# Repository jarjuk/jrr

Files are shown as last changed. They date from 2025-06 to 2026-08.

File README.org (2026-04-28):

* Nettiradio

* Valikkorakenne

#+name: plantuml2-wbs
#+BEGIN_SRC plantuml :eval no-export :exports results :file pics/jrr-menu.svg
 @startwbs
 ,* JRR
 ,**:== [[../pics-keep/screenshots/jrr-01-radio-stream.png Radio]]
 ==Näyttökentät==
,* Radiokanavan nimi
,* Radiokanavan ikoni
 ==Näppäin 1==
 ,**<U+2022><U+00A0><U+00A0>**: Seuraava radiokanava
 ,**<U+2014>** : Käynnistä asetusvalikko
 ==Näppäin 2==
 ,**<U+2022><U+00A0><U+00A0>**: Edellinen radiokanava
 ,**<U+2014>** : Ei käytössä;

,**: **Asetukset**
 ==Näppäin 1==
 ,**<U+2022><U+00A0><U+00A0>**: Seuraava valikko
 ,**<U+2014>** : Käynnistä valikkotoiminto
 ==Näppäin 2==
 ,**<U+2022><U+00A0><U+00A0>**: Edellinen valikkko
 ,**<U+2014>** : Palaa radion kuunteluun;

,***: **Poista kanavia**
 ==Näyttökentät==
,* Radiokanavan nimi
,* Radiokanavan ikoni
 ==Näppäin 1==
 ,**<U+2022><U+00A0><U+00A0>**: Seuraava radiokanava
 ,**<U+2014>** : Poista radiokanava
 ==Näppäin 2==
 ,**<U+2022><U+00A0><U+00A0>**: Edellinen radiokanava
 ,**<U+2014>** : Takaisin asetukset -valikkoon;

,***: **Aktivoi radiokanavia**
 ==Näyttökentät==
 ,* Radiokanavan nimi
 ,* Radiokanavan ikoni
 ==Näppäin 1==
 ,**<U+2022><U+00A0><U+00A0>**: Seuraava radiokanava
 ,**<U+2014>** : Aktivoi radiokanava
 ==Näppäin 2==
 ,**<U+2022>**: Edellinen radiokanava
 ,**<U+2014>** : Takaisin asetukset -valikkoon;

,***: **Valitse wifi verkko**
 ==Näyttökentät==
,* SSID: Wifi verkon SSID 
 ==Näppäin 1==
 ,**<U+2022><U+00A0><U+00A0>**: Seurava Wifi-verkko
 ,**<U+2014>** : Aktivoi Wifi-verkko
 ==Näppäin 2==
 ,**<U+2022><U+00A0><U+00A0>**: Edellinen Wifi-verkko
 ,**<U+2014>** : Takaisin asetukset -valikkoon;

,***: **Ohjelmistopäivitys**
 ==Näyttökentät==
,* Versio: Ohjelmistoversion tunniste
 ==Näppäin 1==
 ,**<U+2022><U+00A0><U+00A0>**: Seurava ohjelmistoversio
 ,**<U+2014>** : Valitse ohjelmistoversio
 ==Näppäin 2==
 ,**<U+2022><U+00A0><U+00A0>**: Edellinen ohjelmistoversio
 ,**<U+2014>** : Takaisin asetukset -valikkoon;

,****: **Ohjelmistopäivitys**
 ==Näyttökentät==
,* Versio: Ohjelmistoversion tunniste
 ==Näppäin 1==
 ,**<U+2022><U+00A0><U+00A0>**: 
 ,**<U+2014>** : Aloita päivitys
 ==Näppäin 2==
 ,**<U+2022><U+00A0><U+00A0>**
 ,**<U+2014>** : Takaisin asetukset -valikkoon;

,*****: **Uudelleen käynnistys**
 ==Näyttökentät==
,* Versio: Ohjelmistoversion tunniste
 ==Näppäin 1==
 ,**<U+2022><U+00A0><U+00A0>**: Ei käytössä
 ,**<U+2014>** : OK
 ==Näppäin 2==
 ,**<U+2022><U+00A0><U+00A0>**: Ei käytössä
 ,**<U+2014>**: Ei käytössä;

,***: **Asetukset näppäimistöllä**
----
Alivalikko ei aukea, jos
näppäimistöä ei ole kytketty 
;
,****: **Wifi-verkon valinta**
 ==Näyttökentät==
,* SSID: Wifi-verkon SSID 
 ==Näppäin 1==
 ,**<U+2022><U+00A0><U+00A0>**: Seuraava Wifi-verkko
 ,**<U+2014>** : Käynnistä Wifi -verkon asetus
 ==Näppäin 2==
 ,**<U+2022><U+00A0><U+00A0>**: Edellinen Wifi-verkko
 ,**<U+2014>** : Paluu asetusvalikkoon;
,*****: **Wifi-verkon asetus**
 ==Näyttökentät==
,* SSID: Valitun Wifi verkon SSID 
 ==Syöttökentät==
,* Password: Wifi verkon salasana
 ==Näppäin 1==
 ,**<U+2022><U+00A0><U+00A0>**: Eikäytössä
 ,**<U+2014>** : Aseta
 ==Näppäin 2==
 ,**<U+2022><U+00A0><U+00A0>**: Ei käytössä
 ,**<U+2014>** : Takaisin;
,****: **Radiokanavahakemiston asetus**
 ==Syöttökentät==
,* URL: Radiokanavahakemiston osoite (syöttökenttä)
 ==Näppäin 1==
 ,**<U+2022><U+00A0><U+00A0>**: Ei käytössä
 ,**<U+2014>** : Aseta
 ==Näppäin 2==
 ,**<U+2022><U+00A0><U+00A0>**: Ei käytössä
 ,**<U+2014>** : Takaisin;

,****: **Ohjelmistopäivityksen aloitus**
 ==Syöttökentät==
,* URL: Ohjelmistopäivityksen latausosoite
 ==Näppäin 1==
 ,**<U+2022><U+00A0><U+00A0>**: Ei käytössä
 ,**<U+2014>** : Valitse ohjelmistoversio
 ==Näppäin 2==
 ,**<U+2022><U+00A0><U+00A0>**: Ei käytössä
 ,**<U+2014>** : Paluu asetusvalikkoon;

,*****: **Ohjelmistoversion valinta ja käynnistys**
 ==Näyttökentät==
,* URL: Ohjelmistopäivityksen latausosoite
,* versio: Valittu ohjelmistoversio
 ==Näppäin 1==
 ,**<U+2022><U+00A0><U+00A0>**: Seuraava ohjelmistoversio
 ,**<U+2014>** : Käynnistä ohjelmistoversion päivitys
 ==Näppäin 2==
 ,**<U+2022><U+00A0><U+00A0>**: Edellinen ohjelmistoversio
 ,**<U+2014>** : Paluu asetusvalikkoon;

 @endwbs

#+END_SRC

#+RESULTS: plantuml2-wbs
[[file:pics/jrr-menu.svg]]

* Näytöt

** 1 - Radion kuuntelu

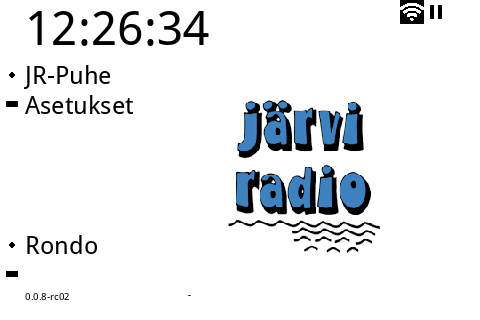
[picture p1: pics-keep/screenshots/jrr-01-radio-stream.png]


** 2 - Asetukset

*** 2.1 - Poista kanavia

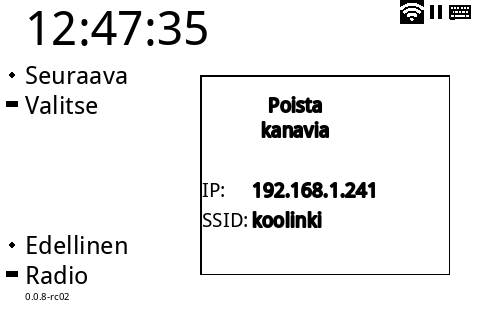
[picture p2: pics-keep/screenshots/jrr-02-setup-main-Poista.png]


*** 2.2 - Lisää kanavia

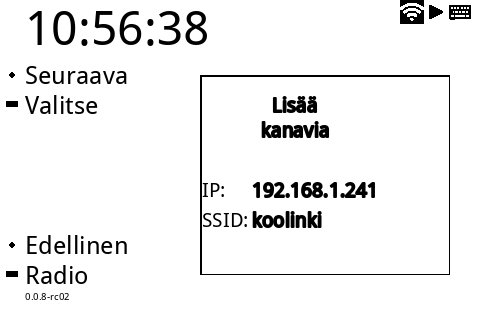
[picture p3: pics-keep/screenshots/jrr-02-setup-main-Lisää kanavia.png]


*** 2.3 - Valitse Wifi -verkko

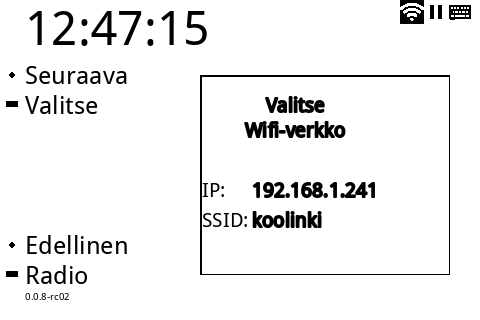
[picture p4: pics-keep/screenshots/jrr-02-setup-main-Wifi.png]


*** 2.4 - Asetukset näppämistöllä

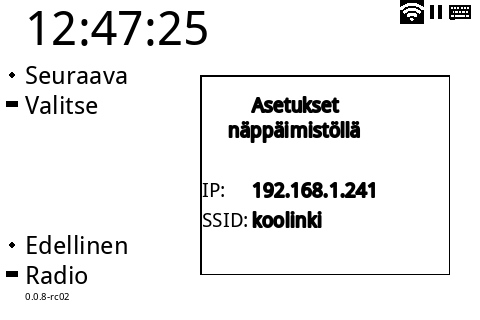
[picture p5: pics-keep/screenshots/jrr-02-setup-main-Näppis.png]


**** 2.4.1 - Wifi asetukset

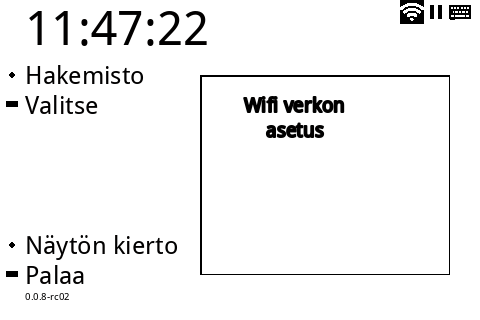
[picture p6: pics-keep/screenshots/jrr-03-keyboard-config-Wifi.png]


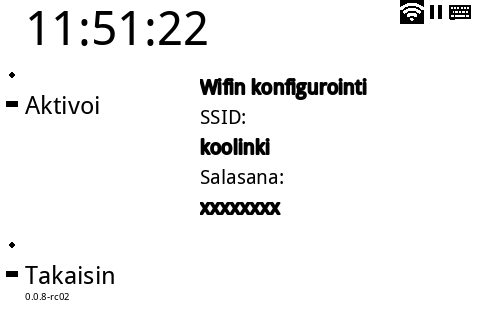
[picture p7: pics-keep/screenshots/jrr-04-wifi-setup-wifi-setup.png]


**** 2.4.2 - Radiokanavahakemiston asetukset

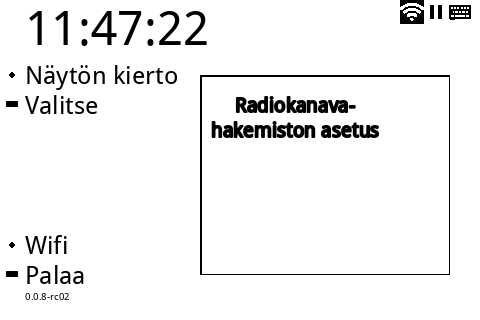
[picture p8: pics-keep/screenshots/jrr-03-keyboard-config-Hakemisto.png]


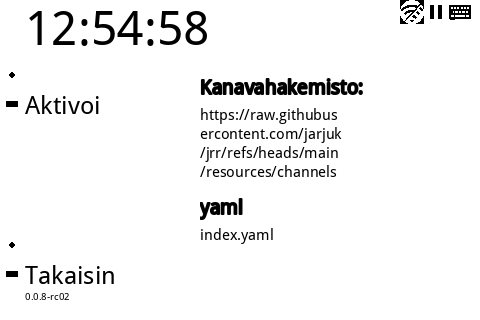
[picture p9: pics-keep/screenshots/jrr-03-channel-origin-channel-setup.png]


**** 2.4.x - Näytön kierto

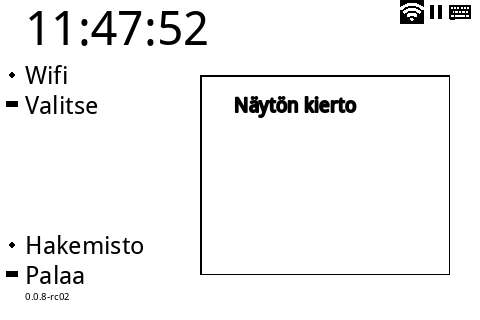
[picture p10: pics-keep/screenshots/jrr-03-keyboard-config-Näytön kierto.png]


*** 2.5. - Päivitä ohjelmistoversio

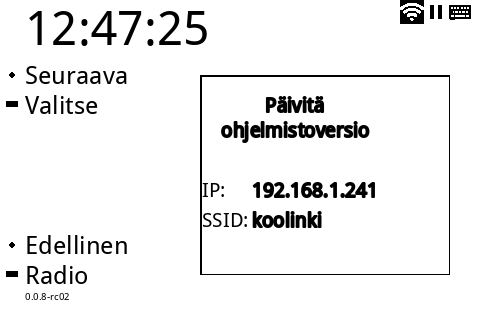
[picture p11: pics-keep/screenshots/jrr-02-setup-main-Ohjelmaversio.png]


*** 2.6. - Uudelleenkäynnistys

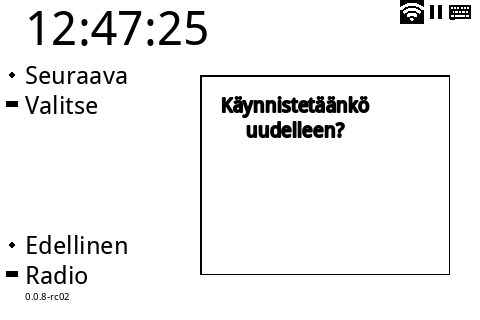
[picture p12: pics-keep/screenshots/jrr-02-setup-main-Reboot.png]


* Ohjelmistoversion palautus tehdasasetuksiin

- Paina molemmat painonapit alas ennen virtojen kytkemistä ja kytke virta radioon.

* Fin                                                              :noexport:

** Emacs variables

#+RESULTS:

# Local Variables:
# time-stamp-line-limit: -8
# time-stamp-start: "Modified:"
# time-stamp-format: "%:y-%02m-%02d.%02H:%02M"
# time-stamp-time-zone: nil
# time-stamp-end: "; # time-stamp"
# eval: (add-hook 'before-save-hook 'time-stamp)
# org-confirm-babel-evaluate: nil
# End:
#
# Muuta
# org-cdlatex-mode: t
# eval: (cdlatex-mode)
#
# Local ebib:
# org-ref-default-bibliography: "./README.bib"
# org-ref-bibliography-notes: "./README-notes.org"
# org-ref-pdf-directory: "./pdf/"
# org-ref-notes-directory: "."
# bibtex-completion-notes-path: "./README-notes.org"
# ebib-preload-bib-files: ("./README.bib")
# ebib-notes-file: ("./README-notes.org")
# reftex-default-bibliography: ("./README.bib")

Modified:2026-04-28.19:36; # time-stamp

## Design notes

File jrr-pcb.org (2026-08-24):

#+PROPERTY: header-args+ :var  DATA_SHEET_DIR="/home/jj/work/data-sheets/omat"
#+latex_compiler: pdflatex
#+LATEX_HEADER_EXTRA: \usepackage{rotfloat}
#+LATEX_HEADER_EXTRA: \usepackage{lmodern}
#+LATEX_HEADER: \hypersetup{colorlinks=true, linkcolor=blue}
#+LATEX_HEADER_EXTRA: \usepackage{tabularx}
#+LATEX_HEADER_EXTRA: \usepackage{tabu,longtable}
#+LATEX_HEADER_EXTRA: \usepackage{booktabs}
#+OPTIONS: ^:nil

* Design
** Requirements

- [-] Components
  - [-] Circuit board
    - [X] Connectors
      - [X] Power Input 5V-IN
	- [X] USB-C
	  - [X] usb-c power delivery resistor
	- [X] JST -header
      - [X] Fuse e-fuse (1.5A)
    - [X] RPI power delivery 5V
	- [X] Jumper for power deliver GPIO
	- [-] Wafer connectors  (e.g. for uUSB connector)
      - [X] 3.5 display connector 2x13
      - [ ] speaker output 
      - [X] Amplifier connectors
	- [X] power
	- [X] input signal
    - [X] button 1
    - [X] button 2
  - [-] VMA 408 amplifier breakout
    - [ ] pcb seat
      - [ ] screw hole for potentiometer
      - [ ] 4 corner holes 
    - [ ] shaft extension
    - [X] Amplifier pinhdeader
      - [X] Power input
      - [X] INput signal
      - [X] speaker output
  - [X] USB/3.5mm jack DAC
  - [X] power in
    - [X] Connectors
      - [X] USB-C power in
	- [X] Keystone inlet
      - [X] current controller resistors 5.1k x 2
      - [X] Pinheader power in
  - [ ] keyboard USB connector
    - [ ] Keystone inlet      
  - [X] power button
  - [-] Volume + on/off switch
    - [X] Pot set (pcb w. screw holes)
    - [ ] volume knob
  - [X] PLS-830986 speaker
  - [X] RCA input
    - [X] Keystone inlet
  - [-] 1P2T slide switch (RCA input/radio output)
    - [X] Keystone inlet
    - [ ] 3D printed seat
  - [ ] Cables (choose 1)
    - [ ] USB-C/JST
    - [ ] USB-C/USB-C cable (power cable)
  - [ ] polyester fibre 20g/l

** USB-C power

https://medium.com/@leung.benson/how-to-design-a-proper-usb-c-power-sink-hint-not-the-way-raspberry-pi-4-did-it-f470d7a5910

https://hackaday.com/2023/01/04/all-about-usb-c-resistors-and-emarkers/

** TRS audio connector

https://www.ranecommercial.com/legacy/note110.html

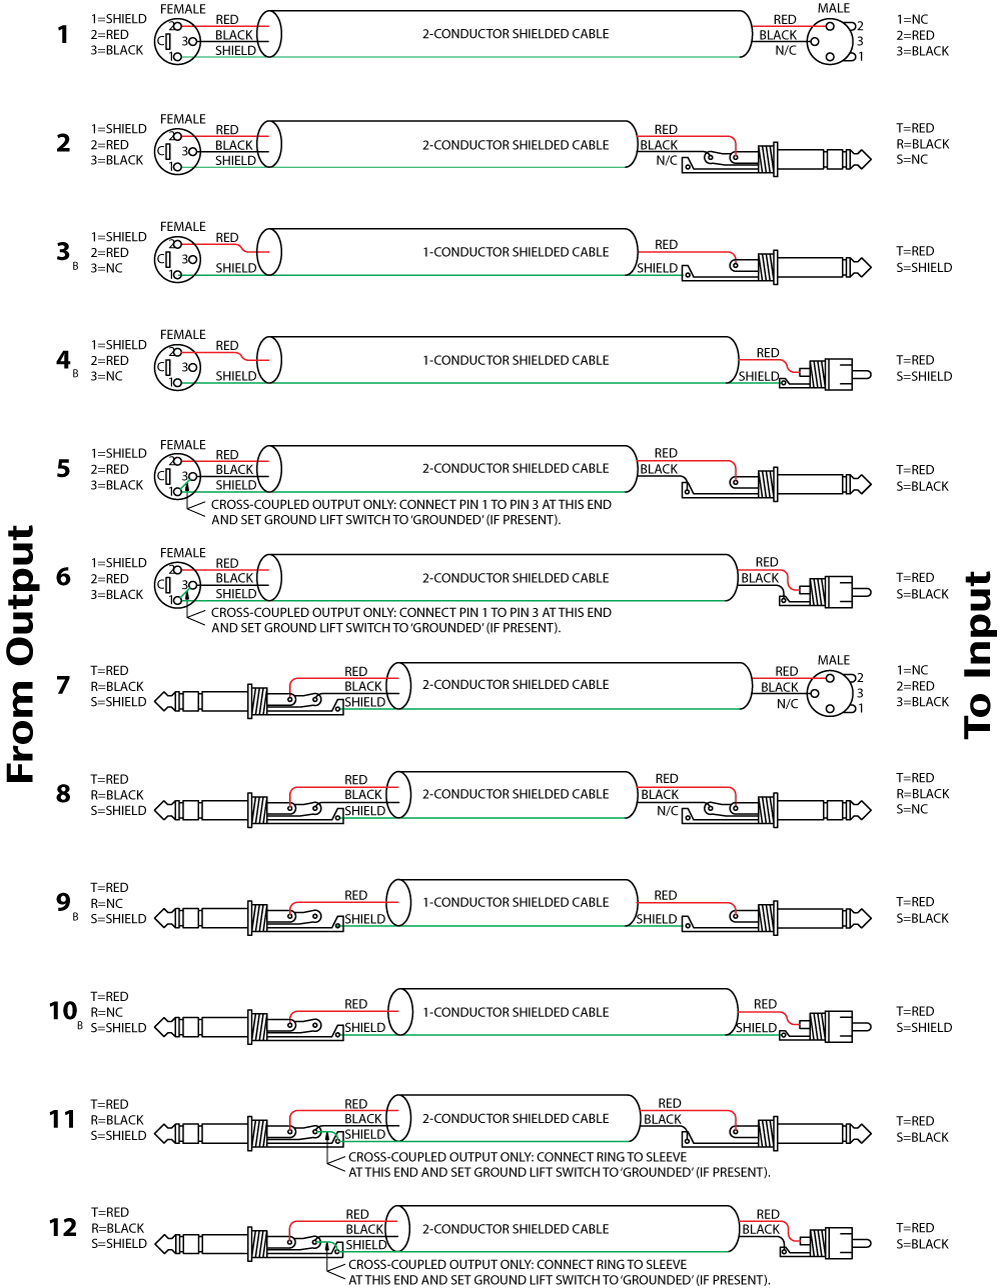
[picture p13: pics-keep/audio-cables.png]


| TSR-plug | Color  | Function      | Color | RCA-socket |
|----------+--------+---------------+-------+------------|
| T        | red    | signal        | red   | T          |
| R        | black  | signal ground | black | S          |
| S        | shield | shield        | NC    |            |

* Järviradio-radion piirilevy
:PROPERTIES:
:header-args+: :var  RELEASE="E"
:header-args+: :var  SCHEMA_ROOT="schema"
:header-args+: :var  SCHEMA_NAME="jrr5"
:header-args+: :var  DOC=(file-name-base (buffer-file-name))
:END:

** Piirilevyn skeema

    #+BEGIN_SRC bash :eval no-export :results output :exports results
    echo SCHEMA_ROOT=$SCHEMA_ROOT
    echo SCHEMA_NAME=$SCHEMA_NAME
    echo RELEASE=$RELEASE
    #+END_SRC

    #+RESULTS:
    : SCHEMA_ROOT=schema
    : SCHEMA_NAME=jrr5
    : RELEASE=E

    #+call:kicad-project()

    #+RESULTS:

    #+call: kicad-schema-pic()

    #+RESULTS:
    [[file:pics/jrr5.pdf]]

** Kotelon suunnittelu
*** Piirilevyn mitoitus

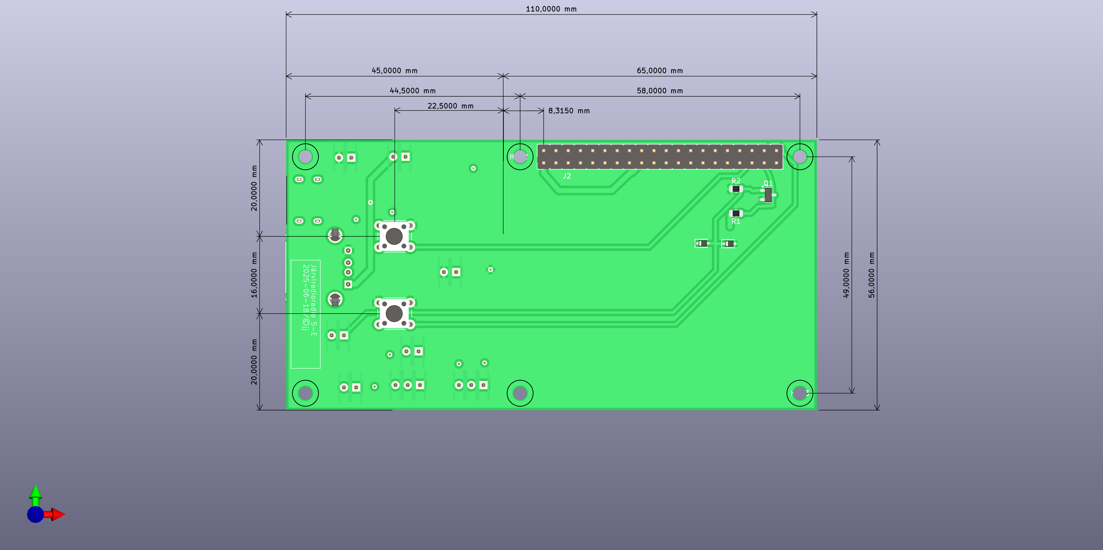
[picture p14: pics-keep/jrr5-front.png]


*** Painonappien etäisyys näyttöupotuksen reunoista

#+BEGIN_SRC octave :eval no-export :results output :session *Octave* :exports both

  mm = 1;

  pin2edge=8.315;
  edge2button = 22.5;

  hdr_slot_tol = 1+0.5;

  hdr_slot2button =  edge2button + pin2edge  - hdr_slot_tol

  #+END_SRC   

  #+RESULTS:
  : hdr_slot2button = 29.315

*** Kotelon katon aukot

[[file:cad/pages/katto.pdf]]

** PCB Layout

*** Front


*** Back



** BOM

#+call: kicad-bom(BOM_COLS="Reference,Value,Footprint,${QUANTITY}")

#+NAME: BOM
#+CAPTION: Järviradio PCB BOM
#+ATTR_LATEX: :float sideways :placement [H]
#+ATTR_LATEX: :font \tiny
#+HEADER: :exports results :results table latex :colnames yes
| Reference                    | Value                     | Footprint                                                  | QUANTITY |
|------------------------------+---------------------------+------------------------------------------------------------+----------|
| CONN1                        | 3.5m_TRS                  |                                                            |        1 |
| CONNN1                       | CONN-KSTONE-USBAfmxUSBAfm |                                                            |        1 |
| CONNN2                       | CONN-KSTONE-USBCfmxUSBCfm |                                                            |        1 |
| D1,D2                        | Schottky,15mA             | PCM_JLCPCB:D_SOD-323                                       |        2 |
| J2                           | Raspberry_Pi_2_3_GPIO     | Connector_PinHeader_2.54mm:PinHeader_2x20_P2.54mm_Vertical |        1 |
| J4                           | USB-Afm,THT               | Connector_USB:USB_A_Molex_67643_Horizontal                 |        1 |
| J11,J13,J19,J21,J24,J28,J101 | Wafer,1x2,m               | jj-foot:Wafer_1x02_P2.54mm_Vertical_male                   |        7 |
| J18,J26                      | Wafer,1x3,m               | jj-foot:Wafer_1x03_P2.54mm_Vertical_male                   |        2 |
| J107,J110                    | Wafer,1x2,fm              | Connector_PinHeader_2.54mm:PinHeader_1x02_P2.54mm_Vertical |        2 |
| J109                         | Wafer,1x3,fm              |                                                            |        1 |
| Q1                           | BSS138                    | Package_TO_SOT_SMD:SOT-23                                  |        1 |
| R1,R2                        | 10k                       | Resistor_SMD:R_0805_2012Metric                             |        2 |
| R3,R4                        | 5k1                       | Resistor_SMD:R_0805_2012Metric                             |        2 |
| SW1,SW2                      | SW_PUSH_THT_6mm           | Button_Switch_THT:SW_PUSH_6mm                              |        2 |

#+call: kicad-2d(LAYERS="Edge.Cuts,User.Drawings,F.Silkscreen,F.Fab,F.Paste", IMAGE_FILE="pics/jrr5-fab_f.png")

#+RESULTS:


#+call: kicad-2d(LAYERS="Edge.Cuts,User.Drawings,B.Silkscreen,B.Fab,B.Paste", IMAGE_FILE="pics/jrr5-fab_b.png")

#+RESULTS:


** Fab

#+BEGIN_SRC bash :eval no-export :results output
echo "Running in $(pwd) host '$(hostname)' on $(date)"
echo "SCHEMA_ROOT=$SCHEMA_ROOT"
echo "SCHEMA_NAME=$SCHEMA_NAME"
echo "RELEASE=$RELEASE"

#+END_SRC

#+RESULTS:
: Running in /home/jj/work/jrr host 'eero' on ma 7.7.2025 13.41.58 +0300
: SCHEMA_ROOT=schema
: SCHEMA_NAME=jrr5
: RELEASE=E

#+call: kicad-fab()

#+RESULTS:
#+begin_example
Running in /home/jj/work/jrr host 'eero' on ma 7.7.2025 13.53.40 +0300

Creating pdf for pcb layers in SCHEMA_NAME=jrr5

- LAYERS=B.Fab,Edge.Cuts,User.Comments,User.Drawings
- SCHEMA_ROOT=schema ('panels' or 'schema')
- PCB desing PCB_FILE=schema/jrr5/jrr5.kicad_pcb in PCB_DIR=schema/jrr5
- Images in IMAGE_PDF=pics/fab.pdf

Using IMAGE_DIR=
Loading board
Done OK
#+end_example

** Gerbers

#+BEGIN_SRC bash :eval no-export :results output
echo "Running in $(pwd) host '$(hostname)' on $(date)"
echo "SCHEMA_ROOT=$SCHEMA_ROOT"
echo "SCHEMA_NAME=$SCHEMA_NAME"
echo "RELEASE=$RELEASE"

#+END_SRC

#+RESULTS:
: Running in /home/jj/work/jrr host 'eero' on ma 23.6.2025 11.19.44 +0300
: SCHEMA_ROOT=schema
: SCHEMA_NAME=jrr5
: RELEASE=E

#+call: kicad-gerber()

#+RESULTS:
#+begin_example
Running in /home/jj/work/jrr host 'eero' on ma 23.6.2025 11.59.57 +0300

Creating gerber zip file ZIP_FILE=schema/jrr5/jrr5-E.zip for default SCHEMA_NAME=jrr5

- SCHEMA_ROOT=schema ('panels' or 'schema')
- PCB desing PCB_FILE=schema/jrr5/jrr5.kicad_pcb in PCB_DIR=schema/jrr5
- Gerbers in GERBER_DIR=schema/jrr5/gerber
- Zip file ZIP_FILE=schema/jrr5/jrr5-E.zip

Using GERBER_DIR=schema/jrr5/gerber
Loading board
Plotted to 'schema/jrr5/gerber/jrr5-F_Cu.gtl'.
Plotted to 'schema/jrr5/gerber/jrr5-B_Cu.gbl'.
Plotted to 'schema/jrr5/gerber/jrr5-F_Paste.gtp'.
Plotted to 'schema/jrr5/gerber/jrr5-B_Paste.gbp'.
Plotted to 'schema/jrr5/gerber/jrr5-F_Silkscreen.gto'.
Plotted to 'schema/jrr5/gerber/jrr5-B_Silkscreen.gbo'.
Plotted to 'schema/jrr5/gerber/jrr5-F_Mask.gts'.
Plotted to 'schema/jrr5/gerber/jrr5-B_Mask.gbs'.
Plotted to 'schema/jrr5/gerber/jrr5-User_Comments.gbr'.
Plotted to 'schema/jrr5/gerber/jrr5-Edge_Cuts.gm1'.
Loading board
Created file 'schema/jrr5/gerber/jrr5.drl'
Created file 'schema/jrr5/gerber/jrr5-drl_map.pdf'.
Done.
  adding: schema/jrr5/gerber/ (stored 0%)
  adding: schema/jrr5/gerber/jrr5-F_Paste.gtp (deflated 59%)
  adding: schema/jrr5/gerber/jrr5-B_Silkscreen.gbo (deflated 83%)
  adding: schema/jrr5/gerber/jrr5-drl_map.pdf (deflated 12%)
  adding: schema/jrr5/gerber/jrr5-B_Paste.gbp (deflated 65%)
  adding: schema/jrr5/gerber/jrr5-F_Mask.gts (deflated 72%)
  adding: schema/jrr5/gerber/jrr5-F_Cu.gtl (deflated 74%)
  adding: schema/jrr5/gerber/jrr5-B_Cu.gbl (deflated 75%)
  adding: schema/jrr5/gerber/jrr5.drl (deflated 65%)
  adding: schema/jrr5/gerber/jrr5-F_Silkscreen.gto (deflated 83%)
  adding: schema/jrr5/gerber/jrr5-Edge_Cuts.gm1 (deflated 39%)
  adding: schema/jrr5/gerber/jrr5-B_Mask.gbs (deflated 73%)
  adding: schema/jrr5/gerber/jrr5-User_Comments.gbr (deflated 67%)
  adding: schema/jrr5/gerber/jrr5-job.gbrjob (deflated 73%)
Done OK
#+end_example

** Release management
*** Releases

   |-----------+-----+-----------------+-----|
   |      Date | Rel | Comments        | PCB |
   |-----------+-----+-----------------+-----|
   |  4.2.2025 | C   | First version   | X   |
   | 19.2.2025 | D   | JRR-{1,2,3,4,5} | X   |
   |-----------+-----+-----------------+-----|

*** Release Issues

#+ATTR_LATEX: :font \tiny
   |--------+--------------+-----------+---------+------------------------------+------------------------------|
   | #      | In Rel       | Fixed rel | Ref     | As-is                        | Tobe                         |
   |--------+--------------+-----------+---------+------------------------------+------------------------------|
   | JRR-1  | C            | D         | F1      | 1.5A                         | 1.1A,SMD,polyfuse            |
   | JRR-2  | C            | D         | F1      |                              | 1812 footprint               |
   | JRR-3  | C            | D         | Q1      | drain 3 = GND, source 2= out | source 2 = GND, drain 3= out |
   | JRR-4  | C            | D         | Conn    | footprint pinhder            | wafer pinheader              |
   | JRR-5  | C            | D         | Edgecut | to righ                      | to left                      |
   | JRR-6  | D            |           | Q1      | BSS138->DMN3042L-7           |                              |
   | JRR-7  | D            | E         | Q1      |                              | schottky x 2                 |
   | JRR-8  | D            |           |         | +Mounting holes placement+   |                              |
   | JRR-9  | D            | E         |         | Silkscreen text              | Using macros                 |
   | JRR-10 | D            | E         | SW{1,2} | Push buttons to left 15 mm   |                              |
   | JRR-11 | E            |           | D1, D2  | pads too small               | +0.5 mm w, +.0.5 extend out  |
   | JRR-12 | E            |           | H{1-6}  | Hole diameter 2.5mm          | --> 4mm                      |
   | JRR-13 | 23.3./2026/E |           |         | Mounting holes too small     | M3.5mm                       |
   | JRR-14 | E            | F         | R1,R2   | 100k                         | 10k                          |
   | JRR-15 | E            |           | D1, D2  | Small pads                   | Increase pad size            |
   | JRR-16 | E            |           | D1, D2  | MPN missing                  | Add MNP                      |
   | JRR-17 | E            |           | F1      | 1.1A                         | 0.75A/PTS181213V075          |
   | JRR-18 | E            |           | J24     | Amp-power                    | on PCB edge                  |
   | JRR-19 | E            |           | C??     | 100uF Cap                    | on 5V-RPI/GND                |
   | JRR-20 | E            |           | Rxx     | <1R Resistro                 | on 5V-RPI                    |
   |--------+--------------+-----------+---------+------------------------------+------------------------------|

*** Deploy ~DATA_SHEET_DIR/DOC-RELEASE.pdf~                        :noexport:
  #+BEGIN_SRC bash :eval no-export :results output
  echo RELEASE=$RELEASE
  echo DATA_SHEET_DIR=$DATA_SHEET_DIR
  echo SCHEMA_NAME=$SCHEMA_NAME
  echo DOC=$DOC
  #+END_SRC

  #+RESULTS:
  : RELEASE=D
  : DATA_SHEET_DIR=/home/jj/work/data-sheets/omat
  : SCHEMA_NAME=jrr5
  : DOC=jrr5-pcb

  #+BEGIN_SRC bash :eval no-export :results output
  ls -ltr $DATA_SHEET_DIR/$DOC* ; true
  #+END_SRC

  #+RESULTS:
  : -rw-rw-r-- 1 jj jj 668631 helmi   6 15:00 /home/jj/work/data-sheets/omat/jrr5-pcb-jrr5-A.pdf
  : -rw-rw-r-- 1 jj jj 668631 helmi   6 15:02 /home/jj/work/data-sheets/omat/jrr5-pcb-jrr5-C.pdf
  : -rw-rw-r-- 1 jj jj 634648 helmi  19 10:05 /home/jj/work/data-sheets/omat/jrr5-pcb-jrr5-D.pdf

  Export to pdf
  #+BEGIN_SRC elisp
  (org-latex-export-to-pdf)
  #+END_SRC

  #+RESULTS:
  : /home/jj/work/järviradio-radio/jrr5-pcb.pdf

  Show pdf
  #+BEGIN_SRC bash :eval no-export :results output
  ls -ltr $DOC.pdf
  #+END_SRC

  #+RESULTS:
  : -rw-rw-r-- 1 jj jj 634648 helmi  19 10:05 jrr5-pcb.pdf

  Copy exported pdf as ~${RELEASE}~ -version to ~$DATA_SHEET_DIR~.
  #+BEGIN_SRC bash :eval no-export :results output file
  TARGET=$DATA_SHEET_DIR/${DOC}-${SCHEMA_NAME}-${RELEASE}.pdf
  cp $DOC.pdf $TARGET 
  echo -n $TARGET 
  #+END_SRC

  #+RESULTS:
  [[file:/home/jj/work/data-sheets/omat/jrr5-pcb-jrr5-D.pdf]]

  Datasheets installed into directory: 
  #+BEGIN_SRC bash :eval no-export :results output file :exports results
  echo -n $DATA_SHEET_DIR
  #+END_SRC

  #+RESULTS:
  [[file:/home/jj/work/data-sheets/omat]]

  #+BEGIN_SRC bash :eval no-export :results output
  ls -lt $DATA_SHEET_DIR/${DOC}-*.pdf $DOC.org   $DOC.pdf
  #+END_SRC

  #+RESULTS:
  : -rw-rw-r-- 1 jj jj  11287 helmi   6 15:02 jrr5-pcb.org
  : -rw-rw-r-- 1 jj jj 668631 helmi   6 15:02 /home/jj/work/data-sheets/omat/jrr5-pcb-jrr5-C.pdf
  : -rw-rw-r-- 1 jj jj 668631 helmi   6 15:02 jrr5-pcb.pdf
  : -rw-rw-r-- 1 jj jj 668631 helmi   6 15:00 /home/jj/work/data-sheets/omat/jrr5-pcb-jrr5-A.pdf

* Admin

** Kicad
*** ~kicad-bom~: Create bom table for SCHEMA_NAME

#+name: kicad-bom
#+BEGIN_SRC bash :eval no-export :results table :exports results :var SCHEMA_NAME="bolo-clock" SCHEMA_ROOT="schema" BOM_COLS="Reference,Value,Footprint,${QUANTITY}"
CSV_FILE=$SCHEMA_ROOT/$SCHEMA_NAME/$SCHEMA_NAME.csv

#           --filter '${EXCLUDE_FROM_BOM}' \

cat <<HERE >&2
Running in $(pwd) host '$(hostname)' on $(date)

Parameters
- BOM_COLS[comma serated list of columsn]=${BOM_COLS}

Output:
- CSV_FILE=$SCHEMA_ROOT/$SCHEMA_NAME/$SCHEMA_NAME.csv 
HERE

# --preset "Grouped By Value" \
#          --fields ${BOM_COLS} \
#          --exclude-dnp \

kicad-cli sch export bom \
          --output $CSV_FILE \
          --field-delimiter "|" \
          --string-delimiter "" \
          --group-by "Value" \
          --fields ${BOM_COLS} \
          schema/$SCHEMA_NAME/$SCHEMA_NAME.kicad_sch \
          >/dev/null # &2\
          
# echo '#+ATTR_LATEX: :font \tiny'
cat $CSV_FILE
#+END_SRC

#+RESULTS: kicad-bom

*** ~kicad-project~: Open project SCHEMA_NAME under SCHEMA_ROOT

    #+name: kicad-project
    #+BEGIN_SRC elisp :eval no-export :noweb yes :results output :eval no-export :exports none :var SCHEMA_ROOT="schema"
    (start-process "server" "buf-server" "kicad" (concat "schema/" SCHEMA_NAME "/" SCHEMA_NAME  ".kicad_pro"))
    #+END_SRC

*** ~kicad-schema~: Open schema designer SCHEMA_NAME under SCHEMA_ROOT

    #+name: kicad-schema
    #+BEGIN_SRC elisp :eval no-export :noweb yes :results output :eval no-export :exports none :var SCHEMA_ROOT="schema"
    (start-process "server" "buf-server" "eeschema" (concat "schema/" SCHEMA_NAME "/" SCHEMA_NAME  ".kicad_sch"))
    #+END_SRC

*** ~kicad-schema-pic~: Create schema pdf for SCHEMA_NAME under SCHEMA_ROOT

#+name: kicad-schema-pic
#+BEGIN_SRC bash :eval no-export :results file :var SCHEMA_ROOT="schema"
echo "Running in $(pwd) host '$(hostname)' on $(date)" >&2
echo "SCHEMA_ROOT=$SCHEMA_ROOT, SCHEMA_NAME=$SCHEMA_NAME" >&2
PDF_FILE=pics/$SCHEMA_NAME.pdf
          # --black-and-white \
kicad-cli sch export pdf \
          --output  $PDF_FILE \
          $SCHEMA_ROOT/$SCHEMA_NAME/$SCHEMA_NAME.kicad_sch >/dev/null

echo -n $PDF_FILE
#+END_SRC

*** ~kicad-gerber~: Create gerber zip for SCHEMA_NAME-RELEASE under SCHEMA_ROOT or

#+name: kicad-gerber
#+BEGIN_SRC bash :eval no-export :results output :var RELEASE="A" SCHEMA_ROOT="schema"
PCB_DIR=$SCHEMA_ROOT/$SCHEMA_NAME
PCB_FILE=$PCB_DIR/$SCHEMA_NAME.kicad_pcb
GERBER_DIR=$SCHEMA_ROOT/$SCHEMA_NAME/gerber
ZIP_FILE=$SCHEMA_ROOT/$SCHEMA_NAME/$SCHEMA_NAME-$RELEASE.zip
cat <<HERE
Running in $(pwd) host '$(hostname)' on $(date)

Creating gerber zip file ZIP_FILE=$ZIP_FILE for default SCHEMA_NAME=$SCHEMA_NAME

- SCHEMA_ROOT=$SCHEMA_ROOT ('panels' or 'schema')
- PCB desing PCB_FILE=$PCB_FILE in PCB_DIR=$PCB_DIR
- Gerbers in GERBER_DIR=$GERBER_DIR

HERE

if [ ! -d $GERBER_DIR ]; then
    echo No such directory GERBER_DIR=$GERBER_DIR - creating it
    mkdir -p $GERBER_DIR
fi

# cleanup
rm -f $GERBER_DIR/*
rm -f $ZIP_FILE

echo Using GERBER_DIR=$GERBER_DIR
kicad-cli pcb export gerbers \
          --output $GERBER_DIR \
          --layers 'F.Cu,B.Cu,F.Paste,B.Paste,F.Silkscreen,B.Silkscreen,F.Mask,B.Mask,Edge.Cuts,User.Comments' \
          $PCB_FILE
kicad-cli pcb export drill \
          --output $GERBER_DIR \
          --generate-map \
          $PCB_FILE
zip -r $ZIP_FILE $GERBER_DIR
echo Done OK
#+END_SRC

*** ~kicad-fab~: Create gerber zip for SCHEMA_NAME-RELEASE under SCHEMA_ROOT or

#+name: kicad-fab
#+BEGIN_SRC bash :eval no-export :results output :var RELEASE="A" SCHEMA_ROOT="schema"
PCB_DIR=$SCHEMA_ROOT/$SCHEMA_NAME
PCB_FILE=$PCB_DIR/$SCHEMA_NAME.kicad_pcb
LAYERS="B.Fab,Edge.Cuts,User.Comments,User.Drawings"
IMAGE_PDF=pics/fab.pdf
cat <<HERE
Running in $(pwd) host '$(hostname)' on $(date)

Creating pdf for pcb layers in SCHEMA_NAME=$SCHEMA_NAME

- LAYERS=$LAYERS
- SCHEMA_ROOT=$SCHEMA_ROOT ('panels' or 'schema')
- PCB desing PCB_FILE=$PCB_FILE in PCB_DIR=$PCB_DIR
- Images in IMAGE_PDF=$IMAGE_PDF

HERE

# cleanup

echo Using IMAGE_DIR=$IMAGE_DIR
kicad-cli pcb export pdf \
          --output $IMAGE_PDF \
          --layers $LAYERS \
          $PCB_FILE
echo Done OK
#+END_SRC

*** ~kicad-2d~: Create 2d image NAME for SCHEMA_ROOT/SCHEMA_NAME for LAYERS

#+name: kicad-2d
#+BEGIN_SRC bash :eval no-export :results output file :var LAYERS="Edge.Cuts,User.Drawings,F.Silkscreen,F.Fab,F.Paste" SCHEMA_ROOT="schema" SCHEMA_NAME="myclock" NAME=""
  echo "Running in $(pwd) host '$(hostname)' on $(date)" 1>&2
  SCHEMA_FILE=$SCHEMA_ROOT/$SCHEMA_NAME/$SCHEMA_NAME.kicad_pcb
  GERBER_FILE=pics/${SCHEMA_NAME}.grb
  [[ -z "$IMAGE_FILE" ]] && IMAGE_FILE=pics/${SCHEMA_NAME}${NAME:+-}${NAME:=}.png
  echo "LAYERS=$LAYERS" 1>&2
  echo "SCHEMA_ROOT=$SCHEMA_ROOT" 1>&2
  echo "SCHEMA_NAME=$SCHEMA_NAME" 1>&2
  echo "SCHEMA_FILE=$SCHEMA_FILE" 1>&2
  echo "IMAGE_FILE=$IMAGE_FILE" 1>&2

  kicad-cli pcb export gerber \
            --output $GERBER_FILE \
            --layers "$LAYERS" \
            $SCHEMA_FILE 1>&2

  gerbv \
      --dpi=600 \
      --border=0 \
      --export=png \
      --background=#FFFFFF --foreground=#000000 \
      --output=$IMAGE_FILE $GERBER_FILE
  echo -n $IMAGE_FILE
#+END_SRC

* Fin                                                              :noexport:

** Emacs variables

#+RESULTS:

# Local Variables:
# time-stamp-line-limit: -8
# time-stamp-start: "Modified:"
# time-stamp-format: "%:y-%02m-%02d.%02H:%02M"
# time-stamp-time-zone: nil
# time-stamp-end: "; # time-stamp"
# eval: (add-hook 'before-save-hook 'time-stamp)
# org-confirm-babel-evaluate: nil
# End:
#
# Muuta
# org-cdlatex-mode: t
# eval: (cdlatex-mode)
#
# Local ebib:
# org-ref-default-bibliography: "./jrr5-pcb.bib"
# org-ref-bibliography-notes: "./jrr5-pcb-notes.org"
# org-ref-pdf-directory: "./pdf/"
# org-ref-notes-directory: "."
# bibtex-completion-notes-path: "./jrr5-pcb-notes.org"
# ebib-preload-bib-files: ("./jrr5-pcb.bib")
# ebib-notes-file: ("./jrr5-pcb-notes.org")
# reftex-default-bibliography: ("./jrr5-pcb.bib")

Modified:2026-08-24.10:47; # time-stamp

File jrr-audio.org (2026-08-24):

* Suunnittelun lähtötiedot

[[https://loudspeakerdatabase.com/Simulators/ClosedBox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][Loudspeakerdatabase suunnnitelma]]

* Mittausjärjestelyt

** Mittauskohteet

- jrr5x1.local
  - Kaiutinelementti: [[file:bom/peerless-830986.pdf][PLS-P830986]]
  - DA-muunnin: Realtek ALC5686
  - Vahvistin: PAM8403-GF1002 2x3W [[https://uraltone.com/vahvistinmoduli-pam8403-class-d-2x3w.html][Uraltone 190-PAM8403-2x3W-AMP]]
  - suljettu kotelo LxKxS: 232mm x x 138mm xx 138mm 19mm MDF
  - n. 10mm vanu kotelon sisällä
- jrr5x.local
  - Kaiutinelementti: [[file:bom/peerless-830986.pdf][PLS-P830986]] 
  - Vahvistin: PAM8403-GF1002 2x3W [[https://uraltone.com/vahvistinmoduli-pam8403-class-d-2x3w.html][Uraltone 190-PAM8403-2x3W-AMP]]
  - DA-muunnin: Realtek ALC5686
  - suljettu kotelo LxKxS: 232mm x x 138mm xx 138mm 19mm MDF
- jrr4.local
  - Kaiutinelementti: [[file:bom/peerless-830986.pdf][PLS-P830986]] 
  - DA-muunnin: Raspberry Pi 3B+ 3.5mm audio jack PWM
  - Vahvistin: Velleman VMA408 (PAM8403)
  - suljettu kotelo LxKxS: 232mm x x 138mm xx 138mm 19mm MDF

** Mittausympäristö
- Mikrofoni T-Bone SC 400
  - Käyttöohje: [[file:bom/t-bone-sc400-microphone.pdf]]
  - n. 10 cm suoraan kaiuttimien edessä
- Äänikortti: Behringer UMC202HD
  - 2x2, 24-Bit/192 kH
  - Kotisivu: https://www.behringer.com/en/products/0805-AAR
  - Pikaohje: [[file:bom/Behringer-U-PHORIA-Series_WW.pdf]]
- Analyysohjelmisto REW
  - Versio 5.31.3, JRE 1.8.0_422 64-bit on linx 6.17.0-1028-oem

* Mittaukset

** jrr4
:PROPERTIES:
:header-args+: :var  AUDIO_TARGET_SSH="pi@jrr4.local"
:header-args+:   :dir  /ssh:pi@jrr4.local:
:END:

*** Testiympäristön alustus
#+BEGIN_SRC bash :eval no-export :results output
echo "Running in $(pwd) for user '$(whoami)' on host '$(hostname)' on $(date)"
echo AUDIO_TARGET_SSH=$AUDIO_TARGET_SSH
#+END_SRC

#+RESULTS:
: Running in /home/pi for user 'pi' on host 'jrr4' on Mon Jul 27 09:44:14 EEST 2026
: AUDIO_TARGET_SSH=pi@jrr4.local

#+call: create-dir(DIR="tmp")

#+RESULTS:
: Create DIR=tmp in /home/pi for user 'pi' on host='jrr4' on Mon Jul 27 09:45:31 EEST 2026
: Directory tmp already exists

Kopioidaa audio tiedostot
#+call: audio-analysis-copy[:dir .](AUDIO_FILE="audio/*")

#+RESULTS:
: Running in /home/jj/work/jrr for user 'jj' on host 'Leo' on ma 27.7.2026 09.47.21 +0300

Kohdejärjestelmässä olevat äänitiedostot
#+call: audio-analysis-playable()

#+RESULTS:
#+begin_example
Running in /home/pi for user 'pi' on host 'jrr4' on Mon Jul 27 09:48:04 EEST 2026
-rw-r--r-- 1 pi pi 4718636 Jul 27 09:47 tmp/256kMeasSweep_100_to_15000_-12_dBFS_48k_Float_LR_refL.wav
-rw-r--r-- 1 pi pi 4718636 Jul 27 09:47 tmp/256kMeasSweep_100_to_20000_-12_dBFS_48k_Float_LR_refL.wav
-rw-r--r-- 1 pi pi 4718636 Jul 27 09:47 tmp/256kMeasSweep_100_to_5000_-12_dBFS_48k_Float_LR_refL.wav
-rw-r--r-- 1 pi pi 4718636 Jul 27 09:47 tmp/256kMeasSweep_20_to_20000_-12_dBFS_48k_Float_LR_refL.wav
-rw-r--r-- 1 pi pi 4718636 Jul 27 09:47 tmp/256kMeasSweep_50_to_20000_-12_dBFS_48k_Float_LR_refL.wav
-rw-r--r-- 1 pi pi 3840044 Jul 27 09:47 tmp/LinSwp_10_20000_-12_dBFS_48k_Float_LR.wav
-rw-r--r-- 1 pi pi 3840044 Jul 27 09:47 tmp/Sine_1000_-12_dBFS_48k_Float_LR.wav
-rw-r--r-- 1 pi pi 3840044 Jul 27 09:47 tmp/Sine_100_-12_dBFS_48k_Float_LR.wav
-rw-r--r-- 1 pi pi 3840044 Jul 27 09:47 tmp/Sine_200_-12_dBFS_48k_Float_LR.wav
-rw-r--r-- 1 pi pi 3840044 Jul 27 09:47 tmp/Sine_30_-12_dBFS_48k_Float_LR.wav
-rw-r--r-- 1 pi pi 3840044 Jul 27 09:47 tmp/Sine_500_-12_dBFS_48k_Float_LR.wav
-rw-r--r-- 1 pi pi 3840044 Jul 27 09:47 tmp/Sine_50_-12_dBFS_48k_Float_LR.wav
-rw-r--r-- 1 pi pi 3840044 Jul 27 09:47 tmp/Sine_75_-12_dBFS_48k_Float_LR.wav
#+end_example

Pysäytetään streamaus palvelus

#+BEGIN_SRC bash :eval no-export :results output
echo "Running in $(pwd) for user '$(whoami)' on host '$(hostname)' on $(date)"
# jrr-control.sh stop
runner/jrr-control.sh stop
#+END_SRC

#+RESULTS:
: Running in /home/pi for user 'pi' on host 'jrr4' on Tue Jul 28 09:03:14 EEST 2026

*** Linear sweep 20Hz-20kHz -12dBFS 48k LR
:PROPERTIES:
:header-args+: :var  AUDIO_FILE="audio/256kMeasSweep_20_to_20000_-12_dBFS_48k_Float_LR_refL.wav"
:END:

#+BEGIN_SRC bash :eval no-export :results output
echo "Running in $(pwd) for user '$(whoami)' on host '$(hostname)' on $(date)"
echo "AUDIO_FILE=$AUDIO_FILE"
#+END_SRC

#+RESULTS:
: Running in /home/pi for user 'pi' on host 'jrr4' on Mon Jul 27 10:14:09 EEST 2026
: AUDIO_FILE=audio/256kMeasSweep_20_to_20000_-12_dBFS_48k_Float_LR_refL.wav

#+call: vlc-play()

#+RESULTS:
: Running in /home/pi for user 'pi' on host 'jrr4' on Mon Jul 27 10:19:26 EEST 2026
: AUDIO_FILE_TO_PLAY=tmp/256kMeasSweep_20_to_20000_-12_dBFS_48k_Float_LR_refL.wav
: cvlc --play-and-exit tmp/256kMeasSweep_20_to_20000_-12_dBFS_48k_Float_LR_refL.wav
: VLC media player 3.0.10 Vetinari (revision 3.0.10-0-g7f145afa84)
: [[32;1m00d010d0[0m] main interface error: [31;1mno suitable interface module[0m
: [[32;1m00c7a6c0[0m] main libvlc error: [31;1minterface "globalhotkeys,none" initialization failed[0m
: [[32;1m00d010d0[0m] dummy interface: [0;1musing the dummy interface module...[0m
: [[32;1m00ce5268[0m] main playlist: [0;1mend of playlist, exiting[0m

*** SPL

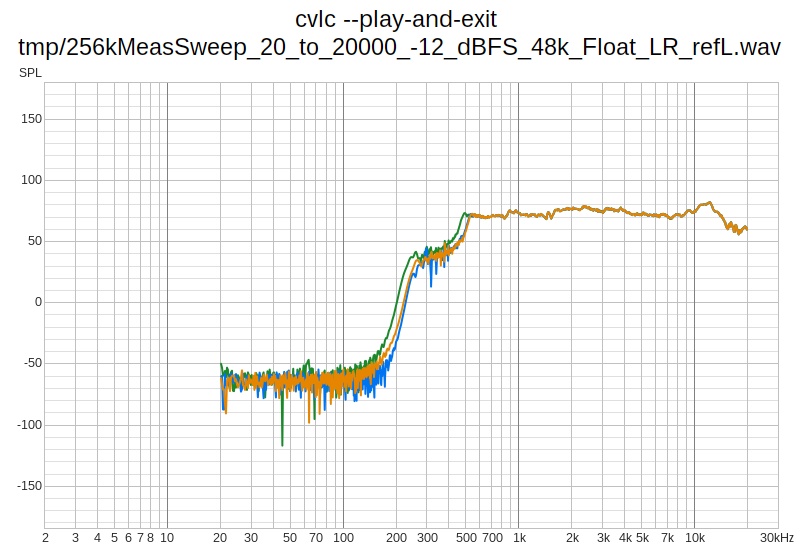
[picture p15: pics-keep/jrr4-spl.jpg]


*** Distortion

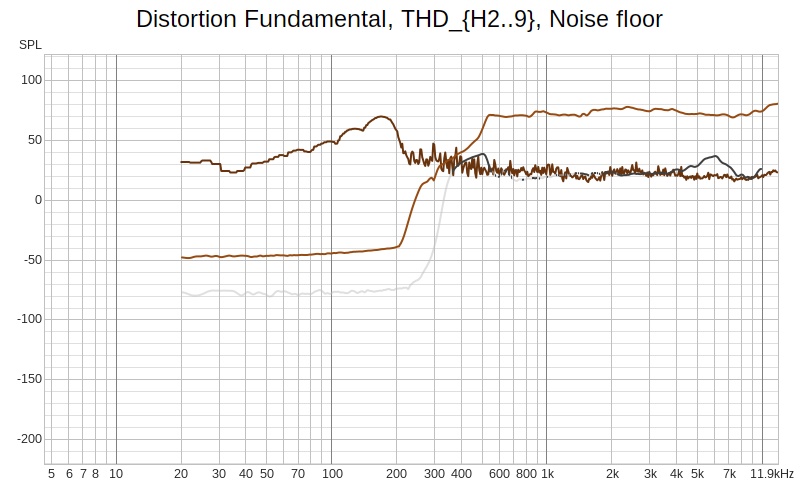
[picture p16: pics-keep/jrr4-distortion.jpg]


** jrr5x1
:PROPERTIES:
:header-args+: :var  AUDIO_TARGET_SSH="jrr@jrr5x1.local"
:header-args+:   :dir  /ssh:jrr@jrr5x1.local:
:END:

*** Testiympäristön alustus
#+BEGIN_SRC bash :eval no-export :results output
echo "Running in $(pwd) for user '$(whoami)' on host '$(hostname)' on $(date)"
echo AUDIO_TARGET_SSH=$AUDIO_TARGET_SSH
#+END_SRC

#+RESULTS:
: Running in /home2/jrr for user 'jrr' on host 'jrr5x1' on Mon Jul 27 10:30:11 EEST 2026
: AUDIO_TARGET_SSH=jrr@jrr5x1.local

#+call: create-dir(DIR="tmp")

#+RESULTS:
: Create DIR=tmp in /home2/jrr for user 'jrr' on host='jrr5x1' on Mon Jul 27 10:30:28 EEST 2026
: Directory tmp already exists

Kopioidaan audio tiedostot mittauskohteeseen
#+call: audio-analysis-copy[:dir .](AUDIO_FILE="audio/*.wav")

#+RESULTS:
: Running in /home/jj/work/jrr for user 'jj' on host 'Leo' on ma 27.7.2026 10.35.01 +0300

Kohdejärjestelmässä olevat äänitiedostot
#+call: audio-analysis-playable()

#+RESULTS:
#+begin_example
Running in /home2/jrr for user 'jrr' on host 'jrr5x1' on Mon Jul 27 10:35:13 EEST 2026
-rw-rw-r-- 1 jrr jrr 4718636 Jul 27 10:30 tmp/256kMeasSweep_100_to_15000_-12_dBFS_48k_Float_LR_refL.wav
-rw-rw-r-- 1 jrr jrr 4718636 Jul 27 10:30 tmp/256kMeasSweep_100_to_20000_-12_dBFS_48k_Float_LR_refL.wav
-rw-rw-r-- 1 jrr jrr 4718636 Jul 27 10:30 tmp/256kMeasSweep_100_to_5000_-12_dBFS_48k_Float_LR_refL.wav
-rw-rw-r-- 1 jrr jrr 4718636 Jul 27 10:30 tmp/256kMeasSweep_20_to_20000_-12_dBFS_48k_Float_LR_refL.wav
-rw-rw-r-- 1 jrr jrr 4718636 Jul 27 10:30 tmp/256kMeasSweep_50_to_20000_-12_dBFS_48k_Float_LR_refL.wav
-rw-rw-r-- 1 jrr jrr 3840044 Jul 27 10:30 tmp/LinSwp_10_20000_-12_dBFS_48k_Float_LR.wav
-rw-rw-r-- 1 jrr jrr 3840044 Jul 27 10:30 tmp/Sine_1000_-12_dBFS_48k_Float_LR.wav
-rw-rw-r-- 1 jrr jrr 3840044 Jul 27 10:30 tmp/Sine_100_-12_dBFS_48k_Float_LR.wav
-rw-rw-r-- 1 jrr jrr 3840044 Jul 27 10:30 tmp/Sine_200_-12_dBFS_48k_Float_LR.wav
-rw-rw-r-- 1 jrr jrr 3840044 Jul 27 10:30 tmp/Sine_30_-12_dBFS_48k_Float_LR.wav
-rw-rw-r-- 1 jrr jrr 3840044 Jul 27 10:30 tmp/Sine_500_-12_dBFS_48k_Float_LR.wav
-rw-rw-r-- 1 jrr jrr 3840044 Jul 27 10:30 tmp/Sine_50_-12_dBFS_48k_Float_LR.wav
-rw-rw-r-- 1 jrr jrr 3840044 Jul 27 10:30 tmp/Sine_75_-12_dBFS_48k_Float_LR.wav
#+end_example

*** Pysäytetään streamaus palvelus

#+call: jrr-where()

#+RESULTS:
: Running in /home2/jrr for user 'jrr' host 'jrr5x1' on Tue Jul 28 09:31:29 EEST 2026

Stop jrr -service
#+call: jrr-stop()

#+RESULTS:
: Running in /home2/jrr for user 'jrr' host 'jrr5x1' on Tue Jul 28 09:31:32 EEST 2026
: 'jrr' runs '/home2/jrr/jrr/bin/jrr.sh stop' on 'jrr5x1:/home2/jrr'
: do_stop: no jrr.py process found

*** Linear sweep 20Hz-20kHz -12dBFS 48k LR
:PROPERTIES:
:header-args+: :var  AUDIO_FILE="audio/256kMeasSweep_20_to_20000_-12_dBFS_48k_Float_LR_refL.wav"
:END:

#+BEGIN_SRC bash :eval no-export :results output
echo "Running in $(pwd) for user '$(whoami)' on host '$(hostname)' on $(date)"
echo "AUDIO_FILE=$AUDIO_FILE"
#+END_SRC

#+RESULTS:
: Running in /home2/jrr for user 'jrr' on host 'jrr5x1' on Mon Jul 27 10:37:37 EEST 2026
: AUDIO_FILE=audio/256kMeasSweep_20_to_20000_-12_dBFS_48k_Float_LR_refL.wav

#+call: audio-analysis-play()

#+RESULTS:
#+begin_example
Running in /home2/jrr for user 'jrr' on host 'jrr5x1' on Mon Jul 27 10:40:01 EEST 2026
20260727-10:40:02: jrr/src/jrr_streamer.sh|init_ALSA_CARD: starting with ALSA_CARD=''
20260727-10:40:02: jrr/src/jrr_streamer.sh|init_ALSA_CARD: done with ALSA_CARD='Audio '
20260727-10:40:02: jrr/src/jrr_streamer.sh|set_alsa_volume: card=Audio , volume=95%
Simple mixer control 'Headphone',0
  Capabilities: pvolume pswitch pswitch-joined
  Playback channels: Front Left - Front Right
  Limits: Playback 0 - 175
  Mono:
  Front Left: Playback 166 [95%] [-3.38dB] [on]
  Front Right: Playback 166 [95%] [-3.38dB] [on]
Running in host 'jrr5x1' on Mon Jul 27 10:40:02 EEST 2026
20260727-10:40:02: jrr/src/jrr_streamer.sh|AUDIO_OUT=hw:CARD=Audio,DEV=0, URL=tmp/256kMeasSweep_20_to_20000_-12_dBFS_48k_Float_LR_refL.wav, GAIN=1.5
+ ffmpeg -hide_banner -nostdin -nostats -loglevel error -i tmp/256kMeasSweep_20_to_20000_-12_dBFS_48k_Float_LR_refL.wav -filter_complex '[0:a]volume=volume=1.5,pan=mono|c0=0.5*c0+0.5*c1,alimiter[aout]' -map '[aout]' -ac 2 -f alsa hw:CARD=Audio,DEV=0
#+end_example

#+call: audio-analysis-ffmpeg()

#+RESULTS:
: Running in /home2/jrr for user 'jrr' on host 'jrr5x1' on Mon Jul 27 11:15:25 EEST 2026
: CMD=ffmpeg -hide_banner -nostdin -nostats -loglevel error -i tmp/256kMeasSweep_20_to_20000_-12_dBFS_48k_Float_LR_refL.wav -f alsa hw:CARD=Audio,DEV=0

** jrr5x
:PROPERTIES:
:header-args+: :var  AUDIO_TARGET_SSH="jrr@jrr5x.local"
:header-args+:   :dir  /ssh:jrr@jrr5x.local:
:END:

*** Testiympäristön alustus
#+BEGIN_SRC bash :eval no-export :results output
echo "Running in $(pwd) for user '$(whoami)' on host '$(hostname)' on $(date)"
echo AUDIO_TARGET_SSH=$AUDIO_TARGET_SSH
#+END_SRC

#+RESULTS:
: Running in /home2/jrr for user 'jrr' on host 'jrr5x' on Mon Jul 27 10:56:55 EEST 2026
: AUDIO_TARGET_SSH=jrr@jrr5x.local

#+call: create-dir(DIR="tmp")

#+RESULTS:
: Create DIR=tmp in /home2/jrr for user 'jrr' on host='jrr5x' on Mon Jul 27 10:57:00 EEST 2026
: Directory tmp already exists

Kopioidaan audio tiedostot mittauskohteeseen
#+call: audio-analysis-copy[:dir .](AUDIO_FILE="audio/*.wav")

#+RESULTS:
: Running in /home/jj/work/jrr for user 'jj' on host 'Leo' on ma 27.7.2026 10.58.47 +0300

Kohdejärjestelmässä olevat äänitiedostot
#+call: audio-analysis-playable()

#+RESULTS:
#+begin_example
Running in /home2/jrr for user 'jrr' on host 'jrr5x' on Mon Jul 27 10:59:03 EEST 2026
-rw-rw-r-- 1 jrr jrr 4718636 Jul 27 10:58 tmp/256kMeasSweep_100_to_15000_-12_dBFS_48k_Float_LR_refL.wav
-rw-rw-r-- 1 jrr jrr 4718636 Jul 27 10:58 tmp/256kMeasSweep_100_to_20000_-12_dBFS_48k_Float_LR_refL.wav
-rw-rw-r-- 1 jrr jrr 4718636 Jul 27 10:58 tmp/256kMeasSweep_100_to_5000_-12_dBFS_48k_Float_LR_refL.wav
-rw-rw-r-- 1 jrr jrr 4718636 Jul 27 10:58 tmp/256kMeasSweep_20_to_20000_-12_dBFS_48k_Float_LR_refL.wav
-rw-rw-r-- 1 jrr jrr 4718636 Jul 27 10:58 tmp/256kMeasSweep_50_to_20000_-12_dBFS_48k_Float_LR_refL.wav
-rw-rw-r-- 1 jrr jrr 3840044 Jul 27 10:58 tmp/LinSwp_10_20000_-12_dBFS_48k_Float_LR.wav
-rw-rw-r-- 1 jrr jrr 3840044 Jul 27 10:58 tmp/Sine_1000_-12_dBFS_48k_Float_LR.wav
-rw-rw-r-- 1 jrr jrr 3840044 Jul 27 10:58 tmp/Sine_100_-12_dBFS_48k_Float_LR.wav
-rw-rw-r-- 1 jrr jrr 3840044 Jul 27 10:58 tmp/Sine_200_-12_dBFS_48k_Float_LR.wav
-rw-rw-r-- 1 jrr jrr 3840044 Jul 27 10:58 tmp/Sine_30_-12_dBFS_48k_Float_LR.wav
-rw-rw-r-- 1 jrr jrr 3840044 Jul 27 10:58 tmp/Sine_500_-12_dBFS_48k_Float_LR.wav
-rw-rw-r-- 1 jrr jrr 3840044 Jul 27 10:58 tmp/Sine_50_-12_dBFS_48k_Float_LR.wav
-rw-rw-r-- 1 jrr jrr 3840044 Jul 27 10:58 tmp/Sine_75_-12_dBFS_48k_Float_LR.wav
#+end_example

*** Pysäytetään streamaus palvelus

#+call: jrr-where()

#+RESULTS:
: Running in /home2/jrr for user 'jrr' host 'jrr5x' on Tue Jul 28 10:10:46 EEST 2026

Stop jrr -service
#+call: jrr-stop()

#+RESULTS:
: Running in /home2/jrr for user 'jrr' host 'jrr5x' on Tue Jul 28 10:10:49 EEST 2026
: 'jrr' runs '/home2/jrr/jrr/bin/jrr.sh stop' on 'jrr5x:/home2/jrr'
: do_stop: no jrr.py process found

*** Linear sweep 20Hz-20kHz -12dBFS 48k LR
:PROPERTIES:
:header-args+: :var  AUDIO_FILE="audio/256kMeasSweep_20_to_20000_-12_dBFS_48k_Float_LR_refL.wav"
:END:

#+BEGIN_SRC bash :eval no-export :results output
echo "Running in $(pwd) for user '$(whoami)' on host '$(hostname)' on $(date)"
echo "AUDIO_FILE=$AUDIO_FILE"
#+END_SRC

#+RESULTS:
: Running in /home2/jrr for user 'jrr' on host 'jrr5x' on Mon Jul 27 10:59:26 EEST 2026
: AUDIO_FILE=audio/256kMeasSweep_20_to_20000_-12_dBFS_48k_Float_LR_refL.wav

#+call: audio-analysis-play()

#+RESULTS:
#+begin_example
Running in /home2/jrr for user 'jrr' on host 'jrr5x' on Mon Jul 27 10:59:32 EEST 2026
20260727-10:59:32: jrr/src/jrr_streamer.sh|init_ALSA_CARD: starting with ALSA_CARD=''
20260727-10:59:32: jrr/src/jrr_streamer.sh|init_ALSA_CARD: done with ALSA_CARD='Audio '
20260727-10:59:32: jrr/src/jrr_streamer.sh|set_alsa_volume: card=Audio , volume=95%
Simple mixer control 'Headphone',0
  Capabilities: pvolume pswitch pswitch-joined
  Playback channels: Front Left - Front Right
  Limits: Playback 0 - 175
  Mono:
  Front Left: Playback 166 [95%] [-3.38dB] [on]
  Front Right: Playback 166 [95%] [-3.38dB] [on]
Running in host 'jrr5x' on Mon Jul 27 10:59:32 EEST 2026
20260727-10:59:32: jrr/src/jrr_streamer.sh|AUDIO_OUT=hw:CARD=Audio,DEV=0, URL=tmp/256kMeasSweep_20_to_20000_-12_dBFS_48k_Float_LR_refL.wav, GAIN=1.5
+ ffmpeg -hide_banner -nostdin -nostats -loglevel error -i tmp/256kMeasSweep_20_to_20000_-12_dBFS_48k_Float_LR_refL.wav -filter_complex '[0:a]volume=volume=1.5,pan=mono|c0=0.5*c0+0.5*c1,alimiter[aout]' -map '[aout]' -ac 2 -f alsa hw:CARD=Audio,DEV=0
#+end_example

#+call: audio-analysis-ffmpeg()

#+RESULTS:
: Running in /home2/jrr for user 'jrr' on host 'jrr5x' on Tue Jul 28 10:11:41 EEST 2026
: CMD=ffmpeg -hide_banner -nostdin -nostats -loglevel error -i tmp/256kMeasSweep_20_to_20000_-12_dBFS_48k_Float_LR_refL.wav -f alsa hw:CARD=Audio,DEV=0

* Yhteenveto
** ~jrr5x1~: chatgpt analysis
Knowing the hardware changes the interpretation quite a bit. This now
looks less like a generic loudspeaker measurement and more like a
*small, cost-optimized active desktop speaker*, and judged against that
target I'd say the results are surprisingly good.

*** Driver: Peerless PLS-P830986 (3” full-range)
:PROPERTIES:
:CUSTOM_ID: driver-peerless-pls-p830986-3-full-range
:END:
The P830986 is a well-regarded 3” full-range driver. Its strengths are:

- Smooth midrange
- Good dispersion
- Low distortion for its size
- Extended treble without a tweeter

Its limitations are exactly what your measurements show:

- Limited bass displacement
- Rapid LF rolloff in small sealed boxes
- Some breakup/resonance in the upper midrange/lower treble

The ridge around 3--4 kHz immediately caught my attention before
knowing the driver.

For this Peerless driver that region is completely believable and
probably intrinsic to the cone rather than the enclosure. It's also
fairly modest.

I would not attempt aggressive EQ there unless listening tests
consistently indicate excessive brightness.

*** Enclosure
:PROPERTIES:
:CUSTOM_ID: enclosure
:END:
You listed

#+begin_quote
232 × 138 × 138 mm

19 mm MDF

#+end_quote

Assuming outside dimensions:

Internal dimensions become roughly

194 × 100 × 100 mm

which is about *1.9 liters*

after subtracting wall thickness.

That's almost exactly the kind of enclosure this driver expects.

*** Bass
:PROPERTIES:
:CUSTOM_ID: bass
:END:
The gradual rise toward 200 Hz is exactly what I'd expect from:

- 3” driver
- ~2 L enclosure
- probably sealed

There isn't evidence of a badly tuned box.

Instead, it looks like normal physics.

If sealed, I'd expect an F3 somewhere around 120--150 Hz.

That matches the graph remarkably well.

*** Amplifier: PAM8403
:PROPERTIES:
:CUSTOM_ID: amplifier-pam8403
:END:
The PAM8403 is often criticized because it's inexpensive, but within its
limits it's actually quite competent.

*** A few observations:

**** Power
:PROPERTIES:
:CUSTOM_ID: power
:END:
With a 3” driver:

3 W/channel is actually plenty.

The driver will reach excursion limits before amplifier clipping for
most near-field use.

**** Distortion
:PROPERTIES:
:CUSTOM_ID: distortion
:END:
Your distortion plot doesn't suggest the amplifier is causing problems.

If the PAM8403 were clipping or oscillating, I'd expect:

- broadband distortion increase
- HF garbage
- irregular harmonics

Instead the distortion stays low.

That suggests:

#+begin_quote
amplifier is not currently the limiting factor.

#+end_quote

--------------

*** DAC: Realtek ALC5686
:PROPERTIES:
:CUSTOM_ID: dac-realtek-alc5686
:END:
This DAC is unlikely to be visible in any of these measurements.

Modern Realtek codecs generally have:

- flat frequency response
- low THD
- low enough noise

Nothing in the graphs suggests source electronics are limiting
performance.

*** What impresses me most
:PROPERTIES:
:CUSTOM_ID: what-impresses-me-most
:END:
Actually the waterfall.

Many inexpensive DIY speakers show:

- cabinet panel resonance
- long ringing
- poorly damped internal reflections

I don't really see those.

The decay is fairly clean.

That suggests:

- decent cabinet stiffness
- reasonable damping
- no obvious enclosure problems

*** One thing I'd investigate
:PROPERTIES:
:CUSTOM_ID: one-thing-id-investigate
:END:
The response above roughly 8 kHz.

There is:

- strong peak around 10--11 kHz
- deep cancellation around 15--17 kHz

This could simply be:

- microphone position
- measurement axis
- diffraction from cabinet edges

I'd verify by measuring:

- 0°
- 15°
- 30°
- 45°

If the notch moves with angle, it isn't a loudspeaker defect.

*** What I would add to the design
:PROPERTIES:
:CUSTOM_ID: what-i-would-add-to-the-design
:END:

**** 1. Baffle edge treatment
:PROPERTIES:
:CUSTOM_ID: baffle-edge-treatment
:END:
The cabinet is only 138 mm wide.

Sharp edges on a narrow baffle can produce diffraction in the
several-kHz region.

A 10--15 mm round-over or chamfer on the front edges may slightly smooth
the 3--10 kHz response.

The effect won't be dramatic but is measurable.

**** 2. More stuffing
:PROPERTIES:
:CUSTOM_ID: more-stuffing
:END:
If there's only light damping inside:

I'd experiment with

- polyester fiber
- acoustic wool
- felt on the rear wall

Sometimes this reduces a few hundred Hz ripple.

**** 3. DSP low-shelf
:PROPERTIES:
:CUSTOM_ID: dsp-low-shelf
:END:
If the system is powered from a PC anyway, a gentle low-shelf can
improve perceived balance at moderate listening levels.

For example:

- +3 dB below 120 Hz

I would avoid larger boosts because the driver's excursion rises quickly
below its box resonance.

**** 4. High-pass filter
:PROPERTIES:
:CUSTOM_ID: high-pass-filter
:END:
If this speaker will ever be played loudly, I'd strongly recommend a
high-pass filter around 80--100 Hz.

That greatly reduces excursion while sacrificing little usable output,
since the speaker is already rolling off there.

*** Overall assessment in context
:PROPERTIES:
:CUSTOM_ID: overall-assessment-in-context
:END:
If someone told me:

#+begin_quote
"This is a €40 DIY powered desktop speaker using a single 3-inch
Peerless driver and a PAM8403 amp."

#+end_quote

and then showed me these measurements, I'd say:

#+begin_quote
*This is an excellent result.*
#+end_quote

The measured performance aligns well with the design constraints:

- *Excellent midrange:* smooth enough that voices should sound natural.
- *Controlled resonance:* the 3--4 kHz behavior is present but not
  excessive.
- *Clean decay:* no obvious cabinet issues.
- *Low distortion:* the driver appears to be operating comfortably at
  the measurement level.

The only fundamental limitation is the bass, and that's dictated by the
combination of a 3” driver and roughly 2 L enclosure---not by poor
implementation.

*** One additional measurement I'd like to see
:PROPERTIES:
:CUSTOM_ID: one-additional-measurement-id-like-to-see
:END:

To fully characterize the design, the most valuable next measurement
would be a *gated on-axis frequency response overlaid with 15°, 30°, and
45° off-axis responses*. Because this is a single full-range driver, its
directivity is a major part of how it will sound in a room. If the
off-axis response tracks the on-axis response smoothly, the speaker is
likely to have a very natural tonal balance despite its limited bass
extension.

** ~jrr-spl-combined~: jrr5x1, jrr5x, jrr4 taajuusvasteiden vertailu

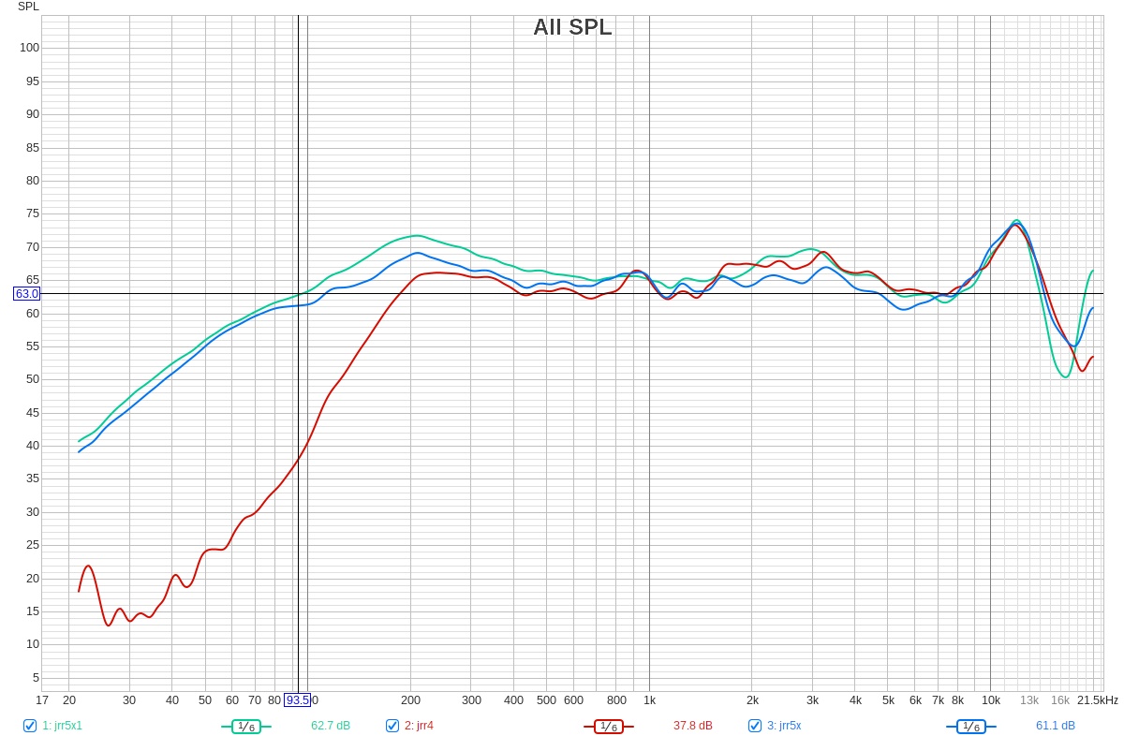
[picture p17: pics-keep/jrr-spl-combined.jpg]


*** Chatgpt arvio

Assuming these are near-field or 1 m gated SPL measurements with the
same drive level, here is what stands out.

Overall observations:You have three systems that are mechanically almost identical:

- Same driver: *Peerless PLS-P830986*

- Same enclosure dimensions

- Same enclosure type (sealed)

- The only intentional differences are:

  - DAC
  - amplifier module
  - internal damping (jrr5x1 has ~10 mm polyester filling)

That makes it a useful comparison because any differences are likely due
to the electronics and the cabinet stuffing.

**** 1. Bass response (20--200 Hz)
:PROPERTIES:
:CUSTOM_ID: bass-response-20200-hz
:END:
This is where the biggest differences occur.

***** jrr5x (blue)
- Smooth rise from 20 Hz to around 200 Hz
- About *69 dB around 200 Hz*
- Very typical response for a small sealed enclosure

***** jrr5x1 (green)
Compared with jrr5x:

- roughly *1--3 dB more output from 40--250 Hz*
- slightly broader hump around 180--250 Hz

The only mechanical difference is the polyester filling.

This is consistent with what stuffing usually does:

- increases effective enclosure volume slightly
- lowers Qtc
- reduces internal reflections
- can produce a little more low-frequency extension

The effect isn't huge, but it is visible.

***** jrr4 (red)
This is the surprising one.

Below about *120 Hz* it is *20--25 dB lower* than the others.

That is far too large to be explained by:

- enclosure tolerances
- stuffing
- amplifier differences

Instead it strongly suggests one of:

- a high-pass filter in the signal chain
- measurement settings
- Raspberry Pi PWM audio path
- software EQ
- ALSA/PipeWire configuration

The response begins matching the others around *180--250 Hz*, indicating
the driver itself is probably fine.

This looks much more like electronics than acoustics.

**** Taajuusvasteet

***** 2. Midrange (200 Hz -- 2 kHz)
:PROPERTIES:
:CUSTOM_ID: midrange-200-hz-2-khz
:END:
All three are remarkably similar.

Differences are mostly within:

±1--2 dB

which is excellent repeatability.

This indicates

- same driver behavior
- same cabinet
- same baffle diffraction

The PAM8403 variants also appear essentially identical here.

***** 3. Presence region (2--5 kHz)
:PROPERTIES:
:CUSTOM_ID: presence-region-25-khz
:END:
There are some small differences.

Green:

- a little stronger around 2--3.5 kHz

Blue:

- slightly lower around 2.5--4 kHz

Red:

- between the two

These are all within roughly 2 dB.

Possible causes:

- microphone placement
- driver unit variation
- amplifier output impedance (minor)
- stuffing affecting internal cavity resonances

Nothing alarming.

--------------

***** 4. Treble (10--20 kHz)
:PROPERTIES:
:CUSTOM_ID: treble-1020-khz
:END:
All three show:

- strong peak around *11--12 kHz*
- rapid roll-off after 13--14 kHz

The exact depth of the notch differs.

Green has the deepest notch.

This is almost certainly dominated by:

- driver breakup/directivity
- microphone angle
- measurement geometry

rather than the electronics.

The DAC is very unlikely to create such narrow acoustic features.

--------------

**** DAC comparison
:PROPERTIES:
:CUSTOM_ID: dac-comparison
:END:
***** Realtek ALC5686 (jrr5x / jrr5x1)
:PROPERTIES:
:CUSTOM_ID: realtek-alc5686-jrr5x-jrr5x1
:END:
The two Realtek-based systems overlay extremely well.

This suggests:

- flat frequency response
- no obvious filtering
- no unexpected coloration

Exactly what you would expect from a modern codec.

--------------

***** Raspberry Pi PWM audio (jrr4)
:PROPERTIES:
:CUSTOM_ID: raspberry-pi-pwm-audio-jrr4
:END:
The bass roll-off strongly suggests the PWM output path is not flat.

Possible reasons include:

- output coupling capacitor
- load interaction
- software processing
- analog reconstruction filter
- measurement gain differences

Since everything above about 200 Hz matches well, I would investigate
the Pi audio path first.

--------------

**** Amplifier comparison
:PROPERTIES:
:CUSTOM_ID: amplifier-comparison
:END:
Both amplifiers are PAM8403-based.

The response above about 200 Hz is almost identical.

That suggests neither amplifier is significantly affecting frequency
response.

Any audible differences between them would more likely be due to:

- noise floor
- clipping behavior
- output power
- distortion

rather than tonal balance.

--------------

**** Cabinet stuffing effect
:PROPERTIES:
:CUSTOM_ID: cabinet-stuffing-effect
:END:
Comparing *jrr5x* and *jrr5x1*:

The stuffing appears to provide:

- slightly smoother low end
- modest increase in bass output
- slightly smoother upper midrange

Exactly what one would expect from light damping.

The effect is relatively subtle---which is also expected in a sealed
box.

--------------

**** Most important finding
:PROPERTIES:
:CUSTOM_ID: most-important-finding
:END:
The dominant anomaly is *jrr4*.

Its bass response differs dramatically from the other two.

Because the cabinet and driver are the same, I'd investigate:

1. Raspberry Pi analog output configuration
2. ALSA/PipeWire volume and EQ
3. High-pass filtering in software
4. Measurement level calibration
5. Coupling capacitor values in the Pi audio path

--------------

**** Overall assessment
:PROPERTIES:
:CUSTOM_ID: overall-assessment
:END:
| System   | Strengths                                                | Weaknesses                                 |
|----------+----------------------------------------------------------+--------------------------------------------|
| *jrr5x1* | Best low-frequency extension, smoothest overall response | Slightly stronger 200 Hz hump              |
| *jrr5x*  | Very balanced reference response                         | Slightly less bass than stuffed version    |
| *jrr4*   | Midrange and treble closely match the others             | Severe bass attenuation below ~120--150 Hz |

The close agreement between *jrr5x* and *jrr5x1* suggests your enclosure
design is repeatable, and the small amount of stuffing has the expected
beneficial effect. The large low-frequency discrepancy in *jrr4* is
almost certainly due to the Raspberry Pi analog audio path or its
configuration rather than the loudspeaker itself.

* Admin                                                            :noexport:

** Os admin
*** ~create-dir~:  mkdir command to create DIR
#+name: create-dir
#+BEGIN_SRC bash :eval no-export :results output :var DIR="/home/jj/vc"
echo "Create DIR=$DIR in $(pwd) for user '$(whoami)' on host='$(hostname)' on $(date)"
([ ! -d $DIR ] && mkdir -p $DIR && echo Directory $DIR created ) || echo Directory $DIR already exists
#+END_SRC

#+RESULTS: create-dir
: Directory /home/jj/vc already exists

*** ~hosti~: Hostname
Installation hostname

#+name: hosti
#+BEGIN_SRC bash :eval no-export :results output :exports both
echo User $(whoami) in host $(hostname) on $(date)
#+END_SRC

#+RESULTS: hosti
: jrr5 on Tue Nov 19 13:41:36 EET 2024

#+RESULTS:
: sorsa

** jrr-admin
:PROPERTIES:
:header-args+: :dir  /ssh:jrr5:
:END:

*** ~jrr-where~: Expect to run on :dir

#+name: jrr-where
#+BEGIN_SRC bash :eval no-export :results output
echo "Running in $(pwd) for user '$(whoami)' host '$(hostname)' on $(date)"
#+END_SRC

*** ~jrr-stop~: stop ~jrr~ - service

#+name: jrr-stop
#+BEGIN_SRC bash :eval no-export :results output
echo "Running in $(pwd) for user '$(whoami)' host '$(hostname)' on $(date)"
jrr.sh stop 2>&1
#+END_SRC

#+RESULTS: jrr-start
: Running in /home/pi host 'jrr5' on Tue Apr 14 15:07:30 EEST 2026
: 'pi' runs '/home/pi/jrr/bin/jrr.sh start' on 'jrr5:/home/pi'

*** ~jrr-start~: start ~jrr~ - service

#+name: jrr-start
#+BEGIN_SRC bash :eval no-export :results output
echo "Running in $(pwd) for user '$(whoami)' host '$(hostname)' on $(date)"
jrr.sh start 2>&1
#+END_SRC

#+RESULTS: jrr-start
: Running in /home/pi host 'jrr5' on Tue Apr 14 15:07:30 EEST 2026
: 'pi' runs '/home/pi/jrr/bin/jrr.sh start' on 'jrr5:/home/pi'

*** ~jrr-status~: status ~jrr~ - service

#+name: jrr-status
#+BEGIN_SRC bash :eval no-export :results output
echo "Running in $(pwd) for user '$(whoami)' host '$(hostname)' on $(date)"
jrr.sh status 2>&1
#+END_SRC

#+RESULTS: jrr-status
: Running in /home/pi host 'jrr5' on Tue Apr 28 10:04:37 EEST 2026
: 'pi' runs '/home/pi/jrr/bin/jrr.sh status' on 'jrr5:/home/pi'
: jrr.sh: status=1/
: jrr.py: status=0/pi         10276   10272  8 09:57 pts/1    00:00:34 .venv/bin/python ./jrr.py -v -v radio --screen-shots
: ffmpeg: status=0/pi          2665    2664  5 08:22 ?        00:05:27 ffmpeg -hide_banner -nostdin -nostats -loglevel error -i https://jarviradio.radiotaajuus.fi:9000/jr -filter_complex [0:a]volume=volume=1.5,pan=mono|c0=0.5*c0+0.5*c1,alimiter[aout] -map [aout] -ac 2 -f alsa hw:CARD=Audio,DEV=0

Success

: Running in /home/pi host 'jrr5' on Tue Apr 14 15:08:02 EEST 2026
: 'pi' runs '/home/pi/jrr/bin/jrr.sh status' on 'jrr5:/home/pi'
: jrr.sh: status=0/pi          4044       1  0 15:07 ?        00:00:00 /bin/bash /home/pi/jrr/bin/jrr.sh daemon
: jrr.py: status=0/pi          4057    4044 11 15:07 ?        00:00:06 .venv/bin/python ./jrr.py radio
: ffmpeg: status=0/pi          4091    4090  7 15:07 ?        00:00:03 ffmpeg -hide_banner -nostdin -nostats -loglevel error -i https://jarviradio.radiotaajuus.fi:9000/jr -filter_complex [0:a]volume=volume=2,pan=mono|c0=0.5*c0+0.5*c1,alimiter[aout] -map [aout] -ac 2 -f alsa hw:CARD=Audio,DEV=0

#+RESULTS: jrr-start

*** ~jrr-debug~: run ~jrr.sh debug~

   #+name: jrr-debug
   #+BEGIN_SRC elisp :noweb yes :results output :eval no-export :exports none  :var TERM_HEADER="jrr5 journalctl"
   (start-process "server" "buf-server" "xterm"  "-T" TERM_HEADER "-fa" "'Monospace'" "-fs" "12" "-hold" "-e"  "bash" "-c" "ssh jrr5 jrr/bin/jrr.sh --dir jrr debug")
   #+END_SRC

   #+RESULTS: jrr-debug

** Audio analysis
*** ~audio-analysis-doc~: Show  AUDIO_FILE used for testing
#+name: audio-analysis-doc
#+BEGIN_SRC bash :eval no-export :results output :dir .
echo "Running in $(pwd) for user '$(whoami)' on host '$(hostname)' on $(date)"
echo "AUDIO_FILE=$AUDIO_FILE"
[[ ! -f "$AUDIO_FILE" ]] && echo "No such file $AUDIO_FILE" && exit 1
ls -latr $AUDIO_FILE
#+END_SRC

#+RESULTS: audio-analysis-doc
: Running in /home/jj/work/jrr for user 'jj' on host 'Leo' on ke 22.7.2026 12.20.01 +0300
: AUDIO_FILE=audio/LinSwp_10_20000_-12_dBFS_48k_Float_LR.wav
: -rw-rw-r-- 1 jj jj 3840044 heinä  22 10:25 audio/LinSwp_10_20000_-12_dBFS_48k_Float_LR.wav

*** ~audio-analysis-show-all~: Show availables test signals in ~audio~ -directory

#+name: audio-analysis-show-all
#+BEGIN_SRC bash :eval no-export :results output :dir .
echo "Running in $(pwd) for user '$(whoami)' on host '$(hostname)' on $(date)"
ls -latr audio/*.wav
#+END_SRC

#+RESULTS: audio-analysis-show-all
: Running in /home/jj/work/jrr for user 'jj' on host 'Leo' on ke 22.7.2026 12.20.29 +0300
: -rw-rw-r-- 1 jj jj  3840044 heinä  22 10:25 audio/LinSwp_10_20000_-12_dBFS_48k_Float_LR.wav
: -rw-rw-r-- 1 jj jj 23040044 heinä  22 12:18 audio/Sine_1000_-12_dBFS_48k_Float_LR.wav

*** ~audio-analysis-copy~: Copy AUDIO_FILE/* to AUDIO_TARGET_SSH into 'tmp' -directory
#+name: audio-analysis-copy
#+BEGIN_SRC bash :eval no-export :results output :dir .
echo "Running in $(pwd) for user '$(whoami)' on host '$(hostname)' on $(date)"
[[ "$AUDIO_FILE" != *"*"* ]] && [[ ! -f "$AUDIO_FILE" ]] && echo "No such file $AUDIO_FILE" && exit 1
scp $AUDIO_FILE $AUDIO_TARGET_SSH:tmp 2>&1; true
#+END_SRC

#+RESULTS: audio-analysis-copy
: Running in /home/jj/work/jrr for user 'jj' on host 'Leo' on ke 22.7.2026 12.21.06 +0300

*** ~audio-analysis-playable~: Show audio analysis files playable on remote
#+name: audio-analysis-playable
#+BEGIN_SRC bash :eval no-export :results output
echo "Running in $(pwd) for user '$(whoami)' on host '$(hostname)' on $(date)"
ls -ltr tmp/*.wav
#+END_SRC

#+BEGIN_SRC bash :eval no-export :results output 
echo "Running in $(pwd) for user '$(whoami)' on host '$(hostname)' on $(date)"
$STREAMER --help; true
#+END_SRC

#+RESULTS:
#+begin_example
Running in /home2/jrr for user 'jrr' on host 'jrr5x1' on Wed Jul 22 11:18:34 EEST 2026

usage: jrr_streamer.sh
jrr/src/jrr_streamer.sh - 0.1

Generate sine waves

Usage:
jrr/src/jrr_streamer.sh [options]  -- <commands>
options:
--sh_trace
--version             : print out version number && exit 0
--mono                : pan stereo streams to one mono stream
--filter FILTER       : manyally set FILTER
--stereo              : streo streams (default)
--device AUDIO_OUT    : Set audio AUDIO_OUT one from 'list-devices', defaults 
--gain GAIN           : Volume gain, default 1.5
--rgain RGAIN         : Volume on right channel, default 1.0
--lgain LGAIN         : Volume on left channel, default 1.0
--start-freq FREQ     : Set START_FREQ
--end-freq FREQ       : Set END_FREQ
--left FREQ           : Set left ch frequency, default 1000
--left FREQ           : Set left ch frequency, default 1000
--right FREQ          : Set right ch frequency, default 440
--volume VOLUME       : Set output VOLUME
--duration DURATION   : Set duration of generated sound file to DURATION=60 secs
--file FILE           : Use sound FILE
--debug|-v (multiple) : increment debug level
-?|--help             : usage

commands:
alsa-devices          : list ALSA hw devices
list-devices          : list audio devices
gen                   : sine signal generator RIGHT=440 Hz, LEFT=1000 Hz, GAIN=1.5 DURATION=60 s
sine                  : generate 'sine FILE'
chirp-file            : generate 'chirp START_FREQ END_FREQ to FILE'
play FILE             : play FILE
chirp                 : stream chirp START_FREQ END_FREQ  with GAIN to alsa 
stream URL            : stream URL with GAIN (action from jrr.py)
dmsg MSG              : send MSG to kernel /dev/kmsg
wifi-setup SSID PASSWD: configure wifi SSID and PASSWORD
fw-download U         : Download firmware from url U to LOCAL_REPO=/home2/jrr/jrr/
fw-unpack U           : Unpack firmware package in LOCAL_REPO downloaded from url U
                        forexample U=https://github.com/jarjuk/jrr/archive/refs/tags/jrr-0.0.0.zip
fw-pending U          : Set symbolic link to fw unpacked into LOCAL_REPO fo remote repo url U
firmware U            : Download, unpack and mark pending in LOCAL_REPO remote repo firmware url U

Examples:

# generate sine wave LEFT_FREQ=1000, RIGHT_FREQ=440 to sound FILE= w
jrr/src/jrr_streamer.sh sine

# play sound FILE=
jrr/src/jrr_streamer.sh play

# stream URL
jrr/src/jrr_streamer.sh stream https://jarviradio.radiotaajuus.fi:9000/jr

#+end_example

*** ~audio-analysis-play~: Start playing AUDIO_FILE (as AUDIO_FILE_TO_PLAY)

#+name: audio-analysis-play
#+BEGIN_SRC bash :eval no-export :results output :var STREAMER="jrr/src/jrr_streamer.sh"
echo "Running in $(pwd) for user '$(whoami)' on host '$(hostname)' on $(date)"
AUDIO_FILE_TO_PLAY=tmp/$(basename $AUDIO_FILE)
$STREAMER --file $AUDIO_FILE_TO_PLAY stream 2>&1; true
#+END_SRC

*** ~audio-analysis-ffmpeg~: Play using ffmpeg AUDIO_FILE (as AUDIO_FILE_TO_PLAY)

#+name: audio-analysis-ffmpeg
#+BEGIN_SRC bash :eval no-export :results output :var STREAMER="jrr/src/jrr_streamer.sh"
echo "Running in $(pwd) for user '$(whoami)' on host '$(hostname)' on $(date)"
AUDIO_FILE_TO_PLAY=tmp/$(basename $AUDIO_FILE)
set -x
CMD="ffmpeg -hide_banner -nostdin -nostats -loglevel error -i $AUDIO_FILE_TO_PLAY -f alsa hw:CARD=Audio,DEV=0"
echo CMD=$CMD
$CMD 2>&1; true
#+END_SRC

*** ~vlc-play~: Start playing AUDIO_FILE using vlc

#+name: vlc-play
#+BEGIN_SRC bash :eval no-export :results output
echo "Running in $(pwd) for user '$(whoami)' on host '$(hostname)' on $(date)"
# audio test files in tmp -directory
AUDIO_FILE_TO_PLAY=tmp/$(basename $AUDIO_FILE)
echo AUDIO_FILE_TO_PLAY=$AUDIO_FILE_TO_PLAY
# using command line vlc 
CMD="cvlc --play-and-exit $AUDIO_FILE_TO_PLAY"
echo $CMD
$CMD 2>&1; true
#+END_SRC

#+RESULTS: vlc-play
: Running in /home/jj/work/jrr for user 'jj' on host 'Leo' on ma 27.7.2026 10.10.47 +0300
: bash: line 4: tmp/: Is a directory
: 

* Notes

** Taajuusvaste                                                    :noexport:
*** jrr5x1
:PROPERTIES:
:header-args+: :var  AUDIO_TARGET_SSH="jrr@jrr5x1.local"
:header-args+: :var STREAMER="jrr/src/jrr_streamer.sh"
:header-args+:   :dir  /ssh:jrr@jrr5x1.local:
:END:

Frequency response of a loudspeaker remotee AUDIO_TARGET_SSH on using
test signal in AUDIO_FILE.

*** Stop jrr -service

Managing jrr -service
#+call: jrr-where()

#+RESULTS:
: Running in /home2/jrr for user 'jrr' host 'jrr5x1' on Wed Jul 22 11:03:31 EEST 2026

Stop jrr -service
#+call: jrr-stop()

#+RESULTS:
: Running in /home2/jrr for user 'jrr' host 'jrr5x1' on Wed Jul 22 18:46:47 EEST 2026
: 'jrr' runs '/home2/jrr/jrr/bin/jrr.sh stop' on 'jrr5x1:/home2/jrr'
: do_stop: no jrr.py process found

*** Using AUDIO_TARGET

Audio analysis on remote host for 'jrr' user
#+BEGIN_SRC bash :eval no-export :results output
echo "Running in $(pwd) for user '$(whoami)' on host '$(hostname)' on $(date)"
echo "AUDIO_TARGET_SSH=$AUDIO_TARGET_SSH"
#+END_SRC

#+RESULTS:
: Running in /home2/jrr for user 'jrr' on host 'jrr5x1' on Wed Jul 22 12:19:39 EEST 2026
: AUDIO_TARGET_SSH=jrr@jrr5x1.local

Target system AUDIO_TARGET_SSH accessed using ssh  
#+BEGIN_SRC bash :eval no-export :results output :dir .
echo "Running in $(pwd) for user '$(whoami)' on host '$(hostname)' on $(date)"
echo "AUDIO_TARGET_SSH=$AUDIO_TARGET_SSH"
ssh $AUDIO_TARGET_SSH echo 'Running in $(pwd) for user "$(whoami)" on host "$(hostname)" on $(date)'
#+END_SRC

Validate that we can access also over tramp
#+BEGIN_SRC bash :eval no-export :results output
echo "Running in $(pwd) for user '$(whoami)' on host '$(hostname)' on $(date)"
#+END_SRC

*** Copy all audio test files to AUDIO_TARGET_SSH

Copy all files from ~audio~ -directory
#+call: audio-analysis-copy[:dir .](AUDIO_FILE="audio/*")

#+RESULTS:
: Running in /home/jj/work/jrr for user 'jj' on host 'Leo' on ke 22.7.2026 18.59.13 +0300

Copy playable  ~audio~ -files
#+call: audio-analysis-playable()

#+RESULTS:
#+begin_example
Running in /home2/jrr for user 'jrr' on host 'jrr5x1' on Wed Jul 22 18:59:28 EEST 2026
-rw-rw-r-- 1 jrr jrr  4718636 Jul 22 18:59 tmp/256kMeasSweep_100_to_15000_-12_dBFS_48k_Float_LR_refL.wav
-rw-rw-r-- 1 jrr jrr  4718636 Jul 22 18:59 tmp/256kMeasSweep_100_to_20000_-12_dBFS_48k_Float_LR_refL.wav
-rw-rw-r-- 1 jrr jrr  4718636 Jul 22 18:59 tmp/256kMeasSweep_100_to_5000_-12_dBFS_48k_Float_LR_refL.wav
-rw-rw-r-- 1 jrr jrr  4718636 Jul 22 18:59 tmp/256kMeasSweep_20_to_20000_-12_dBFS_48k_Float_LR_refL.wav
-rw-rw-r-- 1 jrr jrr  4718636 Jul 22 18:59 tmp/256kMeasSweep_50_to_20000_-12_dBFS_48k_Float_LR_refL.wav
-rw-rw-r-- 1 jrr jrr  3840044 Jul 22 18:59 tmp/LinSwp_10_20000_-12_dBFS_48k_Float_LR.wav
-rw-rw-r-- 1 jrr jrr 23040044 Jul 22 18:59 tmp/Sine_1000_-12_dBFS_48k_Float_LR.wav
-rw-rw-r-- 1 jrr jrr  3840044 Jul 22 18:59 tmp/Sine_100_-12_dBFS_48k_Float_LR.wav
-rw-rw-r-- 1 jrr jrr  3840044 Jul 22 18:59 tmp/Sine_200_-12_dBFS_48k_Float_LR.wav
-rw-rw-r-- 1 jrr jrr  3840044 Jul 22 18:59 tmp/Sine_30_-12_dBFS_48k_Float_LR.wav
-rw-rw-r-- 1 jrr jrr  3840044 Jul 22 18:59 tmp/Sine_500_-12_dBFS_48k_Float_LR.wav
-rw-rw-r-- 1 jrr jrr  3840044 Jul 22 18:59 tmp/Sine_50_-12_dBFS_48k_Float_LR.wav
-rw-rw-r-- 1 jrr jrr  3840044 Jul 22 18:59 tmp/Sine_75_-12_dBFS_48k_Float_LR.wav
#+end_example

*** Audio analysis linear sweep 20Hz-20kHz -12dBFS 48k LR
:PROPERTIES:
:header-args+: :var  AUDIO_FILE="audio/256kMeasSweep_20_to_20000_-12_dBFS_48k_Float_LR_refL.wav"
:END:

Show availables test signals in ~audio~ -directory

#+call: audio-analysis-show-all[:dir .]()

#+RESULTS:
: Running in /home/jj/work/jrr for user 'jj' on host 'Leo' on ke 22.7.2026 12.57.04 +0300
: -rw-rw-r-- 1 jj jj  3840044 heinä  22 10:25 audio/LinSwp_10_20000_-12_dBFS_48k_Float_LR.wav
: -rw-rw-r-- 1 jj jj 23040044 heinä  22 12:18 audio/Sine_1000_-12_dBFS_48k_Float_LR.wav
: -rw-rw-r-- 1 jj jj  4718636 heinä  22 12:49 audio/256kMeasSweep_100_to_5000_-12_dBFS_48k_Float_LR_refL.wav
: -rw-rw-r-- 1 jj jj  4718636 heinä  22 12:56 audio/256kMeasSweep_20_to_20000_-12_dBFS_48k_Float_LR_refL.wav

Using test signal in AUDIO_FILE
#+call: audio-analysis-doc[:dir .]()

#+RESULTS:
: Running in /home/jj/work/jrr for user 'jj' on host 'Leo' on ke 22.7.2026 12.56.52 +0300
: AUDIO_FILE=audio/256kMeasSweep_20_to_20000_-12_dBFS_48k_Float_LR_refL.wav
: -rw-rw-r-- 1 jj jj 4718636 heinä  22 12:56 audio/256kMeasSweep_20_to_20000_-12_dBFS_48k_Float_LR_refL.wav

Copy AUDIO_FILE to AUDIO_TARGET_SSH into 'tmp' -directory
#+call: audio-analysis-copy[:dir .]()

#+RESULTS:
: Running in /home/jj/work/jrr for user 'jj' on host 'Leo' on ke 22.7.2026 12.57.09 +0300

Show audio analysis files playable on remote
#+call: audio-analysis-playable()

#+RESULTS:
: Running in /home2/jrr for user 'jrr' on host 'jrr5x1' on Wed Jul 22 12:57:14 EEST 2026
: -rw-rw-r-- 1 jrr jrr 23040044 Jul 22 12:28 tmp/Sine_1000_-12_dBFS_48k_Float_LR.wav
: -rw-rw-r-- 1 jrr jrr  3840044 Jul 22 12:38 tmp/LinSwp_10_20000_-12_dBFS_48k_Float_LR.wav
: -rw-rw-r-- 1 jrr jrr  4718636 Jul 22 12:51 tmp/256kMeasSweep_100_to_5000_-12_dBFS_48k_Float_LR_refL.wav
: -rw-rw-r-- 1 jrr jrr  4718636 Jul 22 12:57 tmp/256kMeasSweep_20_to_20000_-12_dBFS_48k_Float_LR_refL.wav

#+call: audio-analysis-play()

#+RESULTS:
#+begin_example
Running in /home2/jrr for user 'jrr' on host 'jrr5x1' on Wed Jul 22 13:53:57 EEST 2026
20260722-13:53:57: jrr/src/jrr_streamer.sh|init_ALSA_CARD: starting with ALSA_CARD=''
20260722-13:53:57: jrr/src/jrr_streamer.sh|init_ALSA_CARD: done with ALSA_CARD='Audio '
20260722-13:53:57: jrr/src/jrr_streamer.sh|set_alsa_volume: card=Audio , volume=95%
Simple mixer control 'Headphone',0
  Capabilities: pvolume pswitch pswitch-joined
  Playback channels: Front Left - Front Right
  Limits: Playback 0 - 175
  Mono:
  Front Left: Playback 166 [95%] [-3.38dB] [on]
  Front Right: Playback 166 [95%] [-3.38dB] [on]
Running in host 'jrr5x1' on Wed Jul 22 13:53:57 EEST 2026
20260722-13:53:57: jrr/src/jrr_streamer.sh|AUDIO_OUT=hw:CARD=Audio,DEV=0, URL=tmp/256kMeasSweep_20_to_20000_-12_dBFS_48k_Float_LR_refL.wav, GAIN=1.5
+ ffmpeg -hide_banner -nostdin -nostats -loglevel error -i tmp/256kMeasSweep_20_to_20000_-12_dBFS_48k_Float_LR_refL.wav -filter_complex '[0:a]volume=volume=1.5,pan=mono|c0=0.5*c0+0.5*c1,alimiter[aout]' -map '[aout]' -ac 2 -f alsa hw:CARD=Audio,DEV=0
#+end_example

*** Audio analysis linear sweep 50Hz-20kHz -12dBFS 48k LR
:PROPERTIES:
:header-args+: :var  AUDIO_FILE="audio/256kMeasSweep_50_to_20000_-12_dBFS_48k_Float_LR_refL.wav"
:END:

Show availables test signals in ~audio~ -directory

#+call: audio-analysis-show-all[:dir .]()

#+RESULTS:
: Running in /home/jj/work/jrr for user 'jj' on host 'Leo' on ke 22.7.2026 13.00.16 +0300
: -rw-rw-r-- 1 jj jj  3840044 heinä  22 10:25 audio/LinSwp_10_20000_-12_dBFS_48k_Float_LR.wav
: -rw-rw-r-- 1 jj jj 23040044 heinä  22 12:18 audio/Sine_1000_-12_dBFS_48k_Float_LR.wav
: -rw-rw-r-- 1 jj jj  4718636 heinä  22 12:49 audio/256kMeasSweep_100_to_5000_-12_dBFS_48k_Float_LR_refL.wav
: -rw-rw-r-- 1 jj jj  4718636 heinä  22 12:56 audio/256kMeasSweep_20_to_20000_-12_dBFS_48k_Float_LR_refL.wav
: -rw-rw-r-- 1 jj jj  4718636 heinä  22 12:59 audio/256kMeasSweep_50_to_20000_-12_dBFS_48k_Float_LR_refL.wav

Using test signal in AUDIO_FILE
#+call: audio-analysis-doc[:dir .]()

#+RESULTS:
: Running in /home/jj/work/jrr for user 'jj' on host 'Leo' on ke 22.7.2026 13.00.19 +0300
: AUDIO_FILE=audio/256kMeasSweep_50_to_20000_-12_dBFS_48k_Float_LR_refL.wav
: -rw-rw-r-- 1 jj jj 4718636 heinä  22 12:59 audio/256kMeasSweep_50_to_20000_-12_dBFS_48k_Float_LR_refL.wav

Copy AUDIO_FILE to AUDIO_TARGET_SSH into 'tmp' -directory
#+call: audio-analysis-copy[:dir .]()

#+RESULTS:
: Running in /home/jj/work/jrr for user 'jj' on host 'Leo' on ke 22.7.2026 13.00.24 +0300

Show audio analysis files playable on remote
#+call: audio-analysis-playable()

#+RESULTS:
: Running in /home2/jrr for user 'jrr' on host 'jrr5x1' on Wed Jul 22 13:00:29 EEST 2026
: -rw-rw-r-- 1 jrr jrr 23040044 Jul 22 12:28 tmp/Sine_1000_-12_dBFS_48k_Float_LR.wav
: -rw-rw-r-- 1 jrr jrr  3840044 Jul 22 12:38 tmp/LinSwp_10_20000_-12_dBFS_48k_Float_LR.wav
: -rw-rw-r-- 1 jrr jrr  4718636 Jul 22 12:51 tmp/256kMeasSweep_100_to_5000_-12_dBFS_48k_Float_LR_refL.wav
: -rw-rw-r-- 1 jrr jrr  4718636 Jul 22 12:57 tmp/256kMeasSweep_20_to_20000_-12_dBFS_48k_Float_LR_refL.wav
: -rw-rw-r-- 1 jrr jrr  4718636 Jul 22 13:00 tmp/256kMeasSweep_50_to_20000_-12_dBFS_48k_Float_LR_refL.wav

#+call: audio-analysis-play()

#+RESULTS:
#+begin_example
Running in /home2/jrr for user 'jrr' on host 'jrr5x1' on Wed Jul 22 13:01:00 EEST 2026
20260722-13:01:00: jrr/src/jrr_streamer.sh|init_ALSA_CARD: starting with ALSA_CARD=''
20260722-13:01:00: jrr/src/jrr_streamer.sh|init_ALSA_CARD: done with ALSA_CARD='Audio '
20260722-13:01:00: jrr/src/jrr_streamer.sh|set_alsa_volume: card=Audio , volume=95%
Simple mixer control 'Headphone',0
  Capabilities: pvolume pswitch pswitch-joined
  Playback channels: Front Left - Front Right
  Limits: Playback 0 - 175
  Mono:
  Front Left: Playback 166 [95%] [-3.38dB] [on]
  Front Right: Playback 166 [95%] [-3.38dB] [on]
Running in host 'jrr5x1' on Wed Jul 22 13:01:00 EEST 2026
20260722-13:01:00: jrr/src/jrr_streamer.sh|AUDIO_OUT=hw:CARD=Audio,DEV=0, URL=tmp/256kMeasSweep_50_to_20000_-12_dBFS_48k_Float_LR_refL.wav, GAIN=1.5
+ ffmpeg -hide_banner -nostdin -nostats -loglevel error -i tmp/256kMeasSweep_50_to_20000_-12_dBFS_48k_Float_LR_refL.wav -filter_complex '[0:a]volume=volume=1.5,pan=mono|c0=0.5*c0+0.5*c1,alimiter[aout]' -map '[aout]' -ac 2 -f alsa hw:CARD=Audio,DEV=0
#+end_example

*** Audio analysis linear sweep 100Hz-20kHz -12dBFS 48k LR
:PROPERTIES:
:header-args+: :var  AUDIO_FILE="audio/256kMeasSweep_100_to_20000_-12_dBFS_48k_Float_LR_refL.wav"
:END:

Show availables test signals in ~audio~ -directory

#+call: audio-analysis-show-all[:dir .]()

#+RESULTS:
: Running in /home/jj/work/jrr for user 'jj' on host 'Leo' on ke 22.7.2026 13.02.37 +0300
: -rw-rw-r-- 1 jj jj  3840044 heinä  22 10:25 audio/LinSwp_10_20000_-12_dBFS_48k_Float_LR.wav
: -rw-rw-r-- 1 jj jj 23040044 heinä  22 12:18 audio/Sine_1000_-12_dBFS_48k_Float_LR.wav
: -rw-rw-r-- 1 jj jj  4718636 heinä  22 12:49 audio/256kMeasSweep_100_to_5000_-12_dBFS_48k_Float_LR_refL.wav
: -rw-rw-r-- 1 jj jj  4718636 heinä  22 12:56 audio/256kMeasSweep_20_to_20000_-12_dBFS_48k_Float_LR_refL.wav
: -rw-rw-r-- 1 jj jj  4718636 heinä  22 12:59 audio/256kMeasSweep_50_to_20000_-12_dBFS_48k_Float_LR_refL.wav
: -rw-rw-r-- 1 jj jj  4718636 heinä  22 13:02 audio/256kMeasSweep_100_to_20000_-12_dBFS_48k_Float_LR_refL.wav

Using test signal in AUDIO_FILE
#+call: audio-analysis-doc[:dir .]()

#+RESULTS:
: Running in /home/jj/work/jrr for user 'jj' on host 'Leo' on ke 22.7.2026 13.02.39 +0300
: AUDIO_FILE=audio/256kMeasSweep_100_to_20000_-12_dBFS_48k_Float_LR_refL.wav
: -rw-rw-r-- 1 jj jj 4718636 heinä  22 13:02 audio/256kMeasSweep_100_to_20000_-12_dBFS_48k_Float_LR_refL.wav

Copy AUDIO_FILE to AUDIO_TARGET_SSH into 'tmp' -directory
#+call: audio-analysis-copy[:dir .]()

#+RESULTS:
: Running in /home/jj/work/jrr for user 'jj' on host 'Leo' on ke 22.7.2026 13.02.42 +0300

Show audio analysis files playable on remote
#+call: audio-analysis-playable()

#+RESULTS:
: Running in /home2/jrr for user 'jrr' on host 'jrr5x1' on Wed Jul 22 13:02:46 EEST 2026
: -rw-rw-r-- 1 jrr jrr 23040044 Jul 22 12:28 tmp/Sine_1000_-12_dBFS_48k_Float_LR.wav
: -rw-rw-r-- 1 jrr jrr  3840044 Jul 22 12:38 tmp/LinSwp_10_20000_-12_dBFS_48k_Float_LR.wav
: -rw-rw-r-- 1 jrr jrr  4718636 Jul 22 12:51 tmp/256kMeasSweep_100_to_5000_-12_dBFS_48k_Float_LR_refL.wav
: -rw-rw-r-- 1 jrr jrr  4718636 Jul 22 12:57 tmp/256kMeasSweep_20_to_20000_-12_dBFS_48k_Float_LR_refL.wav
: -rw-rw-r-- 1 jrr jrr  4718636 Jul 22 13:00 tmp/256kMeasSweep_50_to_20000_-12_dBFS_48k_Float_LR_refL.wav
: -rw-rw-r-- 1 jrr jrr  4718636 Jul 22 13:02 tmp/256kMeasSweep_100_to_20000_-12_dBFS_48k_Float_LR_refL.wav

#+call: audio-analysis-play()

#+RESULTS:
#+begin_example
Running in /home2/jrr for user 'jrr' on host 'jrr5x1' on Wed Jul 22 13:51:53 EEST 2026
20260722-13:51:53: jrr/src/jrr_streamer.sh|init_ALSA_CARD: starting with ALSA_CARD=''
20260722-13:51:53: jrr/src/jrr_streamer.sh|init_ALSA_CARD: done with ALSA_CARD='Audio '
20260722-13:51:53: jrr/src/jrr_streamer.sh|set_alsa_volume: card=Audio , volume=95%
Simple mixer control 'Headphone',0
  Capabilities: pvolume pswitch pswitch-joined
  Playback channels: Front Left - Front Right
  Limits: Playback 0 - 175
  Mono:
  Front Left: Playback 166 [95%] [-3.38dB] [on]
  Front Right: Playback 166 [95%] [-3.38dB] [on]
Running in host 'jrr5x1' on Wed Jul 22 13:51:53 EEST 2026
20260722-13:51:53: jrr/src/jrr_streamer.sh|AUDIO_OUT=hw:CARD=Audio,DEV=0, URL=tmp/256kMeasSweep_100_to_20000_-12_dBFS_48k_Float_LR_refL.wav, GAIN=1.5
+ ffmpeg -hide_banner -nostdin -nostats -loglevel error -i tmp/256kMeasSweep_100_to_20000_-12_dBFS_48k_Float_LR_refL.wav -filter_complex '[0:a]volume=volume=1.5,pan=mono|c0=0.5*c0+0.5*c1,alimiter[aout]' -map '[aout]' -ac 2 -f alsa hw:CARD=Audio,DEV=0
#+end_example

*** Audio analysis linear sweep 100Hz-15kHz -12dBFS 48k LR
:PROPERTIES:
:header-args+: :var  AUDIO_FILE="audio/256kMeasSweep_100_to_15000_-12_dBFS_48k_Float_LR_refL.wav"
:END:

Show availables test signals in ~audio~ -directory

#+call: audio-analysis-show-all[:dir .]()

#+RESULTS:
: Running in /home/jj/work/jrr for user 'jj' on host 'Leo' on ke 22.7.2026 13.04.50 +0300
: -rw-rw-r-- 1 jj jj  3840044 heinä  22 10:25 audio/LinSwp_10_20000_-12_dBFS_48k_Float_LR.wav
: -rw-rw-r-- 1 jj jj 23040044 heinä  22 12:18 audio/Sine_1000_-12_dBFS_48k_Float_LR.wav
: -rw-rw-r-- 1 jj jj  4718636 heinä  22 12:49 audio/256kMeasSweep_100_to_5000_-12_dBFS_48k_Float_LR_refL.wav
: -rw-rw-r-- 1 jj jj  4718636 heinä  22 12:56 audio/256kMeasSweep_20_to_20000_-12_dBFS_48k_Float_LR_refL.wav
: -rw-rw-r-- 1 jj jj  4718636 heinä  22 12:59 audio/256kMeasSweep_50_to_20000_-12_dBFS_48k_Float_LR_refL.wav
: -rw-rw-r-- 1 jj jj  4718636 heinä  22 13:02 audio/256kMeasSweep_100_to_20000_-12_dBFS_48k_Float_LR_refL.wav
: -rw-rw-r-- 1 jj jj  4718636 heinä  22 13:04 audio/256kMeasSweep_100_to_15000_-12_dBFS_48k_Float_LR_refL.wav

Using test signal in AUDIO_FILE
#+call: audio-analysis-doc[:dir .]()

#+RESULTS:
: Running in /home/jj/work/jrr for user 'jj' on host 'Leo' on ke 22.7.2026 13.04.54 +0300
: AUDIO_FILE=audio/256kMeasSweep_100_to_15000_-12_dBFS_48k_Float_LR_refL.wav
: -rw-rw-r-- 1 jj jj 4718636 heinä  22 13:04 audio/256kMeasSweep_100_to_15000_-12_dBFS_48k_Float_LR_refL.wav

Copy AUDIO_FILE to AUDIO_TARGET_SSH into 'tmp' -directory
#+call: audio-analysis-copy[:dir .]()

#+RESULTS:
: Running in /home/jj/work/jrr for user 'jj' on host 'Leo' on ke 22.7.2026 13.04.57 +0300

Show audio analysis files playable on remote
#+call: audio-analysis-playable()

#+RESULTS:
: Running in /home2/jrr for user 'jrr' on host 'jrr5x1' on Wed Jul 22 13:05:04 EEST 2026
: -rw-rw-r-- 1 jrr jrr 23040044 Jul 22 12:28 tmp/Sine_1000_-12_dBFS_48k_Float_LR.wav
: -rw-rw-r-- 1 jrr jrr  3840044 Jul 22 12:38 tmp/LinSwp_10_20000_-12_dBFS_48k_Float_LR.wav
: -rw-rw-r-- 1 jrr jrr  4718636 Jul 22 12:51 tmp/256kMeasSweep_100_to_5000_-12_dBFS_48k_Float_LR_refL.wav
: -rw-rw-r-- 1 jrr jrr  4718636 Jul 22 12:57 tmp/256kMeasSweep_20_to_20000_-12_dBFS_48k_Float_LR_refL.wav
: -rw-rw-r-- 1 jrr jrr  4718636 Jul 22 13:00 tmp/256kMeasSweep_50_to_20000_-12_dBFS_48k_Float_LR_refL.wav
: -rw-rw-r-- 1 jrr jrr  4718636 Jul 22 13:02 tmp/256kMeasSweep_100_to_20000_-12_dBFS_48k_Float_LR_refL.wav
: -rw-rw-r-- 1 jrr jrr  4718636 Jul 22 13:04 tmp/256kMeasSweep_100_to_15000_-12_dBFS_48k_Float_LR_refL.wav

#+call: audio-analysis-play()

#+RESULTS:
#+begin_example
Running in /home2/jrr for user 'jrr' on host 'jrr5x1' on Wed Jul 22 13:10:01 EEST 2026
20260722-13:10:02: jrr/src/jrr_streamer.sh|init_ALSA_CARD: starting with ALSA_CARD=''
20260722-13:10:02: jrr/src/jrr_streamer.sh|init_ALSA_CARD: done with ALSA_CARD='Audio '
20260722-13:10:02: jrr/src/jrr_streamer.sh|set_alsa_volume: card=Audio , volume=95%
Simple mixer control 'Headphone',0
  Capabilities: pvolume pswitch pswitch-joined
  Playback channels: Front Left - Front Right
  Limits: Playback 0 - 175
  Mono:
  Front Left: Playback 166 [95%] [-3.38dB] [on]
  Front Right: Playback 166 [95%] [-3.38dB] [on]
Running in host 'jrr5x1' on Wed Jul 22 13:10:02 EEST 2026
20260722-13:10:02: jrr/src/jrr_streamer.sh|AUDIO_OUT=hw:CARD=Audio,DEV=0, URL=tmp/256kMeasSweep_100_to_15000_-12_dBFS_48k_Float_LR_refL.wav, GAIN=1.5
+ ffmpeg -hide_banner -nostdin -nostats -loglevel error -i tmp/256kMeasSweep_100_to_15000_-12_dBFS_48k_Float_LR_refL.wav -filter_complex '[0:a]volume=volume=1.5,pan=mono|c0=0.5*c0+0.5*c1,alimiter[aout]' -map '[aout]' -ac 2 -f alsa hw:CARD=Audio,DEV=0
#+end_example

*** Audio analysis sine 1kHz -12dBFS 48k LR
:PROPERTIES:
:header-args+: :var  AUDIO_FILE="audio/Sine_1000_-12_dBFS_48k_Float_LR.wav"
:END:

Using test signal in AUDIO_FILE
#+call: audio-analysis-doc[:dir .]()

#+RESULTS:
: Running in /home/jj/work/jrr for user 'jj' on host 'Leo' on ke 22.7.2026 12.27.23 +0300
: AUDIO_FILE=audio/Sine_1000_-12_dBFS_48k_Float_LR.wav
: -rw-rw-r-- 1 jj jj 23040044 heinä  22 12:18 audio/Sine_1000_-12_dBFS_48k_Float_LR.wav

Show availables test signals in ~audio~ -directory

#+call: audio-analysis-show-all[:dir .]()

#+RESULTS:
: Running in /home/jj/work/jrr for user 'jj' on host 'Leo' on ke 22.7.2026 12.27.54 +0300
: -rw-rw-r-- 1 jj jj  3840044 heinä  22 10:25 audio/LinSwp_10_20000_-12_dBFS_48k_Float_LR.wav
: -rw-rw-r-- 1 jj jj 23040044 heinä  22 12:18 audio/Sine_1000_-12_dBFS_48k_Float_LR.wav

Copy AUDIO_FILE to AUDIO_TARGET_SSH into 'tmp' -directory
#+call: audio-analysis-copy[:dir .]()

#+RESULTS:
: Running in /home/jj/work/jrr for user 'jj' on host 'Leo' on ke 22.7.2026 12.28.12 +0300

Show audio analysis files playable on remote
#+call: audio-analysis-playable()

#+RESULTS:
: Running in /home2/jrr for user 'jrr' on host 'jrr5x1' on Wed Jul 22 12:39:12 EEST 2026
: -rw-rw-r-- 1 jrr jrr 23040044 Jul 22 12:28 tmp/Sine_1000_-12_dBFS_48k_Float_LR.wav
: -rw-rw-r-- 1 jrr jrr  3840044 Jul 22 12:38 tmp/LinSwp_10_20000_-12_dBFS_48k_Float_LR.wav

#+call: audio-analysis-play()

*** Audio analysis sine 30Hz -12dBFS 48k LR
:PROPERTIES:
:header-args+: :var  AUDIO_FILE="audio/Sine_30_-12_dBFS_48k_Float_LR.wav"
:END:

Using test signal in AUDIO_FILE
#+call: audio-analysis-doc[:dir .]()

#+RESULTS:
: Running in /home/jj/work/jrr for user 'jj' on host 'Leo' on ke 22.7.2026 13.48.12 +0300
: AUDIO_FILE=audio/Sine_30_-12_dBFS_48k_Float_LR.wav
: -rw-rw-r-- 1 jj jj 3840044 heinä  22 13:47 audio/Sine_30_-12_dBFS_48k_Float_LR.wav

Show availables test signals in ~audio~ -directory

#+call: audio-analysis-show-all[:dir .]()

#+RESULTS:
#+begin_example
Running in /home/jj/work/jrr for user 'jj' on host 'Leo' on ke 22.7.2026 13.48.14 +0300
-rw-rw-r-- 1 jj jj  3840044 heinä  22 10:25 audio/LinSwp_10_20000_-12_dBFS_48k_Float_LR.wav
-rw-rw-r-- 1 jj jj 23040044 heinä  22 12:18 audio/Sine_1000_-12_dBFS_48k_Float_LR.wav
-rw-rw-r-- 1 jj jj  4718636 heinä  22 12:49 audio/256kMeasSweep_100_to_5000_-12_dBFS_48k_Float_LR_refL.wav
-rw-rw-r-- 1 jj jj  4718636 heinä  22 12:56 audio/256kMeasSweep_20_to_20000_-12_dBFS_48k_Float_LR_refL.wav
-rw-rw-r-- 1 jj jj  4718636 heinä  22 12:59 audio/256kMeasSweep_50_to_20000_-12_dBFS_48k_Float_LR_refL.wav
-rw-rw-r-- 1 jj jj  4718636 heinä  22 13:02 audio/256kMeasSweep_100_to_20000_-12_dBFS_48k_Float_LR_refL.wav
-rw-rw-r-- 1 jj jj  4718636 heinä  22 13:04 audio/256kMeasSweep_100_to_15000_-12_dBFS_48k_Float_LR_refL.wav
-rw-rw-r-- 1 jj jj  3840044 heinä  22 13:42 audio/Sine_50_-12_dBFS_48k_Float_LR.wav
-rw-rw-r-- 1 jj jj  3840044 heinä  22 13:43 audio/Sine_100_-12_dBFS_48k_Float_LR.wav
-rw-rw-r-- 1 jj jj  3840044 heinä  22 13:45 audio/Sine_75_-12_dBFS_48k_Float_LR.wav
-rw-rw-r-- 1 jj jj  3840044 heinä  22 13:47 audio/Sine_30_-12_dBFS_48k_Float_LR.wav
#+end_example

Copy AUDIO_FILE to AUDIO_TARGET_SSH into 'tmp' -directory
#+call: audio-analysis-copy[:dir .]()

#+RESULTS:
: Running in /home/jj/work/jrr for user 'jj' on host 'Leo' on ke 22.7.2026 13.48.17 +0300

Show audio analysis files playable on remote
#+call: audio-analysis-playable()

#+RESULTS:
#+begin_example
Running in /home2/jrr for user 'jrr' on host 'jrr5x1' on Wed Jul 22 13:48:21 EEST 2026
-rw-rw-r-- 1 jrr jrr 23040044 Jul 22 12:28 tmp/Sine_1000_-12_dBFS_48k_Float_LR.wav
-rw-rw-r-- 1 jrr jrr  3840044 Jul 22 12:38 tmp/LinSwp_10_20000_-12_dBFS_48k_Float_LR.wav
-rw-rw-r-- 1 jrr jrr  4718636 Jul 22 12:51 tmp/256kMeasSweep_100_to_5000_-12_dBFS_48k_Float_LR_refL.wav
-rw-rw-r-- 1 jrr jrr  4718636 Jul 22 12:57 tmp/256kMeasSweep_20_to_20000_-12_dBFS_48k_Float_LR_refL.wav
-rw-rw-r-- 1 jrr jrr  4718636 Jul 22 13:00 tmp/256kMeasSweep_50_to_20000_-12_dBFS_48k_Float_LR_refL.wav
-rw-rw-r-- 1 jrr jrr  4718636 Jul 22 13:02 tmp/256kMeasSweep_100_to_20000_-12_dBFS_48k_Float_LR_refL.wav
-rw-rw-r-- 1 jrr jrr  4718636 Jul 22 13:04 tmp/256kMeasSweep_100_to_15000_-12_dBFS_48k_Float_LR_refL.wav
-rw-rw-r-- 1 jrr jrr  3840044 Jul 22 13:43 tmp/Sine_50_-12_dBFS_48k_Float_LR.wav
-rw-rw-r-- 1 jrr jrr  3840044 Jul 22 13:44 tmp/Sine_100_-12_dBFS_48k_Float_LR.wav
-rw-rw-r-- 1 jrr jrr  3840044 Jul 22 13:46 tmp/Sine_75_-12_dBFS_48k_Float_LR.wav
-rw-rw-r-- 1 jrr jrr  3840044 Jul 22 13:48 tmp/Sine_30_-12_dBFS_48k_Float_LR.wav
#+end_example

#+call: audio-analysis-play()

#+RESULTS:
#+begin_example
Running in /home2/jrr for user 'jrr' on host 'jrr5x1' on Wed Jul 22 13:48:25 EEST 2026
20260722-13:48:25: jrr/src/jrr_streamer.sh|init_ALSA_CARD: starting with ALSA_CARD=''
20260722-13:48:25: jrr/src/jrr_streamer.sh|init_ALSA_CARD: done with ALSA_CARD='Audio '
20260722-13:48:25: jrr/src/jrr_streamer.sh|set_alsa_volume: card=Audio , volume=95%
Simple mixer control 'Headphone',0
  Capabilities: pvolume pswitch pswitch-joined
  Playback channels: Front Left - Front Right
  Limits: Playback 0 - 175
  Mono:
  Front Left: Playback 166 [95%] [-3.38dB] [on]
  Front Right: Playback 166 [95%] [-3.38dB] [on]
Running in host 'jrr5x1' on Wed Jul 22 13:48:25 EEST 2026
20260722-13:48:25: jrr/src/jrr_streamer.sh|AUDIO_OUT=hw:CARD=Audio,DEV=0, URL=tmp/Sine_30_-12_dBFS_48k_Float_LR.wav, GAIN=1.5
+ ffmpeg -hide_banner -nostdin -nostats -loglevel error -i tmp/Sine_30_-12_dBFS_48k_Float_LR.wav -filter_complex '[0:a]volume=volume=1.5,pan=mono|c0=0.5*c0+0.5*c1,alimiter[aout]' -map '[aout]' -ac 2 -f alsa hw:CARD=Audio,DEV=0
#+end_example

*** Audio analysis sine 50Hz -12dBFS 48k LR
:PROPERTIES:
:header-args+: :var  AUDIO_FILE="audio/Sine_50_-12_dBFS_48k_Float_LR.wav"
:END:

Using test signal in AUDIO_FILE
#+call: audio-analysis-doc[:dir .]()

#+RESULTS:
: Running in /home/jj/work/jrr for user 'jj' on host 'Leo' on ke 22.7.2026 13.42.59 +0300
: AUDIO_FILE=audio/Sine_50_-12_dBFS_48k_Float_LR.wav
: -rw-rw-r-- 1 jj jj 3840044 heinä  22 13:42 audio/Sine_50_-12_dBFS_48k_Float_LR.wav

Show availables test signals in ~audio~ -directory

#+call: audio-analysis-show-all[:dir .]()

#+RESULTS:
: Running in /home/jj/work/jrr for user 'jj' on host 'Leo' on ke 22.7.2026 13.43.02 +0300
: -rw-rw-r-- 1 jj jj  3840044 heinä  22 10:25 audio/LinSwp_10_20000_-12_dBFS_48k_Float_LR.wav
: -rw-rw-r-- 1 jj jj 23040044 heinä  22 12:18 audio/Sine_1000_-12_dBFS_48k_Float_LR.wav
: -rw-rw-r-- 1 jj jj  4718636 heinä  22 12:49 audio/256kMeasSweep_100_to_5000_-12_dBFS_48k_Float_LR_refL.wav
: -rw-rw-r-- 1 jj jj  4718636 heinä  22 12:56 audio/256kMeasSweep_20_to_20000_-12_dBFS_48k_Float_LR_refL.wav
: -rw-rw-r-- 1 jj jj  4718636 heinä  22 12:59 audio/256kMeasSweep_50_to_20000_-12_dBFS_48k_Float_LR_refL.wav
: -rw-rw-r-- 1 jj jj  4718636 heinä  22 13:02 audio/256kMeasSweep_100_to_20000_-12_dBFS_48k_Float_LR_refL.wav
: -rw-rw-r-- 1 jj jj  4718636 heinä  22 13:04 audio/256kMeasSweep_100_to_15000_-12_dBFS_48k_Float_LR_refL.wav
: -rw-rw-r-- 1 jj jj  3840044 heinä  22 13:42 audio/Sine_50_-12_dBFS_48k_Float_LR.wav

Copy AUDIO_FILE to AUDIO_TARGET_SSH into 'tmp' -directory
#+call: audio-analysis-copy[:dir .]()

#+RESULTS:
: Running in /home/jj/work/jrr for user 'jj' on host 'Leo' on ke 22.7.2026 13.43.04 +0300

Show audio analysis files playable on remote
#+call: audio-analysis-playable()

#+RESULTS:
: Running in /home2/jrr for user 'jrr' on host 'jrr5x1' on Wed Jul 22 13:43:07 EEST 2026
: -rw-rw-r-- 1 jrr jrr 23040044 Jul 22 12:28 tmp/Sine_1000_-12_dBFS_48k_Float_LR.wav
: -rw-rw-r-- 1 jrr jrr  3840044 Jul 22 12:38 tmp/LinSwp_10_20000_-12_dBFS_48k_Float_LR.wav
: -rw-rw-r-- 1 jrr jrr  4718636 Jul 22 12:51 tmp/256kMeasSweep_100_to_5000_-12_dBFS_48k_Float_LR_refL.wav
: -rw-rw-r-- 1 jrr jrr  4718636 Jul 22 12:57 tmp/256kMeasSweep_20_to_20000_-12_dBFS_48k_Float_LR_refL.wav
: -rw-rw-r-- 1 jrr jrr  4718636 Jul 22 13:00 tmp/256kMeasSweep_50_to_20000_-12_dBFS_48k_Float_LR_refL.wav
: -rw-rw-r-- 1 jrr jrr  4718636 Jul 22 13:02 tmp/256kMeasSweep_100_to_20000_-12_dBFS_48k_Float_LR_refL.wav
: -rw-rw-r-- 1 jrr jrr  4718636 Jul 22 13:04 tmp/256kMeasSweep_100_to_15000_-12_dBFS_48k_Float_LR_refL.wav
: -rw-rw-r-- 1 jrr jrr  3840044 Jul 22 13:43 tmp/Sine_50_-12_dBFS_48k_Float_LR.wav

#+call: audio-analysis-play()

#+RESULTS:
#+begin_example
Running in /home2/jrr for user 'jrr' on host 'jrr5x1' on Wed Jul 22 13:43:12 EEST 2026
20260722-13:43:12: jrr/src/jrr_streamer.sh|init_ALSA_CARD: starting with ALSA_CARD=''
20260722-13:43:12: jrr/src/jrr_streamer.sh|init_ALSA_CARD: done with ALSA_CARD='Audio '
20260722-13:43:12: jrr/src/jrr_streamer.sh|set_alsa_volume: card=Audio , volume=95%
Simple mixer control 'Headphone',0
  Capabilities: pvolume pswitch pswitch-joined
  Playback channels: Front Left - Front Right
  Limits: Playback 0 - 175
  Mono:
  Front Left: Playback 166 [95%] [-3.38dB] [on]
  Front Right: Playback 166 [95%] [-3.38dB] [on]
Running in host 'jrr5x1' on Wed Jul 22 13:43:12 EEST 2026
20260722-13:43:12: jrr/src/jrr_streamer.sh|AUDIO_OUT=hw:CARD=Audio,DEV=0, URL=tmp/Sine_50_-12_dBFS_48k_Float_LR.wav, GAIN=1.5
+ ffmpeg -hide_banner -nostdin -nostats -loglevel error -i tmp/Sine_50_-12_dBFS_48k_Float_LR.wav -filter_complex '[0:a]volume=volume=1.5,pan=mono|c0=0.5*c0+0.5*c1,alimiter[aout]' -map '[aout]' -ac 2 -f alsa hw:CARD=Audio,DEV=0
#+end_example

*** Audio analysis sine 75Hz -12dBFS 48k LR
:PROPERTIES:
:header-args+: :var  AUDIO_FILE="audio/Sine_75_-12_dBFS_48k_Float_LR.wav"
:END:

Using test signal in AUDIO_FILE
#+call: audio-analysis-doc[:dir .]()

#+RESULTS:
: Running in /home/jj/work/jrr for user 'jj' on host 'Leo' on ke 22.7.2026 13.45.53 +0300
: AUDIO_FILE=audio/Sine_75_-12_dBFS_48k_Float_LR.wav
: -rw-rw-r-- 1 jj jj 3840044 heinä  22 13:45 audio/Sine_75_-12_dBFS_48k_Float_LR.wav

Show availables test signals in ~audio~ -directory

#+call: audio-analysis-show-all[:dir .]()

#+RESULTS:
#+begin_example
Running in /home/jj/work/jrr for user 'jj' on host 'Leo' on ke 22.7.2026 13.45.59 +0300
-rw-rw-r-- 1 jj jj  3840044 heinä  22 10:25 audio/LinSwp_10_20000_-12_dBFS_48k_Float_LR.wav
-rw-rw-r-- 1 jj jj 23040044 heinä  22 12:18 audio/Sine_1000_-12_dBFS_48k_Float_LR.wav
-rw-rw-r-- 1 jj jj  4718636 heinä  22 12:49 audio/256kMeasSweep_100_to_5000_-12_dBFS_48k_Float_LR_refL.wav
-rw-rw-r-- 1 jj jj  4718636 heinä  22 12:56 audio/256kMeasSweep_20_to_20000_-12_dBFS_48k_Float_LR_refL.wav
-rw-rw-r-- 1 jj jj  4718636 heinä  22 12:59 audio/256kMeasSweep_50_to_20000_-12_dBFS_48k_Float_LR_refL.wav
-rw-rw-r-- 1 jj jj  4718636 heinä  22 13:02 audio/256kMeasSweep_100_to_20000_-12_dBFS_48k_Float_LR_refL.wav
-rw-rw-r-- 1 jj jj  4718636 heinä  22 13:04 audio/256kMeasSweep_100_to_15000_-12_dBFS_48k_Float_LR_refL.wav
-rw-rw-r-- 1 jj jj  3840044 heinä  22 13:42 audio/Sine_50_-12_dBFS_48k_Float_LR.wav
-rw-rw-r-- 1 jj jj  3840044 heinä  22 13:43 audio/Sine_100_-12_dBFS_48k_Float_LR.wav
-rw-rw-r-- 1 jj jj  3840044 heinä  22 13:45 audio/Sine_75_-12_dBFS_48k_Float_LR.wav
#+end_example

Copy AUDIO_FILE to AUDIO_TARGET_SSH into 'tmp' -directory
#+call: audio-analysis-copy[:dir .]()

#+RESULTS:
: Running in /home/jj/work/jrr for user 'jj' on host 'Leo' on ke 22.7.2026 13.46.01 +0300

Show audio analysis files playable on remote
#+call: audio-analysis-playable()

#+RESULTS:
#+begin_example
Running in /home2/jrr for user 'jrr' on host 'jrr5x1' on Wed Jul 22 13:46:06 EEST 2026
-rw-rw-r-- 1 jrr jrr 23040044 Jul 22 12:28 tmp/Sine_1000_-12_dBFS_48k_Float_LR.wav
-rw-rw-r-- 1 jrr jrr  3840044 Jul 22 12:38 tmp/LinSwp_10_20000_-12_dBFS_48k_Float_LR.wav
-rw-rw-r-- 1 jrr jrr  4718636 Jul 22 12:51 tmp/256kMeasSweep_100_to_5000_-12_dBFS_48k_Float_LR_refL.wav
-rw-rw-r-- 1 jrr jrr  4718636 Jul 22 12:57 tmp/256kMeasSweep_20_to_20000_-12_dBFS_48k_Float_LR_refL.wav
-rw-rw-r-- 1 jrr jrr  4718636 Jul 22 13:00 tmp/256kMeasSweep_50_to_20000_-12_dBFS_48k_Float_LR_refL.wav
-rw-rw-r-- 1 jrr jrr  4718636 Jul 22 13:02 tmp/256kMeasSweep_100_to_20000_-12_dBFS_48k_Float_LR_refL.wav
-rw-rw-r-- 1 jrr jrr  4718636 Jul 22 13:04 tmp/256kMeasSweep_100_to_15000_-12_dBFS_48k_Float_LR_refL.wav
-rw-rw-r-- 1 jrr jrr  3840044 Jul 22 13:43 tmp/Sine_50_-12_dBFS_48k_Float_LR.wav
-rw-rw-r-- 1 jrr jrr  3840044 Jul 22 13:44 tmp/Sine_100_-12_dBFS_48k_Float_LR.wav
-rw-rw-r-- 1 jrr jrr  3840044 Jul 22 13:46 tmp/Sine_75_-12_dBFS_48k_Float_LR.wav
#+end_example

#+call: audio-analysis-play()

#+RESULTS:
#+begin_example
Running in /home2/jrr for user 'jrr' on host 'jrr5x1' on Wed Jul 22 13:46:10 EEST 2026
20260722-13:46:10: jrr/src/jrr_streamer.sh|init_ALSA_CARD: starting with ALSA_CARD=''
20260722-13:46:10: jrr/src/jrr_streamer.sh|init_ALSA_CARD: done with ALSA_CARD='Audio '
20260722-13:46:10: jrr/src/jrr_streamer.sh|set_alsa_volume: card=Audio , volume=95%
Simple mixer control 'Headphone',0
  Capabilities: pvolume pswitch pswitch-joined
  Playback channels: Front Left - Front Right
  Limits: Playback 0 - 175
  Mono:
  Front Left: Playback 166 [95%] [-3.38dB] [on]
  Front Right: Playback 166 [95%] [-3.38dB] [on]
Running in host 'jrr5x1' on Wed Jul 22 13:46:10 EEST 2026
20260722-13:46:10: jrr/src/jrr_streamer.sh|AUDIO_OUT=hw:CARD=Audio,DEV=0, URL=tmp/Sine_75_-12_dBFS_48k_Float_LR.wav, GAIN=1.5
+ ffmpeg -hide_banner -nostdin -nostats -loglevel error -i tmp/Sine_75_-12_dBFS_48k_Float_LR.wav -filter_complex '[0:a]volume=volume=1.5,pan=mono|c0=0.5*c0+0.5*c1,alimiter[aout]' -map '[aout]' -ac 2 -f alsa hw:CARD=Audio,DEV=0
#+end_example

*** Audio analysis sine 100Hz -12dBFS 48k LR
:PROPERTIES:
:header-args+: :var  AUDIO_FILE="audio/Sine_100_-12_dBFS_48k_Float_LR.wav"
:END:

Using test signal in AUDIO_FILE
#+call: audio-analysis-doc[:dir .]()

#+RESULTS:
: Running in /home/jj/work/jrr for user 'jj' on host 'Leo' on ke 22.7.2026 13.43.57 +0300
: AUDIO_FILE=audio/Sine_100_-12_dBFS_48k_Float_LR.wav
: -rw-rw-r-- 1 jj jj 3840044 heinä  22 13:43 audio/Sine_100_-12_dBFS_48k_Float_LR.wav

Show availables test signals in ~audio~ -directory

#+call: audio-analysis-show-all[:dir .]()

#+RESULTS:
#+begin_example
Running in /home/jj/work/jrr for user 'jj' on host 'Leo' on ke 22.7.2026 13.44.00 +0300
-rw-rw-r-- 1 jj jj  3840044 heinä  22 10:25 audio/LinSwp_10_20000_-12_dBFS_48k_Float_LR.wav
-rw-rw-r-- 1 jj jj 23040044 heinä  22 12:18 audio/Sine_1000_-12_dBFS_48k_Float_LR.wav
-rw-rw-r-- 1 jj jj  4718636 heinä  22 12:49 audio/256kMeasSweep_100_to_5000_-12_dBFS_48k_Float_LR_refL.wav
-rw-rw-r-- 1 jj jj  4718636 heinä  22 12:56 audio/256kMeasSweep_20_to_20000_-12_dBFS_48k_Float_LR_refL.wav
-rw-rw-r-- 1 jj jj  4718636 heinä  22 12:59 audio/256kMeasSweep_50_to_20000_-12_dBFS_48k_Float_LR_refL.wav
-rw-rw-r-- 1 jj jj  4718636 heinä  22 13:02 audio/256kMeasSweep_100_to_20000_-12_dBFS_48k_Float_LR_refL.wav
-rw-rw-r-- 1 jj jj  4718636 heinä  22 13:04 audio/256kMeasSweep_100_to_15000_-12_dBFS_48k_Float_LR_refL.wav
-rw-rw-r-- 1 jj jj  3840044 heinä  22 13:42 audio/Sine_50_-12_dBFS_48k_Float_LR.wav
-rw-rw-r-- 1 jj jj  3840044 heinä  22 13:43 audio/Sine_100_-12_dBFS_48k_Float_LR.wav
#+end_example

Copy AUDIO_FILE to AUDIO_TARGET_SSH into 'tmp' -directory
#+call: audio-analysis-copy[:dir .]()

#+RESULTS:
: Running in /home/jj/work/jrr for user 'jj' on host 'Leo' on ke 22.7.2026 13.44.02 +0300

Show audio analysis files playable on remote
#+call: audio-analysis-playable()

#+RESULTS:
#+begin_example
Running in /home2/jrr for user 'jrr' on host 'jrr5x1' on Wed Jul 22 13:44:06 EEST 2026
-rw-rw-r-- 1 jrr jrr 23040044 Jul 22 12:28 tmp/Sine_1000_-12_dBFS_48k_Float_LR.wav
-rw-rw-r-- 1 jrr jrr  3840044 Jul 22 12:38 tmp/LinSwp_10_20000_-12_dBFS_48k_Float_LR.wav
-rw-rw-r-- 1 jrr jrr  4718636 Jul 22 12:51 tmp/256kMeasSweep_100_to_5000_-12_dBFS_48k_Float_LR_refL.wav
-rw-rw-r-- 1 jrr jrr  4718636 Jul 22 12:57 tmp/256kMeasSweep_20_to_20000_-12_dBFS_48k_Float_LR_refL.wav
-rw-rw-r-- 1 jrr jrr  4718636 Jul 22 13:00 tmp/256kMeasSweep_50_to_20000_-12_dBFS_48k_Float_LR_refL.wav
-rw-rw-r-- 1 jrr jrr  4718636 Jul 22 13:02 tmp/256kMeasSweep_100_to_20000_-12_dBFS_48k_Float_LR_refL.wav
-rw-rw-r-- 1 jrr jrr  4718636 Jul 22 13:04 tmp/256kMeasSweep_100_to_15000_-12_dBFS_48k_Float_LR_refL.wav
-rw-rw-r-- 1 jrr jrr  3840044 Jul 22 13:43 tmp/Sine_50_-12_dBFS_48k_Float_LR.wav
-rw-rw-r-- 1 jrr jrr  3840044 Jul 22 13:44 tmp/Sine_100_-12_dBFS_48k_Float_LR.wav
#+end_example

#+call: audio-analysis-play()

#+RESULTS:
#+begin_example
Running in /home2/jrr for user 'jrr' on host 'jrr5x1' on Wed Jul 22 13:44:11 EEST 2026
20260722-13:44:11: jrr/src/jrr_streamer.sh|init_ALSA_CARD: starting with ALSA_CARD=''
20260722-13:44:11: jrr/src/jrr_streamer.sh|init_ALSA_CARD: done with ALSA_CARD='Audio '
20260722-13:44:11: jrr/src/jrr_streamer.sh|set_alsa_volume: card=Audio , volume=95%
Simple mixer control 'Headphone',0
  Capabilities: pvolume pswitch pswitch-joined
  Playback channels: Front Left - Front Right
  Limits: Playback 0 - 175
  Mono:
  Front Left: Playback 166 [95%] [-3.38dB] [on]
  Front Right: Playback 166 [95%] [-3.38dB] [on]
Running in host 'jrr5x1' on Wed Jul 22 13:44:11 EEST 2026
20260722-13:44:11: jrr/src/jrr_streamer.sh|AUDIO_OUT=hw:CARD=Audio,DEV=0, URL=tmp/Sine_100_-12_dBFS_48k_Float_LR.wav, GAIN=1.5
+ ffmpeg -hide_banner -nostdin -nostats -loglevel error -i tmp/Sine_100_-12_dBFS_48k_Float_LR.wav -filter_complex '[0:a]volume=volume=1.5,pan=mono|c0=0.5*c0+0.5*c1,alimiter[aout]' -map '[aout]' -ac 2 -f alsa hw:CARD=Audio,DEV=0
#+end_example

*** Audio analysis linear sweep 100Hz-5kHz -12dBFS 48k LR
:PROPERTIES:
:header-args+: :var  AUDIO_FILE="audio/256kMeasSweep_100_to_5000_-12_dBFS_48k_Float_LR_refL.wav"
:END:

Show availables test signals in ~audio~ -directory

#+call: audio-analysis-show-all[:dir .]()

#+RESULTS:
: Running in /home/jj/work/jrr for user 'jj' on host 'Leo' on ke 22.7.2026 12.51.15 +0300
: -rw-rw-r-- 1 jj jj  3840044 heinä  22 10:25 audio/LinSwp_10_20000_-12_dBFS_48k_Float_LR.wav
: -rw-rw-r-- 1 jj jj 23040044 heinä  22 12:18 audio/Sine_1000_-12_dBFS_48k_Float_LR.wav
: -rw-rw-r-- 1 jj jj  4718636 heinä  22 12:49 audio/256kMeasSweep_100_to_5000_-12_dBFS_48k_Float_LR_refL.wav

Using test signal in AUDIO_FILE
#+call: audio-analysis-doc[:dir .]()

#+RESULTS:
: Running in /home/jj/work/jrr for user 'jj' on host 'Leo' on ke 22.7.2026 12.51.31 +0300
: AUDIO_FILE=audio/256kMeasSweep_100_to_5000_-12_dBFS_48k_Float_LR_refL.wav
: -rw-rw-r-- 1 jj jj 4718636 heinä  22 12:49 audio/256kMeasSweep_100_to_5000_-12_dBFS_48k_Float_LR_refL.wav

Copy AUDIO_FILE to AUDIO_TARGET_SSH into 'tmp' -directory
#+call: audio-analysis-copy[:dir .]()

#+RESULTS:
: Running in /home/jj/work/jrr for user 'jj' on host 'Leo' on ke 22.7.2026 12.51.36 +0300

Show audio analysis files playable on remote
#+call: audio-analysis-playable()

#+RESULTS:
: Running in /home2/jrr for user 'jrr' on host 'jrr5x1' on Wed Jul 22 12:51:41 EEST 2026
: -rw-rw-r-- 1 jrr jrr 23040044 Jul 22 12:28 tmp/Sine_1000_-12_dBFS_48k_Float_LR.wav
: -rw-rw-r-- 1 jrr jrr  3840044 Jul 22 12:38 tmp/LinSwp_10_20000_-12_dBFS_48k_Float_LR.wav
: -rw-rw-r-- 1 jrr jrr  4718636 Jul 22 12:51 tmp/256kMeasSweep_100_to_5000_-12_dBFS_48k_Float_LR_refL.wav

#+call: audio-analysis-play()

#+RESULTS:
#+begin_example
Running in /home2/jrr for user 'jrr' on host 'jrr5x1' on Wed Jul 22 12:54:45 EEST 2026
20260722-12:54:45: jrr/src/jrr_streamer.sh|init_ALSA_CARD: starting with ALSA_CARD=''
20260722-12:54:45: jrr/src/jrr_streamer.sh|init_ALSA_CARD: done with ALSA_CARD='Audio '
20260722-12:54:45: jrr/src/jrr_streamer.sh|set_alsa_volume: card=Audio , volume=95%
Simple mixer control 'Headphone',0
  Capabilities: pvolume pswitch pswitch-joined
  Playback channels: Front Left - Front Right
  Limits: Playback 0 - 175
  Mono:
  Front Left: Playback 166 [95%] [-3.38dB] [on]
  Front Right: Playback 166 [95%] [-3.38dB] [on]
Running in host 'jrr5x1' on Wed Jul 22 12:54:45 EEST 2026
20260722-12:54:45: jrr/src/jrr_streamer.sh|AUDIO_OUT=hw:CARD=Audio,DEV=0, URL=tmp/256kMeasSweep_100_to_5000_-12_dBFS_48k_Float_LR_refL.wav, GAIN=1.5
+ ffmpeg -hide_banner -nostdin -nostats -loglevel error -i tmp/256kMeasSweep_100_to_5000_-12_dBFS_48k_Float_LR_refL.wav -filter_complex '[0:a]volume=volume=1.5,pan=mono|c0=0.5*c0+0.5*c1,alimiter[aout]' -map '[aout]' -ac 2 -f alsa hw:CARD=Audio,DEV=0
#+end_example

* Fin                                                              :noexport:

** Emacs variables

#+RESULTS:

# Local Variables:
# time-stamp-line-limit: -8
# time-stamp-start: "Modified:"
# time-stamp-format: "%:y-%02m-%02d.%02H:%02M"
# time-stamp-time-zone: nil
# time-stamp-end: "; # time-stamp"
# eval: (add-hook 'before-save-hook 'time-stamp)
# org-confirm-babel-evaluate: nil
# eval: (setq-local org-format-latex-options
#                   (plist-put org-format-latex-options :scale 1.5))
# End:
#
# Muuta
# org-cdlatex-mode: t
# eval: (cdlatex-mode)
#
# Local ebib:
# org-ref-default-bibliography: "./jrr-rew.bib"
# org-ref-bibliography-notes: "./jrr-rew-notes.org"
# org-ref-pdf-directory: "./pdf/"
# org-ref-notes-directory: "."
# bibtex-completion-notes-path: "./jrr-rew-notes.org"
# ebib-preload-bib-files: ("./jrr-rew.bib")
# ebib-notes-file: ("./jrr-rew-notes.org")
# reftex-default-bibliography: ("./jrr-rew.bib")

Modified:2026-07-28.14:20; # time-stamp

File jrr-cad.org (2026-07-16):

#+PROPERTY: header-args+ :var  MEM_STICK="/media/jj/jj"
#+PROPERTY: header-args+ :var  PROJECT="jrr"
#+PROPERTY: header-args+ :var  RELEASE="2"

#+LATEX: \setlength{\parindent}{0pt}
#+options: ':nil *:t -:t ::t <:t H:3 \n:t ^:nil arch:headline

* Koten MDF levyjen leikkaus

Kotelon osat 3:lle radiolle 600 mm x 800 mm x 19 mm MDF levystä leikattaessa:
- 6 kpl x 232mm x 138mm
- 6 kpl x 232mm x 100mm
- 6 kpl x 100mm x 100mm   

Leikkaussuunnitelma 600 mm x 800 mm levylle:

| 232mm+232mm+100 = 564mm => | 232mm sorko | 232mm sorko | 100mm  sorko |
|---------------------------+-------------+-------------+--------------|
|                           |         138 |         138 |          100 |
|                           |         138 |         100 |          100 |
|                           |         138 |         100 |          100 |
|                           |         138 |         100 |          100 |
|                           |         138 |         100 |          100 |
|                           |         100 |         100 |          100 |
|---------------------------+-------------+-------------+--------------|
| Yhteensä < 800mm          |         790 |         638 |          600 |
#+TBLFM: @>$2=vsum(@I..@II)::@>$3=vsum(@I..@II)::@>$4=vsum(@I..@II)

* Kotelon jyrsintä
** Katon aukkojen jyrsintä

[[file:cad/pages/katto.pdf]]

Jyrsintätiedostot [[file:cad/jyrsi/katto]]

- Origo: xy, keskelle aihiota, z=0 aihion yläpinnalle
- Jyrsintä:
  - 3.2mm poraterällä:
    - katto-01-nappainreijat-pora.ngc
  - 4mm x 20mm terällä:
    - +katto-01-nappainreijat-04mm.ngc+
    - katto-02-liitin-04mm.ngc
  - 6mm x 20mm terällä
    - katto-03-naytto-06mm.ngc

** Etuseinän aukkojen jyrsintä

[[file:cad/pages/etuseinä.pdf]]

- Origo: xy, keskelle aihiota, z=0 aihion yläpinnalle
- Jyrsintä:
  - 6mm x 20mm terällä
    - etukytkin-helix-6mm-rev01.ngc
    - etu-pls-upotus-millface-6mm-rel02.ngc 
    - etu-pls-reunat.ngc
    - etu-pls-läpi-18mm-6mm-rel02.ngc
  
** Takaseinän aukkojen jyrsintä

[[file:cad/pages/takaseinä.pdf]]

- Origo: xy, vasen alareuna
  - 6mm terä ja 3mm pora -> touch off (x,y,z) = (-6, -6, 3)
- Jyrsintä:
  - 6mm x 20mm terällä
    - Zigzag jyrsin: [[file:cad/jyrsi/taka/taka-keystone-vasen-6mm-rev2.ngc]]
    - Reunojen siivous: [[file:cad/jyrsi/taka/taka-keystone-vasen-6mm-profile-rev2.ngc]]
    - Kytkin helix -jyrsintä:  [[file:cad/jyrsi/taka/taka-kytkin-vasen-helix-6mm-rev2.ngc]] 
- TBD: origo ??
    - TBDtaka-keystone-oikea.ngc (mikäli kalustetaan RC input:lle)

** +Lattian kaiverrus+
:PROPERTIES:
:header-args+: :var  GERBERS="cad/laseroinnit/url/gerbers"
:header-args+: :var  ETOOLGERBERS="/home/jj/Documents/etool/01-gerber"
:header-args+:   :var  GERB="url-F_Cu"
:END:

Kaiverruksen gerber -tiedostot ovat hakemistossa

#+BEGIN_SRC bash :eval no-export :results file :exports results
echo "Running in $(pwd) host '$(hostname)' on $(date)" 1>&2
echo -n "$GERBERS"
#+END_SRC

#+RESULTS:
[[file:cad/laseroinnit/url/gerbers]]

Tyhjennetään työhakemisto  ~Documents/etool~
#+BEGIN_SRC bash :eval no-export :results output :exports none
echo "Running in $(pwd) host '$(hostname)' on $(date)"
rm -rf /home/jj/Documents/etool
etool.sh ls
#+END_SRC

#+RESULTS:
#+begin_example
Running in /home/jj/work/jrr host 'eero' on pe 1.8.2025 10.01.15 +0300
DISPLAY=:1
Created ETOOL_DIR=/home/jj/Documents/etool
Directory /etool/01-gerber created
Directory /etool/01-image created
Directory /etool/02-ngc created
Directory /etool/02-silk created
Directory /etool/linuxcnc/configs/sim.axis created
File /etool/pcb2gcode-3-grooves.ini created
File /etool/pcb2gcode-control-3-grooves.template created
File /etool/pcb2gcode-control.template created
File /etool/pcb2gcode.ini created
File /etool/linuxcnc/configs/sim.axis/axis_etool.ini created
File /etool/linuxcnc/configs/sim.axis/sim_mm.tbl created
File /etool/.linuxcncrc created
/etool/01-gerber:
total 0

/etool/01-image:
total 0

/etool/02-ngc:
total 0

/etool/02-silk:
total 0
#+end_example

Päivitetään etool konfiguraatiotiedostoa
~/home/jj/Documents/etool/pcb2gcode.ini~ estämällä 'autoleveling'
-toiminto.

#+BEGIN_SRC bash :eval no-export :results output :exports results
echo "Running in $(pwd) host '$(hostname)' on $(date)" >&2
FILE=/home/jj/Documents/etool/pcb2gcode.ini

sed -e 's/al-front=./al-front=0/' -i $FILE
sed -e 's/al-back=./al-back=0/' -i $FILE
sed -e 's/isolation-width=[0-9\.]*/isolation-width=0.1/' -i $FILE
grep -e 'al-front' -e 'al-back' -e 'isolation-width' $FILE
#+END_SRC

#+RESULTS:
: al-front=0             # enable 1, disable 0 z autoleveller front layer
: al-back=0              # enable 1, disable 0 z autoleveller back layer
: isolation-width=0.1mm # min width between copper surfaces
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

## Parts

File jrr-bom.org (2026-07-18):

* BOM
** Piirilevy

[[file:jrr-pcb.org]]

** Materiaalit

\tiny
| Käyttökohde       | Materiaali                                 | Toimittaja                 | Hinta |
|-------------------+--------------------------------------------+----------------------------+-------|
| Kotelon liimaus   | EriKeeper                                  | Bauhaus                    | 10.00 |
| Kotelon liimaus   | Lamelli 0                                  | Bauhaus                    |     5 |
| Pohjamaali        | Futura Aqua3 Primer Val                    | [[file:bom/2026-01-16-pintaväri.pdf][Pintaväri Oy]]               | 29.50 |
| Harmaa            | Futura Aqua40 0.9l, puolikiiltävä, RAL7004 | [[file:bom/2026-01-16-pintaväri.pdf][Pintaväri Oy]]               | 46.80 |
| Punainen          | [[file:bom/2020-03-10-spraymaali.jpg][Montana Gold, 400ML, 3070 purple red]]       | [[https://www.decovari.fi/][Decoväri]]                   | 10.00 |
| Kaiutin pölysuoja | Fender style black kaiutin kangas, 60x60cm | [[https://uraltone.com/fender-style-black-kaiutinkangas-grill-cloth-60x60cm.html][Uraltone 926-F-BLACK-60x60]] |    9. |
|-------------------+--------------------------------------------+----------------------------+-------|
|                   | Yhteensä                                   |                            |  80.9 |
#+TBLFM: @>$4=vsum(@I..@II)

** Osat

\tiny
| S[fn:S] | Kohde                       | Koodi               | Toimittaja                          | Kpl | A-hinta |    Yht | Huom   |
|---------+-----------------------------+---------------------+-------------------------------------+-----+---------+--------+--------|
| E       | Vahvistin                   | [[file:bom/PAM8403-datasheet.pdf][PAM8403]]             | [[https://uraltone.com/vahvistinmoduli-pam8403-class-d-2x3w.html][Uraltone 190-PAM8403-2x3W-AMP]]       |   1 |     5.0 |     5. |        |
| E       | USB-A/3.5mm DAC muunnin     | ALC5686             | [[https://www.aliexpress.com/item/1005004358120260.html][Axpress 1005004358120260]]            |   1 |    7.85 |   7.85 |        |
| E       | Nuppi/vahvistin             | 6mm,20mm/phi,16mm/h | [[https://www.aliexpress.com/item/1005007000845408.html][Axpress 1005007000845408]]            |   1 |         |      0 |        |
| E       | Nupin jatkovarsi            | 6mm,10mm/phi,25mm/h | [[https://www.aliexpress.com/item/1005006549662711.html][Axpress 1005006549662711]]            |   1 |         |      0 |        |
| E       | Vahvistimen asennuslevy     |                     | Laserleikkaus                       |   1 |       0 |      0 |        |
| E       | Rampamuhvi/vahvistin        | M3X10X6             | [[https://www.ruuvikeskus.fi/?tuote=315-7-0310061][Ruuvikeskus 315-7-0310061]]           |   4 |    0.41 |   1.64 |        |
| E       | Pultti/vahvistin            | M3x10mm             |                                     |   4 |    0.02 |   0.08 |        |
| E       | Kaiutinelementti            | [[file:bom/peerless-830986.pdf][PLS-P830986]]         | [[https://www.soundimports.eu/en/peerless-by-tymphany-pls-p830986.html][SoundImports PLS-P830986]]            |   1 |   28.45 |  28.45 |        |
| E       | Rampamuhvi/kaiutin          | M3X10X6             | [[file:bom/RAMPAMUTTERI ST M3X10X6 .png][Ruuvikeskus]]                         |   4 |    0.41 |   1.64 |        |
| E       | Pultti/kaiutin              | M3x16mm, musta      | [[https://www.aliexpress.com/item/1005003640558992.html][Axpress 1005003640558992 M3,16mm]]    |   4 |    0.08 |   0.32 |        |
| E       | Asennuskehys/kaiutin        | [[file:cad/laseroinnit/LaseroiKaiutinRengas.pdf][KaiutinRengas.pdf]]   | Laserleikkaus                       |   2 |       0 |      0 |        |
|---------+-----------------------------+---------------------+-------------------------------------+-----+---------+--------+--------|
| KS      | Tietokone                   | Raspberry Pi 3 B+   | [[https://raspberrypi.dk/fi][raspberrypi.dk]] [[https://raspberrypi.dk/fi/tuote/raspberry-pi-3-model-b-2][8211 (RPI 3B+) ]]      |   1 |   44.11 |  44.11 |        |
| KS      | Korotushylsy/piirilevy      | M3x8mm              |                                     |   3 |         |      0 |        |
| KS      | Korotushylsy/piirilevy      | M5x8mm              |                                     |   3 |         |      0 |        |
| KS      | Piirilevy                   | schema/jrr5         | JCLPCB                              |   1 |       5 |      5 |        |
| KS      | Rampamuhvi, DIN 7965        | M3X10X6             | [[https://www.ruuvikeskus.fi/?tuote=315-7-0310061][Ruuvikeskus 315-7-0310061]]           |   5 |    0.41 |   2.46 | [fn:1] |
| KS      | Korotushylsy/piirilevy      | M3x8mm              |                                     |   5 |         |      0 |        |
| KS      | Piirilevyjen kiinnitys      | M3x25, 6-kolo       |                                     |   3 |         |        |        |
| KS      | Piirilevyjen kiinnitys      | M3x10, 6kolo        |                                     |   2 |         |        |        |
|---------+-----------------------------+---------------------+-------------------------------------+-----+---------+--------+--------|
| KU      | TFT3.52 näyttö              | [[file:bom/MHS3.5-display.pdf][ILI9486]]             | [[https://www.aliexpress.com/item/1005008964389076.html?spm=a2g0o.order_list.order_list_main.52.10b9180265YXoP][Axpress]]                             |   1 |   14.40 |   14.4 |        |
| KU      | Asennuskehys/näyttö         | [[file:cad/laseroinnit/LaserointiNäyttöKehys.pdf][NäyttöKehys.pdf]]     | Laserleikkaus                       |   1 |       0 |      0 |        |
| KU      | Ruuvi/näyttö                | M2.9x?? musta       |                                     |     |         |        |        |
|---------+-----------------------------+---------------------+-------------------------------------+-----+---------+--------+--------|
| T       | Keystone panelisovitin      | [[file:bom/KAPMAmc_eng_tds.pdf][KAPMA#20]]            | [[https://www.distrelec.nl/en/panel-mount-adaptor-metal-pack-of-20-pieces-tuk-limited-kapma-20/p/30134977][Elfa 301-34-977]]                     |   4 |    1.66 |   3.32 | [fn:2] |
| T       | Pultti  keystone kiinnitys  | M3x25               |                                     |   6 |         |        | [fn:3] |
| T       | Mutteri  keystone kiinnitys | M3                  |                                     |   6 |         |        | [fn:3] |
| T       | Keystone USB-C/USB-C        |                     | [[https://www.aliexpress.com/item/1005007356362854.html][Axpress 1005007356362854 White,5pcs]] |   1 |    1.56 |   1.56 |        |
| T       | Keystone USB-A/USB-A        |                     | [[https://www.aliexpress.com/item/1005005600484996.html][Axpress 1005005600484996 White,5PCS]] |   1 |    1.32 |   1.32 |        |
| T       | USB-C/USC-C jatko 0.5       |                     |                                     |   1 |         |        | [fn:5] |
| T       | USB-C 90-aste kulma         |                     |                                     |   1 |         |        | [fn:5] |
| T       | USB-A/USC-A jatko 0.5       |                     |                                     |   1 |         |        | [fn:4] |
| T       | Rampamuhvi                  | M4x8mmx12mm         | Helakauppa                          |   6 |     1.4 |    8.4 |        |
| T       | Pultti takaseinän kiinnitys | M4x30mm,A4,upotus   | [[https://www.aliexpress.com/item/1005007838338973.html][Axpress 1005007838338973 M4,30mm]]    |   6 |    0.14 |   0.84 |        |
| TR      | Keystone panelisovitin      | [[file:bom/KAPMAmc_eng_tds.pdf][KAPMA#20]]            | [[https://www.distrelec.nl/en/panel-mount-adaptor-metal-pack-of-20-pieces-tuk-limited-kapma-20/p/30134977][Elfa 301-34-977]]                     |   2 |    1.66 |   3.32 |        |
| TR      | Liukukytkin                 | SPDT,15mm           | [[https://www.partco.fi/fi/saehkoemekaniikka/kytkimet/liukukytkimet/7283-kyt-liu15.html][Partco KYT LIU15]]                    |   1 |     0.5 |    0.5 |        |
| TR      | Liukukytkin sovitin         |                     | 3D tulostus                         |   1 |     0.5 |    0.5 |        |
| TR      | Keystonone RCA              |                     |                                     |     |         |      0 |        |
|---------+-----------------------------+---------------------+-------------------------------------+-----+---------+--------+--------|
| P       | Kumitassu                   | \phi5mm/22x13mm     | [[https://www.partco.fi/fi/mekaniikka/kotelointi/kotelotarvikkeet/21895-kot-g050.html][Partco KOT G050]]                     |   4 |    0.36 |   1.44 |        |
| P       | Pultti/tassu                | M4x30mm             |                                     |   4 |    0.05 |    0.2 |        |
| P       | Mutteri                     | M4                  |                                     |   4 |    0.05 |    0.2 |        |
| P       | Aluslevy                    | M4                  |                                     |   8 |    0.02 |   0.16 |        |
|---------+-----------------------------+---------------------+-------------------------------------+-----+---------+--------+--------|
|         | *YHTEENSÄ*                  |                     |                                     |     |         | 132.59 |        |
#+TBLFM: $7=$5*$6::@>$7=vsum(@I..@IIIII)

[fn:S] E=Etusivu, KS=sisäkatto, KU=ulkokatto, T=takasivu, TR=takasivu, RC liitin, P=pohja

[fn:1] Kuudes rampamuhvi tulisi liian lähellä IDC liittimen aukkoa, siksi 5 ruuvin paikkaa

[fn:2] 2 kpl USB-power + KB + optio 2 kpl RCA-liitin, Audio -switch

[fn:3] 2x keystone liittimien lukumäärä

[fn:4] Näppäimistön kytkeminen 

[fn:5] Virran syöttö 

* Kommetteja

- Painonappien läpireikä 5mm (min 4.5)
- Kaiuttimen aukko ei ole keskellä
- jrr raspeberry hattu piirilevyn asennusreijät M3:ksi
  - Huom. Raspberry pi asennusreijät 2.5mm --> etsittävä 2.5mm rampamuhvi
- Huom. jatkossa takaseinän kiinnnitys 3mm rampamuhvilla ja M3/30 mm linssikantaruuvilla

[[file:bom/Manufacturing facility overview and pre-drilling instructions - B.pdf][Rampamuhvin mitat ja pilotreijän poraus]]:
- Taulukko https://www.rampa.com/eu/en/Online-Shop/Products/Inserts/
- M3 (ulkohalkaisija 6mm) -> 5mm pora
- M4 (ulkohalkaisija 8mm) -> 6mm pora

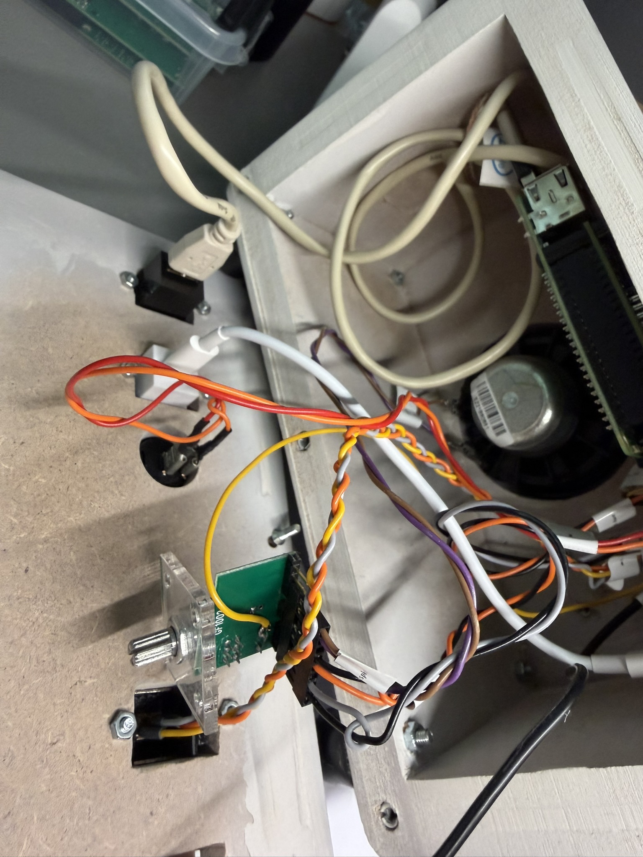
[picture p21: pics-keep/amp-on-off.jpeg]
- Vahvistimen on-off-johtimen kytkentä  

* Fin                                                              :noexport:

** Emacs variables

#+RESULTS:

* Footnotes

# Local Variables:
# time-stamp-line-limit: -8
# time-stamp-start: "Modified:"
# time-stamp-format: "%:y-%02m-%02d.%02H:%02M"
# time-stamp-time-zone: nil
# time-stamp-end: "; # time-stamp"
# eval: (add-hook 'before-save-hook 'time-stamp)
# org-confirm-babel-evaluate: nil
# End:
#
# Muuta
# org-cdlatex-mode: t
# eval: (cdlatex-mode)
#
# Local ebib:
# org-ref-default-bibliography: "./jrr-bom.bib"
# org-ref-bibliography-notes: "./jrr-bom-notes.org"
# org-ref-pdf-directory: "./pdf/"
# org-ref-notes-directory: "."
# bibtex-completion-notes-path: "./jrr-bom-notes.org"
# ebib-preload-bib-files: ("./jrr-bom.bib")
# ebib-notes-file: ("./jrr-bom-notes.org")
# reftex-default-bibliography: ("./jrr-bom.bib")

Modified:2026-07-18.10:29; # time-stamp

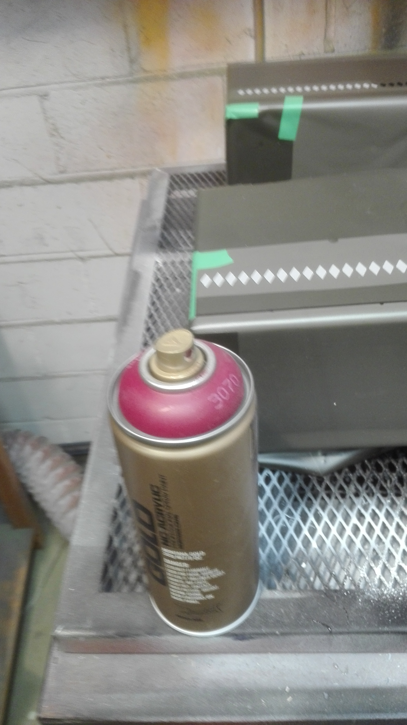
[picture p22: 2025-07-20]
bom/2020-03-10-spraymaali.jpg

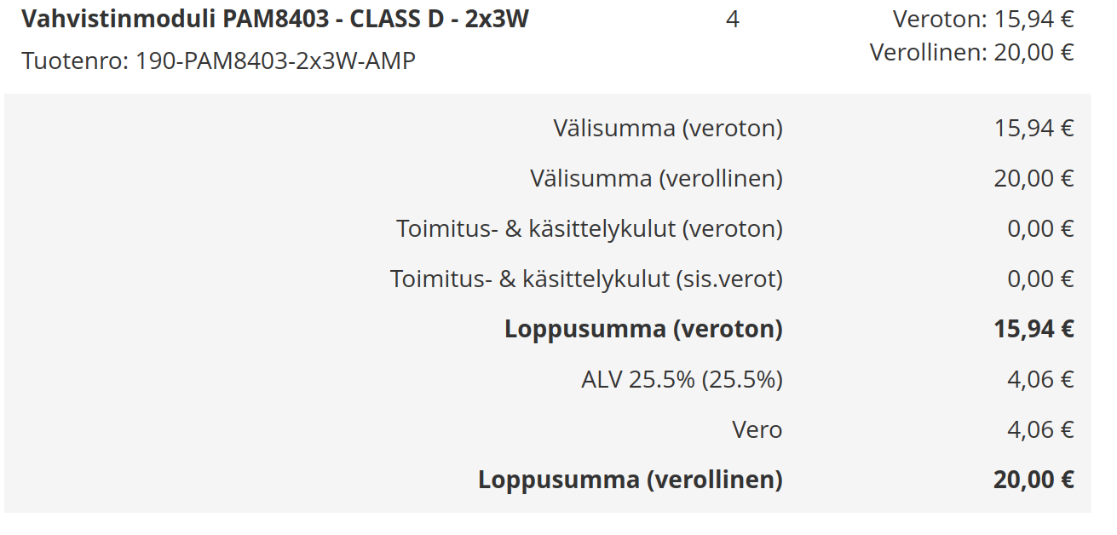
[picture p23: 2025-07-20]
bom/pam8403.png

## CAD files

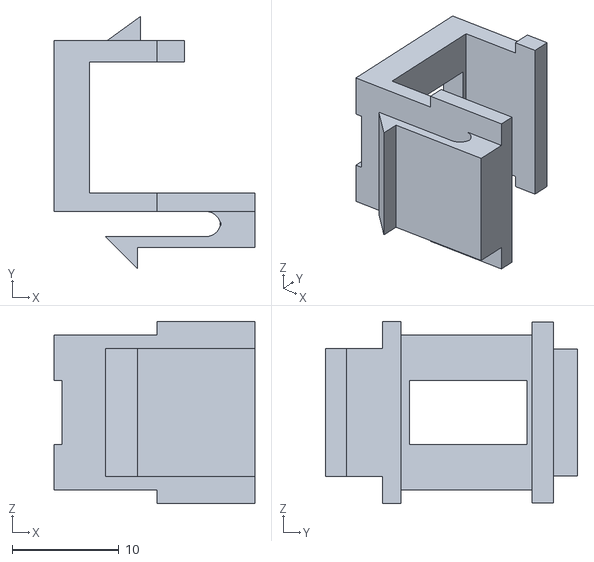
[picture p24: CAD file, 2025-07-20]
cad/3D/keystone-liukukytkin-v10.stl
18.8 x 23.6 x 17.0

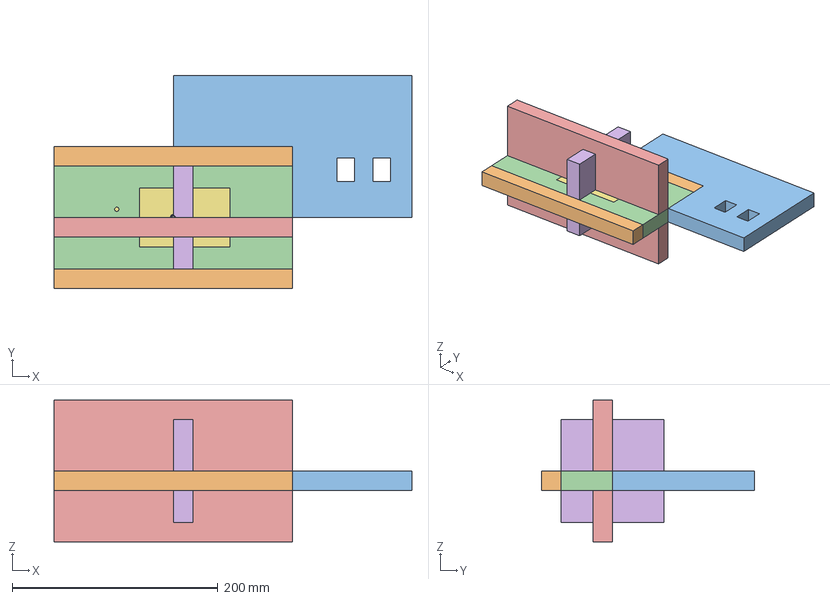
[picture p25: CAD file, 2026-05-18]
cad/jrr5.FCStd
348.0 x 207.0 x 138.0 mm
sivu-aihio
Model-etu-aihio
Model-taka-kansi
Model-katto-aihio
Stock-Pad
Stock-Pad003
Stock
Endmill
Endmill_6mm
Endmill001
Endmill_6mm001
Endmill002
Endmill_6mm002
4mm_20mm_endmill001
4.2mm Drill

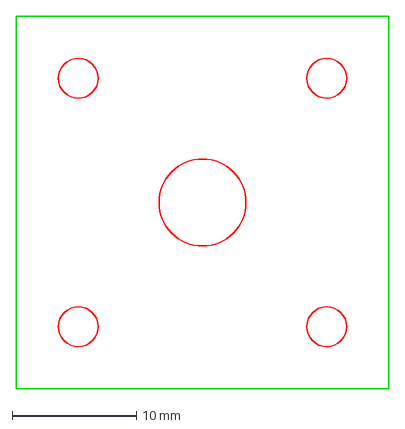
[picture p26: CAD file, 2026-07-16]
cad/laseroinnit/LaseroiPotikkaLevy.dxf
30.0 x 30.0 mm

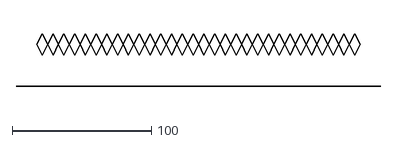
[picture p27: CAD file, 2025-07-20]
cad/sabluunat/JussiSalmiakki.dxf
262.0 x 37.7

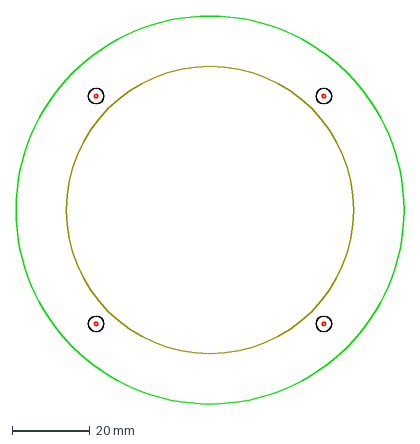
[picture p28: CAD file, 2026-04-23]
cad/laseroinnit/LaseroiKaiutinRengas-sabluuna.dxf
100.0 x 100.0 mm

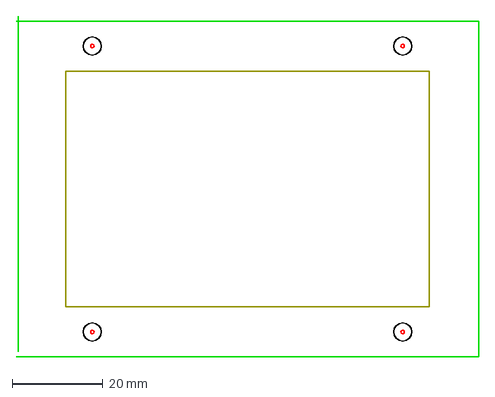
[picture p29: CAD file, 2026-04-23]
cad/laseroinnit/LaserointiNäyttöKehys-sabluuna.dxf
102.0 x 75.1 mm

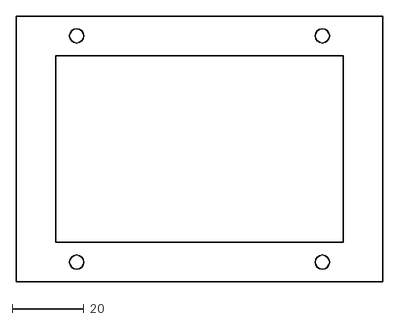
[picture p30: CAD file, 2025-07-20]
cad/laseroinnit/LaserointiNäyttöKehys.dxf
102.0 x 74.0

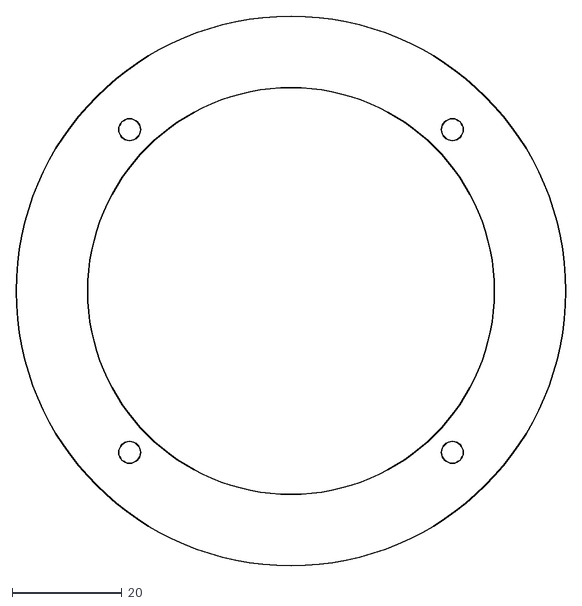
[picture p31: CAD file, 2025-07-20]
cad/laseroinnit/LaseroiKaiutinRengas.dxf
100.0 x 100.0

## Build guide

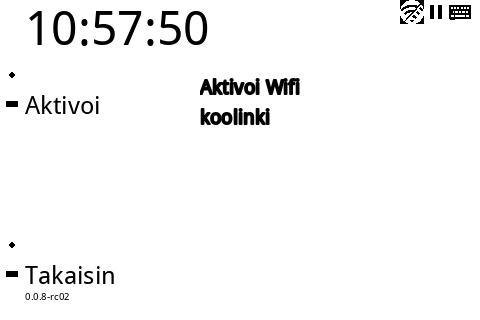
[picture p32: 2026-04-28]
pics-keep/screenshots/jrr-04-wifi-choose-wifi-setup.png

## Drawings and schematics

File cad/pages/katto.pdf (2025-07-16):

# 61 ⁷,5

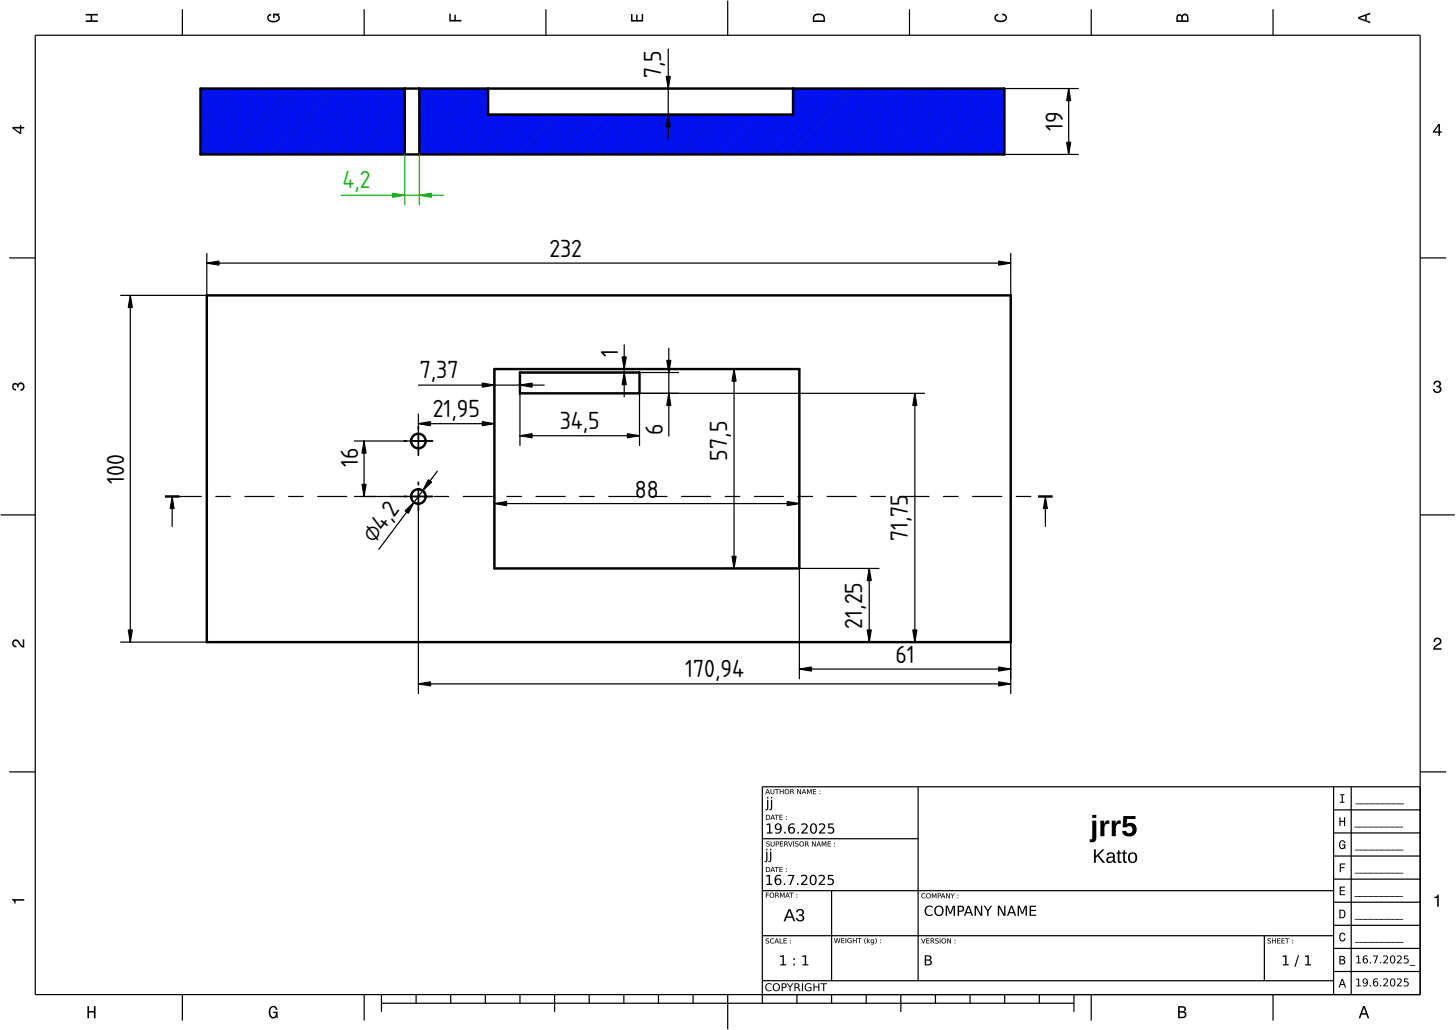
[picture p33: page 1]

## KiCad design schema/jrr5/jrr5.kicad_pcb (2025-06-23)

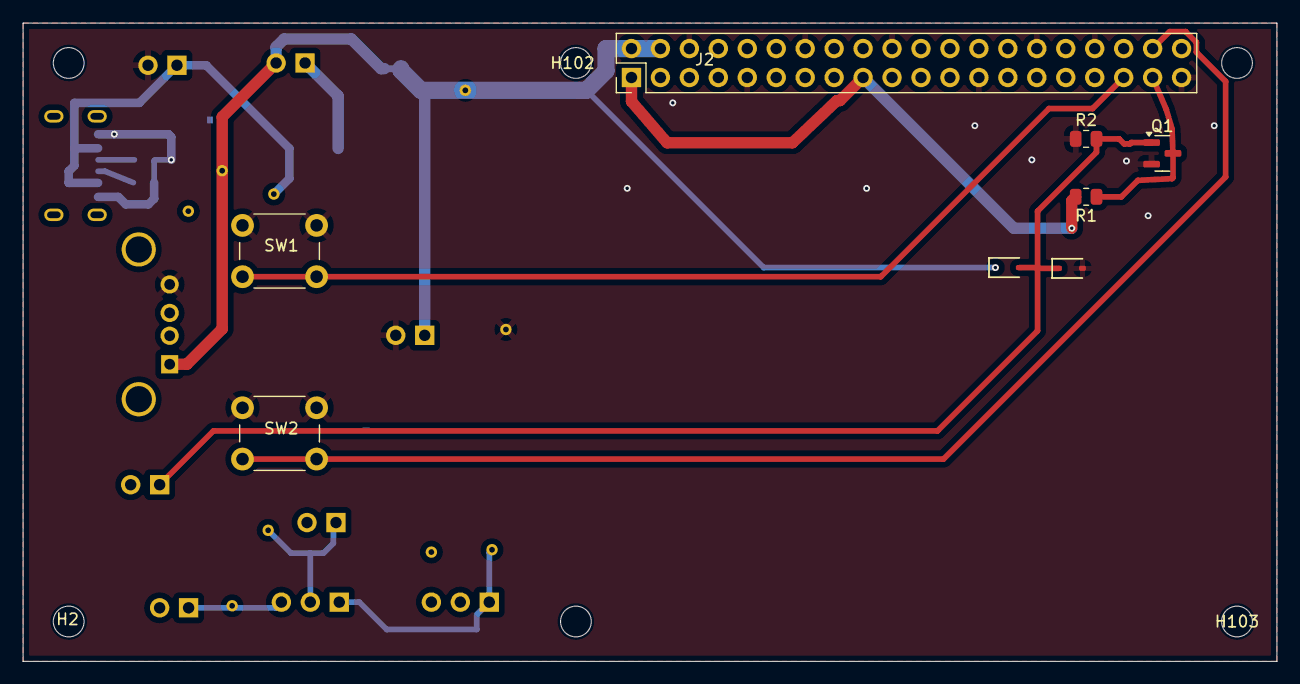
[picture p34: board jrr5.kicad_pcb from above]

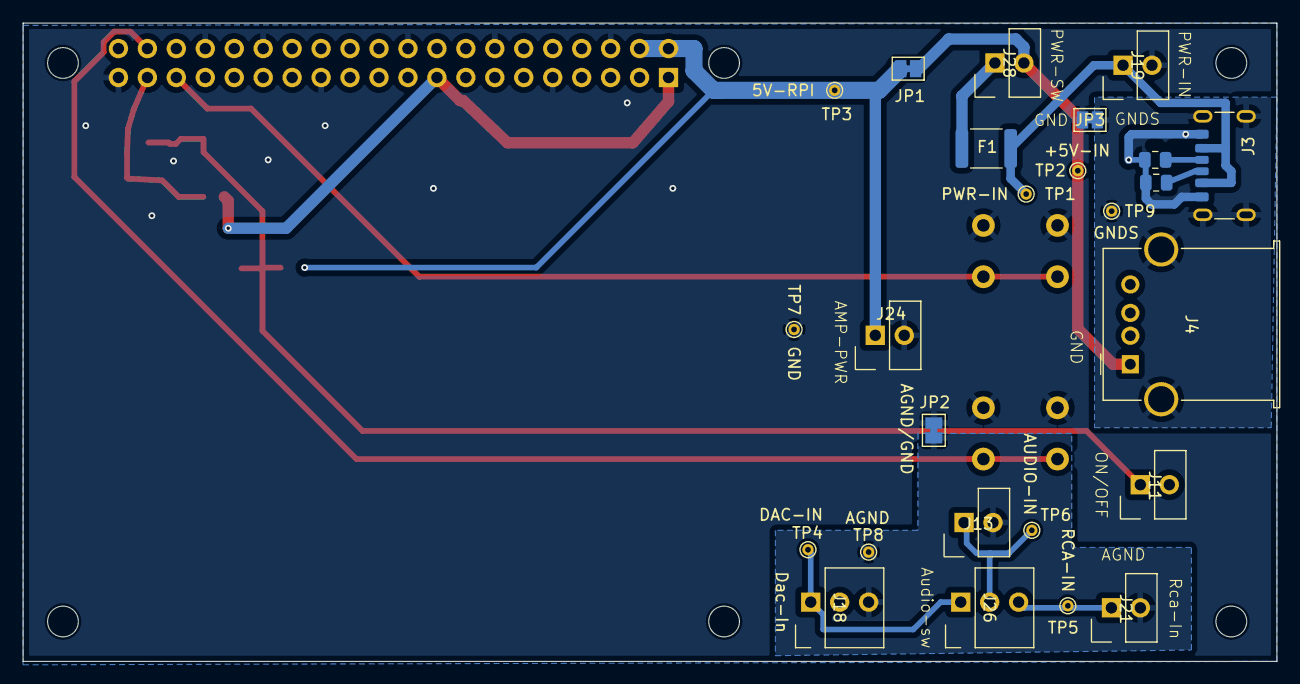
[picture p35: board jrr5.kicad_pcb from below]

Board: 2 copper layers, 110.0 x 56.0 mm, 39 parts (25 on the bottom side), 17 nets.

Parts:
D1, D2: Schottky,15mA; D_SOD-323
F1: 1.1A/polyfuse; Fuse_1812_4532Metric
H1, H2, H101, H102, H103, H104: MountingHole; MountingHole_2.7mm_M2.5
J2: Raspberry_Pi_2_3_GPIO; PinHeader_2x20_P2.54mm_Vertical
J3: USB-C,6Pin; USB_C_Receptacle_GCT_USB4125-xx-x-0190_6P_TopMnt_Horizontal
J4: USB-Afm,THT; USB_A_Molex_67643_Horizontal
J11, J13, J19, J21, J24, J28: Wafer,1x2,m; Wafer_1x02_P2.54mm_Vertical_male
J18, J26: Wafer,1x3,m; Wafer_1x03_P2.54mm_Vertical_male
JP1: 5V-IN/5V-RPI; SolderJumper-2_P1.3mm_Bridged_Pad1.0x1.5mm
JP2: AGND/GND; SolderJumper-2_P1.3mm_Bridged_Pad1.0x1.5mm
JP3: GND/SGND; SolderJumper-2_P1.3mm_Bridged_Pad1.0x1.5mm
Q1: BSS138; SOT-23
R1, R2: 100k; R_0805_2012Metric
R3, R4: 5k1; R_0805_2012Metric
SW1, SW2: SW_PUSH_THT_6mm; SW_PUSH_6mm
TP1: PWR-IN; TestPoint_THTPad_D1.0mm_Drill0.5mm
TP2: +5V-IN; TestPoint_THTPad_D1.0mm_Drill0.5mm
TP3: 5V-RPI; TestPoint_THTPad_D1.0mm_Drill0.5mm
TP4: Dac-In; TestPoint_THTPad_D1.0mm_Drill0.5mm
TP5: RCA-IN; TestPoint_THTPad_D1.0mm_Drill0.5mm
TP6: AUDIO-IN; TestPoint_THTPad_D1.0mm_Drill0.5mm
TP7: GND; TestPoint_THTPad_D1.0mm_Drill0.5mm
TP8: AGND; TestPoint_THTPad_D1.0mm_Drill0.5mm
TP9: GNDS; TestPoint_THTPad_D1.0mm_Drill0.5mm

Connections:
+3V3: J2.1 (3V3), J2.17 (3V3), R1.2
+5V-IN: J4.1 (VBUS), J28.2, JP1.1 (A), TP2.1
+5V-RPI: D1.1, J2.2 (5V), J2.4 (5V), J24.1, JP1.2 (B), TP3.1
AGND: J13.2, J18.3, J21.2, JP2.1 (A), TP8.1
DAC-IN: J18.1, J26.1, TP4.1
GND: D2.2, J2.6 (GND), J2.9 (GND), J2.14 (GND), J2.20 (GND), J2.25 (GND), J2.30 (GND), J2.34 (GND), J2.39 (GND), J3.A12 (GND), J3.B12 (GND), J4.4 (GND), J19.2, J24.2, JP2.2 (B), JP3.1 (A), Q1.2 (S), R2.1, R3.2, R4.2, SW1.1, SW2.1, TP7.1
GNDS: J3.S1 (SHIELD), J4.5 (Shield), JP3.2 (B), TP9.1
unnamed: J2.35 (GPIO19/MISO1), SW1.2
unnamed: J2.38 (GPIO20/MOSI1), SW2.2
unnamed: J2.37 (GPIO26), Q1.3 (D), R1.1
unnamed: J3.A5 (CC1), R3.1
unnamed: J3.B5 (CC2), R4.1
unnamed: F1.2, J28.1
ON/OFF: D1.2, D2.1, J11.1, Q1.1 (G), R2.2
PWR-IN: F1.1, J3.A9 (VBUS), J3.B9 (VBUS), J19.1, TP1.1
RCA-IN: J21.1, J26.3, TP5.1
audio-in: J13.1, J26.2, TP6.1

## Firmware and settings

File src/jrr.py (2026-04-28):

"""Main module parses command line options and dispatched commands.

"""

import argparse
import sys

import logging

from .constants import (CLI)
from .jrr_radio import radio_main
from .jrr_converter import converter_main
from .config import app_config

logger = logging.getLogger(__name__)


# ------------------------------------------------------------------
# Command line arguments

# https://stackoverflow.com/questions/20094215/argparse-subparser-monolithic-help-output

class _HelpAction(argparse._HelpAction):
    """Sub parser helps"""

    def __call__(self, parser, namespace, values, option_string=None):
        parser.print_help()

        # retrieve subparsers from parser
        subparsers_actions = [
            action for action in parser._actions
            if isinstance(action, argparse._SubParsersAction)]
        # there will probably only be one subparser_action,
        # but better save than sorry
        for subparsers_action in subparsers_actions:
            # get all subparsers and print help
            for choice, subparser in subparsers_action.choices.items():
                print(f"Command '{choice}'")
                print(subparser.format_help())

        parser.exit()


def commandLineParser() -> argparse.ArgumentParser:
    """Return command line parser.

    laturi [options] [command]

    Options:

    -v                : versbosity

    Commands:

    kan1              : the simples kan model
    """

    parser = argparse.ArgumentParser(add_help=False)
    parser.add_argument("-v", "--verbose", action="count", default=0)
    parser.add_argument("--disable_existing_loggers", help="Default True (=imported loggers disabled)",
                        action="store_false")
    parser.add_argument('--help', action=_HelpAction,
                        help='help for help if you need some help')
    subparsers = parser.add_subparsers(help='Commands', dest="command")

    # --------------------
    # Radio
    radio_parser = subparsers.add_parser(
        CLI.CMD_RADIO, help="Run radio daemon")
    # radio_parser.add_argument(
    #     CLI.OPT_SYSTEM_HALT, action="store_false", default=True,
    #     help="call 'sudo halt' on shutdown knob",
    # )
    radio_parser.add_argument(
        CLI.OPT_CONSOLE_ALL_LINES, action="store_true", default=False,
        help="Output all journalctl lines to console (default no)",
    )
    radio_parser.add_argument(
        CLI.OPT_ALLOW_SCREENSHOTS, action="store_true", default=False,
        help="Allow screenshots (default no)",
    )

    # --------------------
    # Icon converter

    icon_cnv_parser = subparsers.add_parser(
        CLI.CMD_ICON_CONVERT, help="Convert icons")
    icon_cnv_parser.add_argument(
        CLI.OPT_ICON_SOURCE, type=str, default=CLI.DEFAULT_ICON_SOURCE_DIR,
        help=f"Icon images from  '{CLI.DEFAULT_ICON_SOURCE_DIR}')",
    )
    icon_cnv_parser.add_argument(
        CLI.OPT_ICON_TARGET, type=str, default=CLI.DEFAULT_ICON_DIR,
        help=f"Icon images to '{CLI.DEFAULT_ICON_DIR}')",
    )
    icon_cnv_parser.add_argument(
        CLI.OPT_STREAMING_ICON_WIDTH, type=str, default=CLI.DEFAULT_STREAMING_ICON_WIDTH,
        help=f"Display width '{CLI.DEFAULT_STREAMING_ICON_WIDTH}')",
    )
    icon_cnv_parser.add_argument(
        CLI.OPT_STREAMING_ICON_HEIGHT, type=str, default=CLI.DEFAULT_STREAMING_ICON_HEIGHT,
        help=f"Display height '{CLI.DEFAULT_STREAMING_ICON_HEIGHT}')",
    )
    icon_cnv_parser.add_argument(
        "--yes", "-y", action="store_true", default=False,
        help=f"Override '(default = False')",
    )
    icon_cnv_parser.add_argument(
        "--bw", action="store_true", default=False,
        help=f"Black and white '(default = False = color')",
    )

    return parser


def commandLineArgruments(args):
    """Process command line argurments"""
    parser = commandLineParser()
    parsed_args = parser.parse_args(args)

    # Init singleton config
    app_config.cliArgs = parsed_args

    return parsed_args

# ------------------------------------------------------------------
# main entry


def main(args):
    """Parse command line and dispatch commands."""

    parsed = commandLineArgruments(args)
    # Set output log level
    # logging.basicConfig(level=logging.DEBUG)
    levels = [logging.WARNING, logging.INFO, logging.DEBUG]
    logging.basicConfig(
        level=levels[min(parsed.verbose, len(levels)-1)],
        format='%(asctime)s,%(msecs)03d %(levelname)-8s [%(filename)s:%(lineno)d] %(message)s',
        datefmt='%Y-%m-%d:%H:%M:%S',
    )
    logger.info("logging.level: %s", logger.level)

    if parsed.command == CLI.CMD_RADIO:
        radio_main(parsed)
    elif parsed.command == CLI.CMD_ICON_CONVERT:
        # converter_main(parsed)
        converter_main(
            image_dir=parsed.icons_from,
            icon_dir=parsed.icons_to,
            yes=parsed.yes,
            width=parsed.width,
            height=parsed.height,
            bw=parsed.bw
        )


# if __name__ == "__main__":
#     args = sys.argv[1:]
#     main(args)

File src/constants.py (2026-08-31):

"""
Constants module
"""
from pathlib import Path
from enum import Enum
import os


class CLI:
    """Configure command line"""

    # Commands
    CMD_RADIO = "radio"
    CMD_ICON_CONVERT = "convert"

    # CLI options (for radio streamer)
    # OPT_SYSTEM_HALT = "--system-halt"
    OPT_CONSOLE_ALL_LINES = "--all-lines"
    OPT_ALLOW_SCREENSHOTS = "--screen-shots"

    # CLI options (for icon converter)
    OPT_ICON_SOURCE = "--icons-from"
    OPT_ICON_TARGET = "--icons-to"
    OPT_STREAMING_ICON_WIDTH = "--width"
    OPT_STREAMING_ICON_HEIGHT = "--height"

    # DEFAULT_STREAMING_ICON_WIDTH = 96             # streamer icon width
    DEFAULT_STREAMING_ICON_WIDTH = 200             # streamer icon width
    DEFAULT_STREAMING_ICON_HEIGHT = DEFAULT_STREAMING_ICON_WIDTH
    # icon size (w,h) in sprite (divisible by 8)
    DEFAULT_SPRITE_ICON_SIZE = 24

    # Directories and files
    DEFAULT_ICON_SOURCE_DIR = Path.home() / ".icons"        # input for icon conversion
    # DEFAULT_ICON_DIR = os.path.join(
    #     os.path.dirname(__file__), "../cnf", "icons")
    # DEFAULT_STREAM_YAML = os.path.join(
    #     os.path.dirname(__file__), "../cnf", "jrr_streams.yaml")
    DEFAULT_ICON_DIR = Path().home() / "cnf/icons"
    DEFAULT_STREAM_YAML = Path().home() / "cnf/jrr_streams.yaml"

    FACTORY_ICON_DIR = os.path.join(
        os.path.dirname(__file__), "cnf", "icons")
    FACTORY_STREAM_YAML = os.path.join(
        os.path.dirname(__file__), "cnf", "jrr_streams.yaml")

    # Time and time out managenemtn
    DEFAULT_CLOCK_TICK = 10                        # secs betweeen CLOCK_TICK messages
    # TODO: display put to sleep after timeout
    DEFAULT_INACTIVITY_TIMEOUT = 30

    # Screeen configuration
    DEFAULT_FULL_UPDATE_LIMIT = 10                 # full update after this limit


class TOPICS:
    """Publish/subscrice topics and messages"""

    # Unique topic names in publish/subscribe pattern
    CONTROL = "ctrl"                               # control channel
    DEFAULT = "default"                            # default channel TODO remove
    SCREEN = "screen"                              # e-paper display
    STREAMER = "streamer"                          # audio streamer
    NETWORK_MONITOR = "network"                    # network monitor coro control
    KEYBOARD = "kb"

    # Unique message names (grouped within *_MESSAGES just for
    # documentation purposes)
    class COMMON_MESSAGES:
        """Common messages in any -topic"""

        EXIT = "exit"                              # close coro on EXIT message
        DELAY = "delay"                            # async sleep
        CLOCK_TICK = "tick"                        # clock ticks
        PING = "ping"                              # are you there

    class GPIO_MESSAGES:
        """Messages in GPIO."""
        GPIO = "gpio"                              # button pressed

    class KEYBOARD_MESSAGES:
        """Messages in GPIO."""
        KEY = "key"                                # key pressed
        START = "start-kb"                         # start reading keyboard
        STOP = "stop-kb"                           # stop reading keyboard
        STATUS = "kb-status"                       # report keyboard status

    class CONTROL_MESSAGES:
        """Messages in CONTROL -topic."""
        REBOOT = "REBOOT"                          # close app (and hope it gets restarted)
        HALT = "HALT"                              # halt machine
        HALT_ACK = "HALT-ACK"                      # halt acknowneded
        # streame (runner) status reply
        STREAMER_STATUS_REPLY = "status_reply"

    class NETWORK_MESSAGES:
        STATUS = "nw-status"

    class STREAMER_MESSAGES:
        """Messages in STREAMER -topic"""
        START = "start_stream"                     # start streaming
        STOP = "stop_stream"                       # stop streaming
        # query stream (runner) status
        STATUS_QUERY = "status_stream"

        STREAM_TYPE_NETWORK = "stream"             # jrr_streamer.sh command stream
        STREAM_TYPE_CHIRP = "chirp"                # jrr_streamer.sh command chrip
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

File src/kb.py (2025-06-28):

"""Keyboard utilities."""

import sys
import evdev
import logging
import asyncio
from typing import Tuple

logger = logging.getLogger(__name__)

BS = "<BACKSPACE>"


def _list_devices():
    # List all input devices
    devices = [evdev.InputDevice(path) for path in evdev.list_devices()]
    # print(f"{devices=}")
    return devices


def find_keyboard(keyboard_name) -> evdev.InputDevice:
    """Find your input device with 'keyboard_name'."""
    #
    devices = _list_devices()
    kb_dev = None
    for device in devices:
        logger.info("device.path='%s', device.name=%s, device.phys=%s, looking for '%s'",
                    device.path, device.name, device.phys, keyboard_name)
        if (device.name == keyboard_name or
                device.name.endswith(keyboard_name)
            ):
            kb_dev = device
            logger.info("found keyboard kb_dev='%s'", kb_dev)

    logger.info("Found: kb_dev='%s'", kb_dev)
    return kb_dev

# ------------------------------------------------------------------
# async generators


async def read_raw_keyboard_gen(keyboard: evdev.InputDevice):
    """Generator yielding key events for key presson on 'keyboard'."""
    async for event in keyboard.async_read_loop():
        if event.type == evdev.ecodes.EV_KEY:
            key_event = evdev.categorize(event)
            # print(f"{type(key_event)=}, {key_event=}")
            # print(f"{key_event.scancode=}")
            # print(f"{key_event.keycode=}")
            # print(f"{key_event.key_up=}")
            # print(f"{key_event.key_down=}")
            # print(f"{key_event.key_hold=}")

            yield key_event


async def read_keyboard_gen(keyboard: evdev.InputDevice):
    """Generator yielding character presses on QWERTY 'keyboard'.

    Kudos: ChatGPT
    """

    shift_pressed = False  # Track shift state for capital letters and special characters

    # Define a mapping for special characters when shift is pressed
    shift_map = {
        "1": "!",
        "2": "@",
        "3": "#",
        "4": "$",
        "5": "%",
        "6": "^",
        "7": "&",
        "8": "*",
        "9": "(",
        "0": ")",
        "-": "_",
        "=": "+",
        "[": "{",
        "]": "}",
        "\\": "|",
        ";": ":",
        "'": "\"",
        ",": "<",
        ".": ">",
        "/": "?",
        "`": "~",
        "MINUS": "_",
        "EQUAL": "+",
    }

    async for key_event in read_raw_keyboard_gen(keyboard=keyboard):
        # key_event = evdev.KeyEvent(event)  # Categorize the event
        key_code = key_event.keycode.replace("KEY_", "")  # Get the key name
        # logger.debug("key_code='%s'", key_code)

        if key_event.keystate == evdev.KeyEvent.key_down:  # Key pressed
            if key_code in ["LEFTSHIFT", "RIGHTSHIFT"]:
                shift_pressed = True
            elif key_code.isalpha() and len(key_code) == 1:  # Alphabet keys
                if shift_pressed:
                    kb_character = key_code.upper()  # Uppercase letters
                else:
                    kb_character = key_code.lower()  # Lowercase letters
                yield kb_character
            elif key_code.isdigit() or key_code in shift_map.keys():  # Numbers and symbols
                if shift_pressed and key_code in shift_map:
                    # Shift-modified character
                    kb_character = shift_map[key_code]
                else:
                    kb_character = key_code
                yield kb_character
            else:
                # Handle other keys (like space, enter, etc.)
                if key_code == "SPACE":
                    kb_character = " "
                elif key_code == "ENTER":
                    kb_character = "\n"
                else:
                    kb_character = f"<{key_code}>"
                yield kb_character

        elif key_event.keystate == evdev.KeyEvent.key_up:  # Key released
            if key_code in ["LEFTSHIFT", "RIGHTSHIFT"]:
                shift_pressed = False  # Reset shift state when shift is released

# ------------------------------------------------------------------.
# Operations on keyboard buffer


def edit_buffer(buf: str, key: str, pos: int | None = None) -> Tuple[str, int]:
    """Add 'key' to buffer 'buf' in position 'pos'.

    :pos: cursor position where to add next character, default None =
    end of buffer

    Non characters (len(key) > ) are special keys. When 'key'
    - BS: buffer content in 'pos' (=remove element bus[pos])

    :return:

    """

    def adjust_pos(pos, buf):

        if pos is None:
            pos = len(buf)
        pos = pos if pos <= len(buf) else len(buf)
        pos = pos if pos >= 0 else 0
        return pos
    pos = adjust_pos(pos, buf)

    print(f"{pos=}, {buf=}")

    if key == BS:
        # remove char in pos
        buf = buf[0:pos-1] + buf[pos:]
        pos -= 1

    pos = adjust_pos(pos, buf)
    return buf, pos


def split_buffer(buf: str, line_limit: int = 20) -> str:
    """Split  'buf' to line chunks of lenght 'line_limit' ."""

    parts = [buf[i:i+line_limit] for i in range(0, len(buf), line_limit)]
    return "\n".join(parts)

# ------------------------------------------------------------------.
# async routines


# async def read_raw_keyboard(keyboard: evdev.InputDevice):
#     """Generator yielding key events for key presson on 'keyboard'."""
#     event = await keyboard.async_read()
#     if event.type == evdev.ecodes.EV_KEY:
#         key_event = evdev.categorize(event)
#         # print(f"{type(key_event)=}, {key_event=}")
#         # print(f"{key_event.scancode=}")
#         # print(f"{key_event.keycode=}")
#         # print(f"{key_event.key_up=}")
#         # print(f"{key_event.key_down=}")
#         # print(f"{key_event.key_hold=}")

#         return key_event


# async def read_keyboard(keyboard: evdev.InputDevice):
#     """Generator yielding character presses on QWERTY 'keyboard'.

#     Kudos: ChatGPT
#     """

#     shift_pressed = False  # Track shift state for capital letters and special characters

#     # Define a mapping for special characters when shift is pressed
#     shift_map = {
#         "1": "!",
#         "2": "@",
#         "3": "#",
#         "4": "$",
#         "5": "%",
#         "6": "^",
#         "7": "&",
#         "8": "*",
#         "9": "(",
#         "0": ")",
#         "-": "_",
#         "=": "+",
#         "[": "{",
#         "]": "}",
#         "\\": "|",
#         ";": ":",
#         "'": "\"",
#         ",": "<",
#         ".": ">",
#         "/": "?",
#         "`": "~",
#         "MINUS": "_",
#         "EQUAL": "+",
#     }

#     while True:
#         key_event = await read_raw_keyboard(keyboard=keyboard)
#         # key_event = evdev.KeyEvent(event)  # Categorize the event
#         key_code = key_event.keycode.replace("KEY_", "")  # Get the key name
#         # logger.debug("key_code='%s'", key_code)
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

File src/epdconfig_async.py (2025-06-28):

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
# ------------------------------------------------------------------
# Modified from  Waveshare edp demo from https://github.com/waveshare/e-Paper.git based on 'lib/waveshare_epd/epdconfig.py'
#
# Instruction in https://www.waveshare.com/wiki/2.13inch_e-Paper_HAT_Manual#Working_With_Raspberry_Pi


import os
import logging
import sys
import time
import subprocess

from ctypes import *

logger = logging.getLogger(__name__)


class RaspberryPi:
    # Pin definition
    RST_PIN = 17
    DC_PIN = 25
    CS_PIN = 8
    BUSY_PIN = 24
    PWR_PIN = 18
    MOSI_PIN = 10
    SCLK_PIN = 11

    def __init__(self):
        import spidev
        import gpiozero

        self.SPI = spidev.SpiDev()
        self.GPIO_RST_PIN = gpiozero.LED(self.RST_PIN)
        self.GPIO_DC_PIN = gpiozero.LED(self.DC_PIN)
        # self.GPIO_CS_PIN     = gpiozero.LED(self.CS_PIN)
        self.GPIO_PWR_PIN = gpiozero.LED(self.PWR_PIN)
        self.GPIO_BUSY_PIN = gpiozero.Button(self.BUSY_PIN, pull_up=False)

    def digital_write(self, pin, value):
        if pin == self.RST_PIN:
            if value:
                self.GPIO_RST_PIN.on()
            else:
                self.GPIO_RST_PIN.off()
        elif pin == self.DC_PIN:
            if value:
                self.GPIO_DC_PIN.on()
            else:
                self.GPIO_DC_PIN.off()
        # elif pin == self.CS_PIN:
        #     if value:
        #         self.GPIO_CS_PIN.on()
        #     else:
        #         self.GPIO_CS_PIN.off()
        elif pin == self.PWR_PIN:
            if value:
                self.GPIO_PWR_PIN.on()
            else:
                self.GPIO_PWR_PIN.off()

    def digital_read(self, pin):
        if pin == self.BUSY_PIN:
            return self.GPIO_BUSY_PIN.value
        elif pin == self.RST_PIN:
            return self.RST_PIN.value
        elif pin == self.DC_PIN:
            return self.DC_PIN.value
        # elif pin == self.CS_PIN:
        #     return self.CS_PIN.value
        elif pin == self.PWR_PIN:
            return self.PWR_PIN.value

    def delay_ms(self, delaytime):
        time.sleep(delaytime / 1000.0)

    def spi_writebyte(self, data):
        self.SPI.writebytes(data)

    def spi_writebyte2(self, data):
        self.SPI.writebytes2(data)

    def DEV_SPI_write(self, data):
        self.DEV_SPI.DEV_SPI_SendData(data)

    def DEV_SPI_nwrite(self, data):
        self.DEV_SPI.DEV_SPI_SendnData(data)

    def DEV_SPI_read(self):
        return self.DEV_SPI.DEV_SPI_ReadData()

    def module_init(self, cleanup=False):
        self.GPIO_PWR_PIN.on()

        if cleanup:
            find_dirs = [
                os.path.dirname(os.path.realpath(__file__)),
                '/usr/local/lib',
                '/usr/lib',
            ]
            self.DEV_SPI = None
            for find_dir in find_dirs:
                val = int(os.popen('getconf LONG_BIT').read())
                logging.debug("System is %d bit" % val)
                if val == 64:
                    so_filename = os.path.join(find_dir, 'DEV_Config_64.so')
                else:
                    so_filename = os.path.join(find_dir, 'DEV_Config_32.so')
                if os.path.exists(so_filename):
                    self.DEV_SPI = CDLL(so_filename)
                    break
            if self.DEV_SPI is None:
                RuntimeError('Cannot find DEV_Config.so')

            self.DEV_SPI.DEV_Module_Init()

        else:
            # SPI device, bus = 0, device = 0
            self.SPI.open(0, 0)
            self.SPI.max_speed_hz = 4000000
            self.SPI.mode = 0b00
        return 0

    def module_exit(self, cleanup=False):
        logger.debug("spi end")
        self.SPI.close()

        self.GPIO_RST_PIN.off()
        self.GPIO_DC_PIN.off()
        self.GPIO_PWR_PIN.off()
        logger.debug("close 5V, Module enters 0 power consumption ...")

        if cleanup:
            self.GPIO_RST_PIN.close()
            self.GPIO_DC_PIN.close()
            # self.GPIO_CS_PIN.close()
            self.GPIO_PWR_PIN.close()
            self.GPIO_BUSY_PIN.close()


# class JetsonNano:
#     # Pin definition
#     RST_PIN  = 17
#     DC_PIN   = 25
#     CS_PIN   = 8
#     BUSY_PIN = 24
#     PWR_PIN  = 18

#     def __init__(self):
#         import ctypes
#         find_dirs = [
#             os.path.dirname(os.path.realpath(__file__)),
#             '/usr/local/lib',
#             '/usr/lib',
#         ]
#         self.SPI = None
#         for find_dir in find_dirs:
#             so_filename = os.path.join(find_dir, 'sysfs_software_spi.so')
#             if os.path.exists(so_filename):
#                 self.SPI = ctypes.cdll.LoadLibrary(so_filename)
#                 break
#         if self.SPI is None:
#             raise RuntimeError('Cannot find sysfs_software_spi.so')

#         import Jetson.GPIO
#         self.GPIO = Jetson.GPIO

#     def digital_write(self, pin, value):
#         self.GPIO.output(pin, value)
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

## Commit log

2025-06-18 cad added
    [jrr5.FCStd, jrr5.kicad_pcb, jrr5.kicad_sch]
2025-06-19 katon aukkojen mitoitus
    [jrr5.FCStd]
2025-06-23 jrr5-E order from JLCPCB
    [jrr5.FCStd, jrr5.kicad_pcb]
2025-07-03 0.0.4-beta1: reboot on firmware activation
    [constants.py, firmware.py, jrr_radio.py]
2025-07-03 fix : kanavien aktiointi
    [constants.py, jrr_radio.py]
2025-07-16 milling of the roof -> issues
    [jrr5.FCStd]
2025-07-16 Jyrsintäohjeet, katon jyrsintä simuloitu, muut tarkistettu
    [jrr5.FCStd]
2025-07-20 cad, bom added
    [JussiSalmiakki.dxf, LaseroiKaiutinRengas.dxf, LaseroiPotikkaLevy.dxf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]
2025-07-20 JRR-CAD-8: katto-01-nappainreijat-pora.ngc
    [jrr5.FCStd]
2026-04-14 JRR-DEV-001: Alsa volume limit -fixed
    [streamer_coro.py]
2026-04-19 JRR-CAD-10, JRR-CAD-11, katon jyrsintä
    [jrr5.FCStd]
2026-04-19 JRR-14: R1/R2 100k->10k
    [jrr5.kicad_sch]
2026-04-23 Jyrsintä 2026-04
    [LaseroiKaiutinRengas-sabluuna.dxf, LaserointiNäyttöKehys-sabluuna.dxf, jrr5.FCStd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]
2026-04-24 JRR-CAD-13: vertical speed increased
2026-07-17 fix console not working, keybord not read
    [gpio_coro.py, jrr_radio.py, kb_coro.py]

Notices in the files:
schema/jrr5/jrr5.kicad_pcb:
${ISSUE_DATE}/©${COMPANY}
